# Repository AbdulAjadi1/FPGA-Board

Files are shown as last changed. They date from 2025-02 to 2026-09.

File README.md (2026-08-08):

# Custom Zynq FPGA Development Board

A custom-designed 8-layer FPGA development board based on the Xilinx Zynq-7000 SoC, featuring DDR3 memory, high-speed interfaces, and multi-rail power architecture. Designed from schematic through PCB layout and hardware bring-up.

---

<h2>🎥 FPGA Board Overview Demo</h2>
<a href="https://youtu.be/t4U1Dk0gFow">
  
</a>

<h2>🔬 Full DDR3 Bring-Up Walkthrough (Vivado → Vitis)</h2>
<a href="https://www.youtube.com/watch?v=clUkRelldes">
  
</a>

<h2>💾 QSPI Flash Bring-Up Demo</h2>
<a href="https://www.youtube.com/watch?v=BxZh9-KaFNE">
  
</a>

<h2>🔌 UART Using EMIO and DDR3 test</h2>
<a href="https://www.youtube.com/watch?v=delrs5nIDdQ">
  
</a>

---

<p align="center">
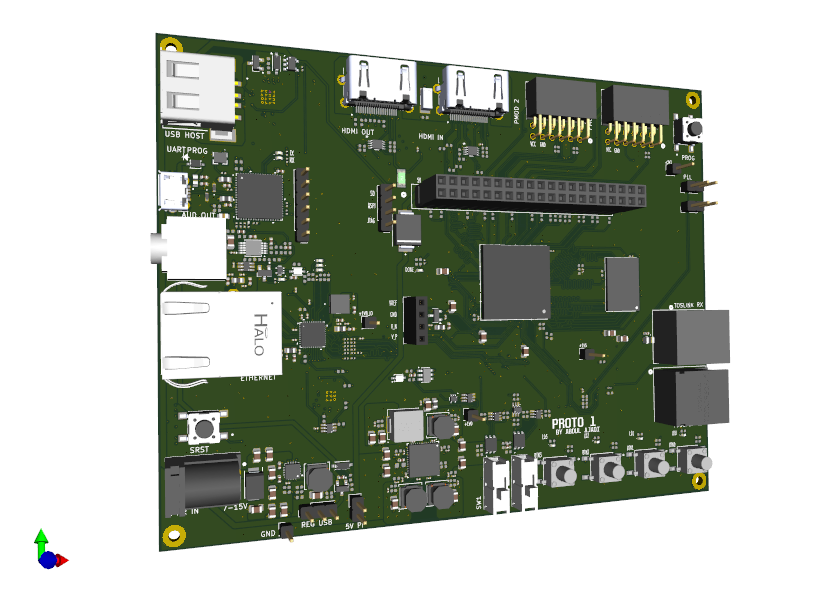
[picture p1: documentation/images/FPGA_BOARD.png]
FPGA Board 3D Render
  
</p>

**Custom Zynq-7000 FPGA Development Board**

**Overview**

This project is a custom FPGA development board inspired by the Digilent Arty Z7 platform, designed around the Xilinx Zynq-7000 SoC. The board serves as a general-purpose hardware development and learning platform, with an emphasis on FPGA and ARM (PS/PL) co-design, sound, power and signal-integrity practices, manufacturable industry-style PCB layout, and realistic interfaces commonly used in embedded and FPGA systems. The design is intended for advanced manufacturing and assembly at JLCPCB.

The project targets entry-level to junior FPGA and hardware engineering roles and focuses on demonstrating practical, board-level engineering decisions rather than a minimal breakout-style design.

**Project Status:**

## 🧪 Bring-Up & Validation

- ✅ DDR3 bring-up completed with successful memory test execution  
- ✅ QSPI flash configuration verified  
- ✅ FTDI USB-to-JTAG interface operational for programming and debug  
- ✅ Multi-rail power system validated 
- ✅ AXI GPIO controlling user LEDs and RGB LEDs confirmed  
- ✅ PS clocking and PLL configuration stable

**KEY FEATURES:**
- Xilinx Zynq-7000 SoC (Z7-20 / XC7Z020 class)
- DDR3 SDRAM (PS memory)
- HDMI interface (video output)
- Ethernet PHY (10/100/1000 Mbps)
- USB Host
- USB-JTAG interface
- SPDIF / TOSLINK interface
- QSPI Flash (boot storage)
- microSD card support
- PMOD / GPIO headers
- 40-pin Raspberry Pi interface
- On-board oscillators for PS and PL
- User LEDs, buttons, and switches
- Multi-rail power tree with switching regulators and LDOs

**DESIGN GOALS:**
- Follow Xilinx Zynq hardware design guidelines
- Implement correct decoupling, grounding, and plane usage
- Use controlled-impedance routing for high-speed interfaces
- Be compatible with low-cost PCB manufacturing and assembly
- Serve as a portfolio-quality hardware project

**HARDWARE ARCHITECTURE:**
- Zynq SoC
- ARM Cortex-A9 Processing System (PS)
- Programmable Logic (PL) fabric
- PS-to-PL interconnect exposed for custom designs
- Boot modes supported via QSPI / SD Memory
- DDR3 SDRAM connected to the PS:
- Length-matched address, control, and data groups
- Proper VREF routing and decoupling

**POWER TREE:**

**Input Sources:**

- 7-15V Barrel jack
- Raspberry pi 5V
- USB 5V

**Generated rails:**

- 1.0 V (FPGA core)

- 1.5 V (DDR3)

- 1.8 V (aux, IO)

- 3.3 V (IO and peripherals)

**PCB DESIGN DETAILS:**

- 8-layer PCB stackup

- Dedicated solid ground planeS

- Power planes for core rails

- Signal layers for controlled routing

- Thermal via stitching under FPGA ground regions

**Controlled impedance routing for:**

- DDR3 100Ω diff ±10%, 50Ω single ±10%

- HDMI 100Ω diff ±10%

- Ethernet  100Ω diff ±10%, 50Ω single ±10%

- USB 100Ω diff ±10%, 50Ω single ±10%

- SD  50Ω single ±10%

**INTENDED USE CASES:**

- FPGA and SoC learning platform

- PS/PL co-design experimentation

- HDL development and verification

- Embedded Linux bring-up (future work)

**TOOLS USED:**

- KiCad – schematic capture and PCB layout

- Xilinx Vivado – FPGA design and synthesis

- Vendor datasheets and Xilinx reference designs

- JLCPCB DFM/DFT tools

- JLCPCB Impedance calculator

**Author**

Designed and documented by Abdul Ajadi

Electronics / FPGA Hardware Engineer

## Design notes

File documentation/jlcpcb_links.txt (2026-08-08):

design for manufactiuring:
https://jlcdfm.com

impedance control calculator:
https://jlcpcb.com/pcb-impedance-calculator

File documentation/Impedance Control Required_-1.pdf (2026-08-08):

Impedance Control Required:

1) DDR3_CK_P / DDR3_CK_N
Type: Differential
Target: 100Ω ±10%
Layer: 8 (BCU)
Reference: Plane above L7(GND3)
2) DDR3_CKE0, DDR3_RAS, DDR3_BA1, DDR3_CAS Type: Single-ended
Target: 50Ω ±10%
Layer: 8 (BCU)
Reference: Plane above L7(GND3)
3) DDR3_A1, DDR3_A5, DDR3_A8, DDR3_CS, DDR3_RESET Type: Single-ended
Target: 50Ω ±10%
Layer: 1 (FCU)
Reference: Plane below L2(GND)
4) DDR3_A0, DDR3_A2, DDR3_A3, DDR3_A4, DDR3_A7, DDR3_A14 DDR3_BA0, DDR3_WE, DDR3_ODT0
Type: Single-ended
Target: 50Ω ±10%
Layer: 4 (SIGNAL)
Reference: Plane above L3 (PWR) and plane below L5 (GND2)
5) DDR3_A6, DDR3_A9, DDR3_A10, DDR3_A11, DDR3_A12, DDR3_A13, DDR3_BA2 Type: Single-ended
Target: 50Ω ±10%
Layer: 6 (SIGNAL2)
Reference: Plane above L5 (GND2) and plane below L7 (GND3)
6) DDR3_DQS0_P / DDR3_DQS0_N
Type: Differential
Target: 100Ω ±10%
Layer: 4 (SIGNAL)
Reference: Plane above L3 (PWR) and plane below L5 (GND2)

7) DDR3_D[0:4], DDR3_D6, DDR3_DM0 Type: Single-ended
Target: 50Ω ±10%
Layer: 8 (BCU)
Reference: Plane above L7(GND3)
8) DDR3_D5,DDR3_D7
Type: Single-ended
Target: 50Ω ±10%
Layer: 4 (SIGNAL)
Reference: Plane above L3 (PWR) and plane below L5 (GND2)
9) DDR3_DQS1_P / DDR3_DQS1_N
Type: Differential
Target: 100Ω ±10%
Layer: 4 (SIGNAL)
Reference: Plane above L3 (PWR) and plane below L5 (GND2)
10) DDR3_D[8:15], DDR3_DM1
Type: Single-ended
Target: 50Ω ±10%
Layer: 1 (FCU)
Reference: Plane below L2(GND)
11) HDMI_TX_D0_P / HDMI_TX_D0_N Type: Differential
Target: 100Ω ±10%
Layer: L6 (SIGNAL2)
Reference: Plane above L5 (GND2) and plane below L7 (GND3)
12) HDMI_TX_D1_P / HDMI_TX_D1_N
Type: Differential
Target: 100Ω ±10%
Layer: L8 (BCU)
Reference: Plane above L7(GND3)

13) HDMI_TX_D2_P / HDMI_TX_D2_N Type: Differential
Target: 100Ω ±10%
Layer: L6 (SIGNAL2)
Reference: Plane above L5 (GND2) and plane below L7 (GND3)
14) HDMI_TX_CLK_P / HDMI_TX_CLK_N
Type: Differential
Target: 100Ω ±10%
Layer: L6 (SIGNAL2)
Reference: Plane above L5 (GND2) and plane below L7 (GND3)
15) HDMI_RX_D0_P / HDMI_RX_D0_N
Type: Differential
Target: 100Ω ±10%
Layer: L1 (FCU)
Reference: Plane below L2(GND)
16) HDMI_RX_D1_P / HDMI_RX_D1_N Type: Differential
Target: 100Ω ±10%
Layer: L1 (FCU)
Reference: Plane below L2(GND)
17) HDMI_RX_D2_P / HDMI_RX_D2_N Type: Differential
Target: 100Ω ±10%
Layer: L1 (FCU)
Reference: Plane below L2(GND)
18) HDMI_RX_CLK_P / HDMI_RX_CLK_N Type: Differential
Target: 100Ω ±10%
Layer: L8 (BCU)
Reference: Plane above L7(GND3)

19) ETH_TD0_P / ETH_TD0_N
Type: Differential
Target: 100Ω ±10%
Layer: L1 (FCU)
Reference: Plane below L2(GND)
20) ETH_TD1_P / ETH_TD1_N
Type: Differential
Target: 100Ω ±10%
Layer: L1 (FCU)
Reference: Plane below L2(GND)
21) ETH_TD2_P / ETH_TD2_N
Type: Differential
Target: 100Ω ±10%
Layer: L1 (FCU)
Reference: Plane below L2(GND)
22) ETH_TD3_P / ETH_TD3_N
Type: Differential
Target: 100Ω ±10%
Layer: L1 (FCU)
Reference: Plane below L2(GND)
23) USBHOST_P / USBHOST_N
Type: Differential
Target: 100Ω ±10%
Layer: L1 (FCU)
Reference: Plane below L2(GND)
24) USBHOST_P / USBHOST_N
Type: Differential
Target: 100Ω ±10%
Layer: L8 (BCU)
Reference: Plane above L7(GND3)
24) USB_FTDI_D_P/ USB_FTDI_D_N Type: Differential
Target: 100Ω ±10%
Layer: L1 (FCU)
Reference: Plane below L2(GND)

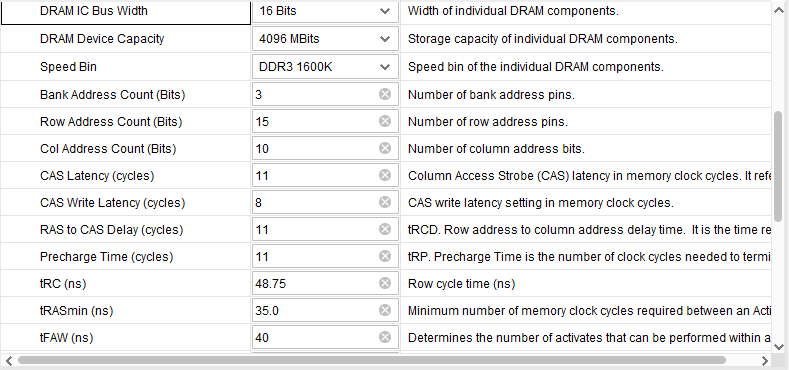
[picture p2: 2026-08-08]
documentation/ddr1.png

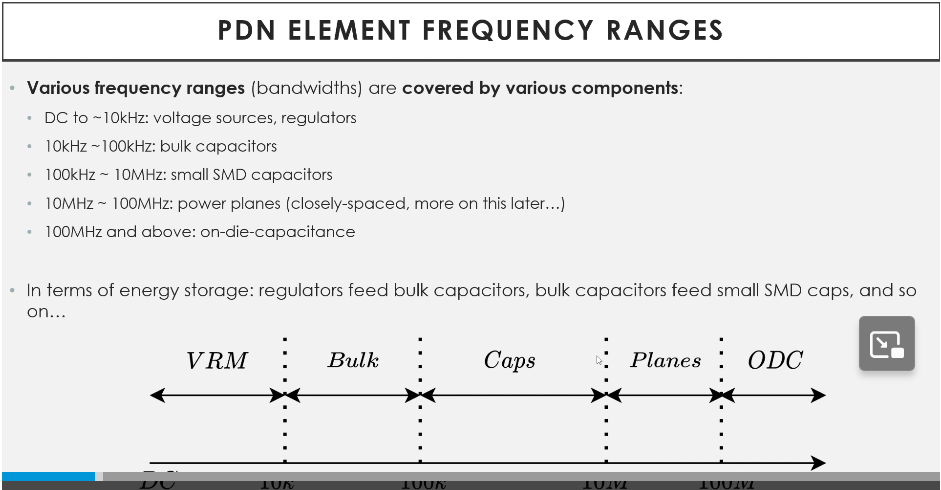
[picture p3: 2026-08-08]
documentation/pdn_delivery_range.png

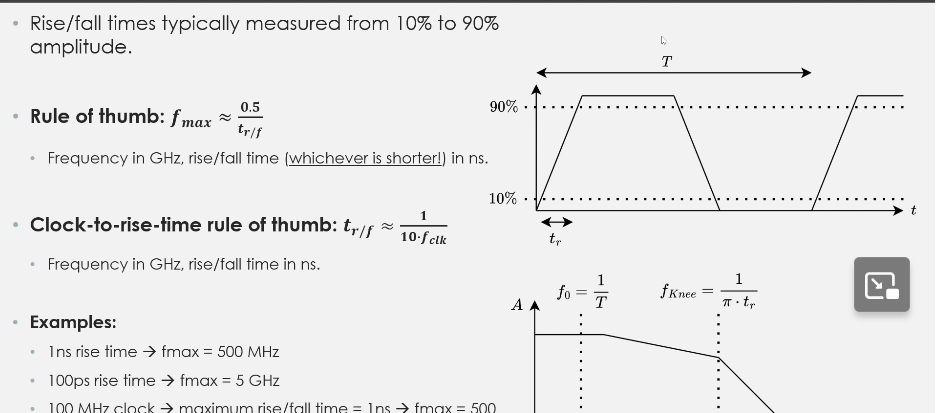
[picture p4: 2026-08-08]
documentation/max_freq_content.png

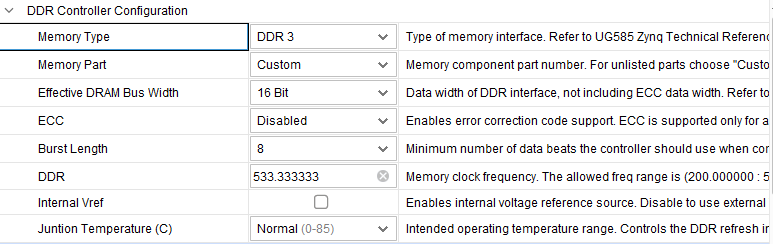
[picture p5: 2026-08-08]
documentation/ddr2.png

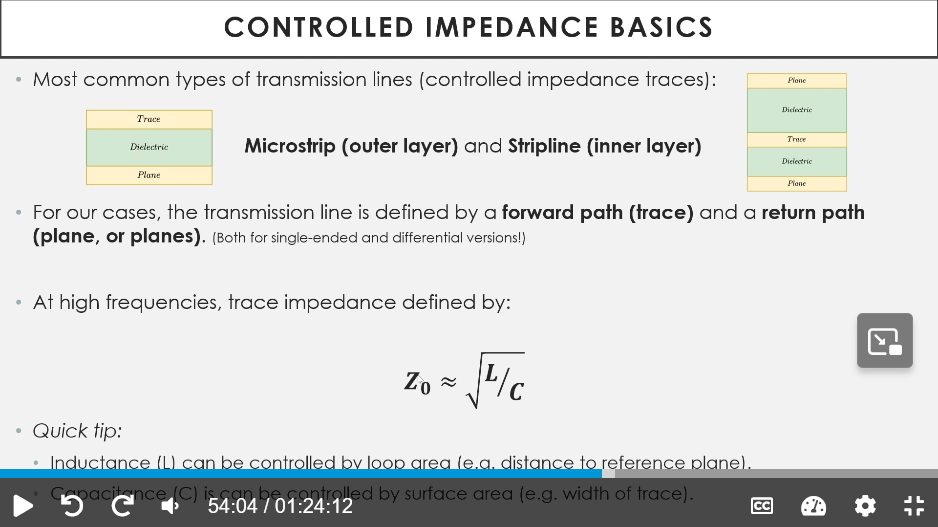
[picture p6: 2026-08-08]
documentation/controlled_impedance_basics.png

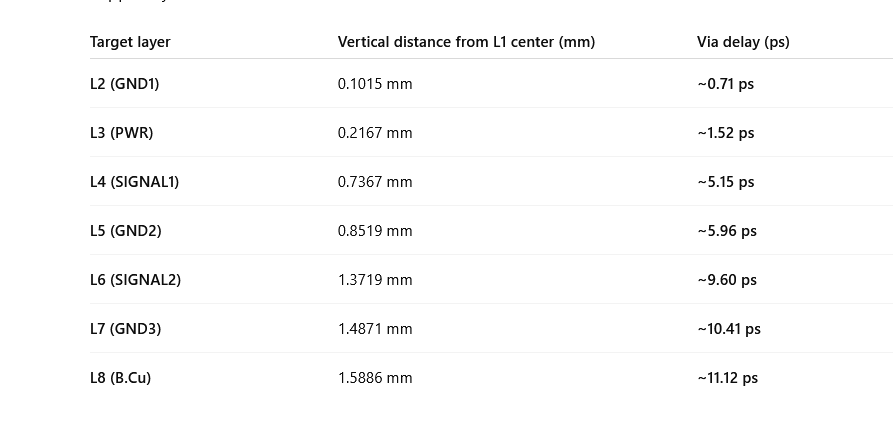
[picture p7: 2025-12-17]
documentation/via_delay.png

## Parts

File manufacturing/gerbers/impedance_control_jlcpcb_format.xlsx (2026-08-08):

Signal Layer | Reference Layer | Impedance Type | Trace Width（mil) | Trace Spacing（mil) | Impedance(ohm)±10% | Position
L8 (BCU) | Plane above L7 (GND3) |  | 4.11 | 9.84 | 100 | DDR3_CK_P
L8 (BCU) | Plane above L7 (GND3) | Differential Pair | 4.11 | 9.84 | 100 | DDR3_CK_N
L8 (BCU) | Plane above L7 (GND3) | Single-ended | 4.66 |  | 50 | DDR3_CKE0
L8 (BCU) | Plane above L7 (GND3) | Single-ended | 4.66 |  | 50 | DDR3_RAS
L8 (BCU) | Plane above L7 (GND3) | Single-ended | 4.66 |  | 50 | DDR3_BA1
L8 (BCU) | Plane above L7 (GND3) | Single-ended | 4.66 |  | 50 | DDR3_CAS
L1 (FCU) | Plane below L2 (GND) | Single-ended | 4.66 |  | 50 | DDR3_A1
L1 (FCU) | Plane below L2 (GND) | Single-ended | 4.66 |  | 50 | DDR3_A5
L1 (FCU) | Plane below L2 (GND) | Single-ended | 4.66 |  | 50 | DDR3_A8
L1 (FCU) | Plane below L2 (GND) | Single-ended | 4.66 |  | 50 | DDR3_CS
L1 (FCU) | Plane below L2 (GND) | Single-ended | 4.66 |  | 50 | DDR3_RESET
L4 (SIGNAL) | Plane above L3 (PWR) and plane below L5 (GND2) | Single-ended | 5.04 |  | 50 | DDR3_A0
L4 (SIGNAL) | Plane above L3 (PWR) and plane below L5 (GND2) | Single-ended | 5.04 |  | 50 | DDR3_A2
L4 (SIGNAL) | Plane above L3 (PWR) and plane below L5 (GND2) | Single-ended | 5.04 |  | 50 | DDR3_A3
L4 (SIGNAL) | Plane above L3 (PWR) and plane below L5 (GND2) | Single-ended | 5.04 |  | 50 | DDR3_A4
L4 (SIGNAL) | Plane above L3 (PWR) and plane below L5 (GND2) | Single-ended | 5.04 |  | 50 | DDR3_A7
L4 (SIGNAL) | Plane above L3 (PWR) and plane below L5 (GND2) | Single-ended | 5.04 |  | 50 | DDR3_A14
L4 (SIGNAL) | Plane above L3 (PWR) and plane below L5 (GND2) | Single-ended | 5.04 |  | 50 | DDR3_BA0
L4 (SIGNAL) | Plane above L3 (PWR) and plane below L5 (GND2) | Single-ended | 5.04 |  | 50 | DDR3_WE
L4 (SIGNAL) | Plane above L3 (PWR) and plane below L5 (GND2) | Single-ended | 5.04 |  | 50 | DDR3_ODT0
L6 (SIGNAL2) | Plane above L5 (GND2) and plane below L7 (GND3) | Single-ended | 4.97 |  | 50 | DDR3_A6
L6 (SIGNAL2) | Plane above L5 (GND2) and plane below L7 (GND3) | Single-ended | 4.97 |  | 50 | DDR3_A9
L6 (SIGNAL2) | Plane above L5 (GND2) and plane below L7 (GND3) | Single-ended | 4.97 |  | 50 | DDR3_A10
L6 (SIGNAL2) | Plane above L5 (GND2) and plane below L7 (GND3) | Single-ended | 4.97 |  | 50 | DDR3_A11
L6 (SIGNAL2) | Plane above L5 (GND2) and plane below L7 (GND3) | Single-ended | 4.97 |  | 50 | DDR3_A12
L6 (SIGNAL2) | Plane above L5 (GND2) and plane below L7 (GND3) | Single-ended | 4.97 |  | 50 | DDR3_A13
L6 (SIGNAL2) | Plane above L5 (GND2) and plane below L7 (GND3) | Single-ended | 4.97 |  | 50 | DDR3_BA2
L4 (SIGNAL) | Plane above L3 (PWR) and plane below L5 (GND2) | Differential Pair | 4.05 | 8 | 100 | DDR3_DQS0_P
L4 (SIGNAL) | Plane above L3 (PWR) and plane below L5 (GND2) | Differential Pair | 4.05 | 8 | 100 | DDR3_DQS0_N
L8 (BCU) | Plane above L7 (GND3) | Single-ended | 4.66 |  | 50 | DDR3_D0
L8 (BCU) | Plane above L7 (GND3) | Single-ended | 4.66 |  | 50 | DDR3_D1
L8 (BCU) | Plane above L7 (GND3) | Single-ended | 4.66 |  | 50 | DDR3_D2
L8 (BCU) | Plane above L7 (GND3) | Single-ended | 4.66 |  | 50 | DDR3_D3
L8 (BCU) | Plane above L7 (GND3) | Single-ended | 4.66 |  | 50 | DDR3_D4
L8 (BCU) | Plane above L7 (GND3) | Single-ended | 4.66 |  | 50 | DDR3_D6
L8 (BCU) | Plane above L7 (GND3) | Single-ended | 4.66 |  | 50 | DDR3_DM0
L4 (SIGNAL) | Plane above L3 (PWR) and plane below L5 (GND2) | Single-ended | 5.04 |  | 50 | DDR3_D5
L4 (SIGNAL) | Plane above L3 (PWR) and plane below L5 (GND2) | Single-ended | 5.04 |  | 50 | DDR3_D7
L4 (SIGNAL) | Plane above L3 (PWR) and plane below L5 (GND2) | Differential Pair | 4.05 | 8 | 100 | DDR3_DQS1_P
L4 (SIGNAL) | Plane above L3 (PWR) and plane below L5 (GND2) | Differential Pair | 4.05 | 8 | 100 | DDR3_DQS1_N
L1 (FCU) | Plane below L2 (GND) | Single-ended | 4.66 |  | 50 | DDR3_D8
L1 (FCU) | Plane below L2 (GND) | Single-ended | 4.66 |  | 50 | DDR3_D9
L1 (FCU) | Plane below L2 (GND) | Single-ended | 4.66 |  | 50 | DDR3_D10
L1 (FCU) | Plane below L2 (GND) | Single-ended | 4.66 |  | 50 | DDR3_D11
L1 (FCU) | Plane below L2 (GND) | Single-ended | 4.66 |  | 50 | DDR3_D12
L1 (FCU) | Plane below L2 (GND) | Single-ended | 4.66 |  | 50 | DDR3_D13
L1 (FCU) | Plane below L2 (GND) | Single-ended | 4.66 |  | 50 | DDR3_D14
L1 (FCU) | Plane below L2 (GND) | Single-ended | 4.66 |  | 50 | DDR3_D15
L1 (FCU) | Plane below L2 (GND) | Single-ended | 4.66 |  | 50 | DDR3_DM1
L6 (SIGNAL2) | Plane above L5 (GND2) and plane below L7 (GND3) | Differential Pair | 4.05 | 8 | 100 | HDMI_TX_D0_P
L6 (SIGNAL2) | Plane above L5 (GND2) and plane below L7 (GND3) | Differential Pair | 4.05 | 8 | 100 | HDMI_TX_D0_N
L8 (BCU) | Plane above L7 (GND3) | Differential Pair | 4.11 | 9.84 | 100 | HDMI_TX_D1_P
L8 (BCU) | Plane above L7 (GND3) | Differential Pair | 4.11 | 9.84 | 100 | HDMI_TX_D1_N
L6 (SIGNAL2) | Plane above L5 (GND2) and plane below L7 (GND3) | Differential Pair | 4.05 | 8 | 100 | HDMI_TX_D2_P
L6 (SIGNAL2) | Plane above L5 (GND2) and plane below L7 (GND3) | Differential Pair | 4.05 | 8 | 100 | HDMI_TX_D2_N
L6 (SIGNAL2) | Plane above L5 (GND2) and plane below L7 (GND3) | Differential Pair | 4.05 | 8 | 100 | HDMI_TX_CLK_P
L6 (SIGNAL2) | Plane above L5 (GND2) and plane below L7 (GND3) | Differential Pair | 4.05 | 8 | 100 | HDMI_TX_CLK_N
L1 (FCU) | Plane below L2 (GND) | Differential Pair | 4.11 | 9.84 | 100 | HDMI_RX_D0_P
L1 (FCU) | Plane below L2 (GND) | Differential Pair | 4.11 | 9.84 | 100 | HDMI_RX_D0_N
L1 (FCU) | Plane below L2 (GND) | Differential Pair | 4.11 | 9.84 | 100 | HDMI_RX_D1_P
L1 (FCU) | Plane below L2 (GND) | Differential Pair | 4.11 | 9.84 | 100 | HDMI_RX_D1_N
L1 (FCU) | Plane below L2 (GND) | Differential Pair | 4.11 | 9.84 | 100 | HDMI_RX_D2_P
L1 (FCU) | Plane below L2 (GND) | Differential Pair | 4.11 | 9.84 | 100 | HDMI_RX_D2_N
L8 (BCU) | Plane above L7 (GND3) | Differential Pair | 4.11 | 9.84 | 100 | HDMI_RX_CLK_P
L8 (BCU) | Plane above L7 (GND3) | Differential Pair | 4.11 | 9.84 | 100 | HDMI_RX_CLK_N
L1 (FCU) | Plane below L2 (GND) | Differential Pair | 4.11 | 9.84 | 100 | ETH_TD0_P
L1 (FCU) | Plane below L2 (GND) | Differential Pair | 4.11 | 9.84 | 100 | ETH_TD0_N
L1 (FCU) | Plane below L2 (GND) | Differential Pair | 4.11 | 9.84 | 100 | ETH_TD1_P/ETH_TD1_N
L8 (BCU) | Plane above L7 (GND3) | Differential Pair | 4.11 | 9.84 | 100 | ETH_TD1_P/ETH_TD1_N
L1 (FCU) | Plane below L2 (GND) | Differential Pair | 4.11 | 9.84 | 100 | ETH_TD2_P
L1 (FCU) | Plane below L2 (GND) | Differential Pair | 4.11 | 9.84 | 100 | ETH_TD2_N
L1 (FCU) | Plane below L2 (GND) | Differential Pair | 4.11 | 9.84 | 100 | ETH_TD3_P
L1 (FCU) | Plane below L2 (GND) | Differential Pair | 4.11 | 9.84 | 100 | ETH_TD3_N
L1 (FCU) | Plane below L2 (GND) | Differential Pair | 4.11 | 9.84 | 100 | USBHOST_P
L1 (FCU) | Plane below L2 (GND) | Differential Pair | 4.11 | 9.84 | 100 | USBHOST_N
L8 (BCU) | Plane above L7 (GND3) | Differential Pair | 4.11 | 9.84 | 100 | USBHOST_P
L8 (BCU) | Plane above L7 (GND3) | Differential Pair | 4.11 | 9.84 | 100 | USBHOST_N
L1 (FCU) | Plane below L2 (GND) | Differential Pair | 4.11 | 9.84 | 100 | USB_FTDI_D_P
L1 (FCU) | Plane below L2 (GND) | Differential Pair | 4.11 | 9.84 | 100 | USB_FTDI_D_N

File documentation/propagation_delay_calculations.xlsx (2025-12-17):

Target layer | Vertical distance from L1 center (mm) | Via delay (ps) | microstrip delay(ps/mm) | stripline delay(ps/mm)
L2 (GND1) | 0.1015 mm | 0.71 | 5.8 | 7.1 | length DQS1 (mm) | length ddr3_d8-d15(all layer 1 fcu) (mm) | length DQS0 (mm) | length ddr3_d0-7(layer 4) (mm)
L3 (PWR) | 0.2167 mm | 1.52 |  |  | 23.6595 | 30.73835345 | 29.8487 | 29.8487
L4 (SIGNAL1) | 0.7367 mm | 5.15 |  |  | total delay (ps) |  | total delay (ps) | length ddr3_d0-7(layer 8) (mm)
L5 (GND2) | 0.8519 mm | 5.96 |  |  | 178.28245 |  | 222.22577 | 34.48030517
L6 (SIGNAL2) | 1.3719 mm | 9.6
L7 (GND3) | 1.4871 mm | 10.41
L8 (B.Cu) | 1.5886 mm | 11.12 |  |  | length master ck (mm) | length ACC Layer 1(mm)
 |  |  |  |  | 44.9243 | 48.75878276
 |  |  |  |  | total delay (ps) | length ACC Layer 4(mm)
 |  |  |  |  | 282.80094 | 38.38041408
 |  |  |  |  |  | length ACC Layer 6(mm)
 |  |  |  |  |  | 37.12689296
 |  |  |  |  |  | length ACC Layer 8(mm)
 |  |  |  |  |  | 44.9243

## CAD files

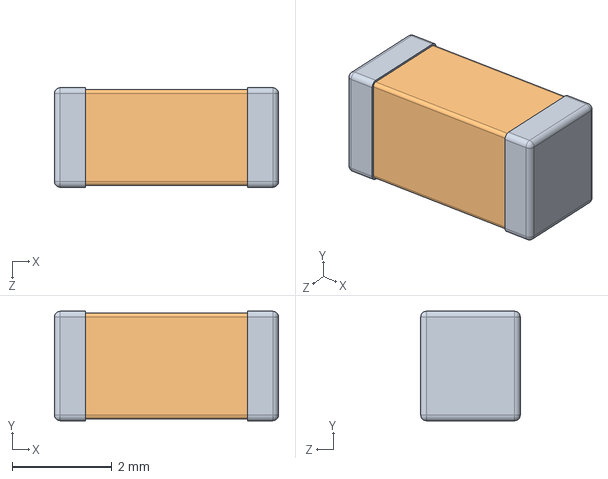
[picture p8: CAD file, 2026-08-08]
3dmodels/GA342DR7GF102KW02L.step
4.50 x 2.20 x 2.00 mm

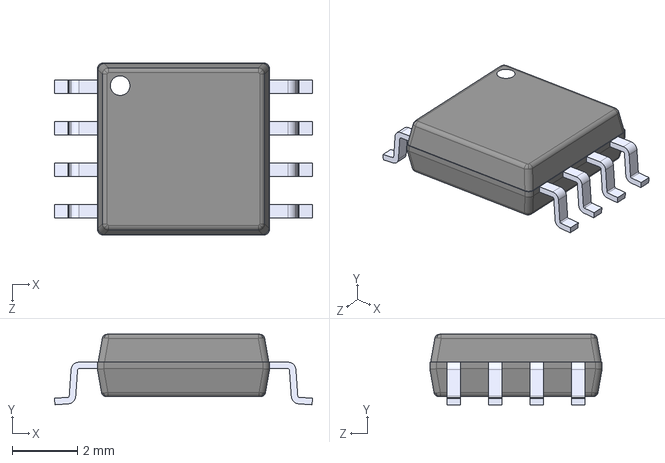
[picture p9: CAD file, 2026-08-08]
3dmodels/W25Q128JVSIQ.step
7.90 x 2.16 x 5.28 mm

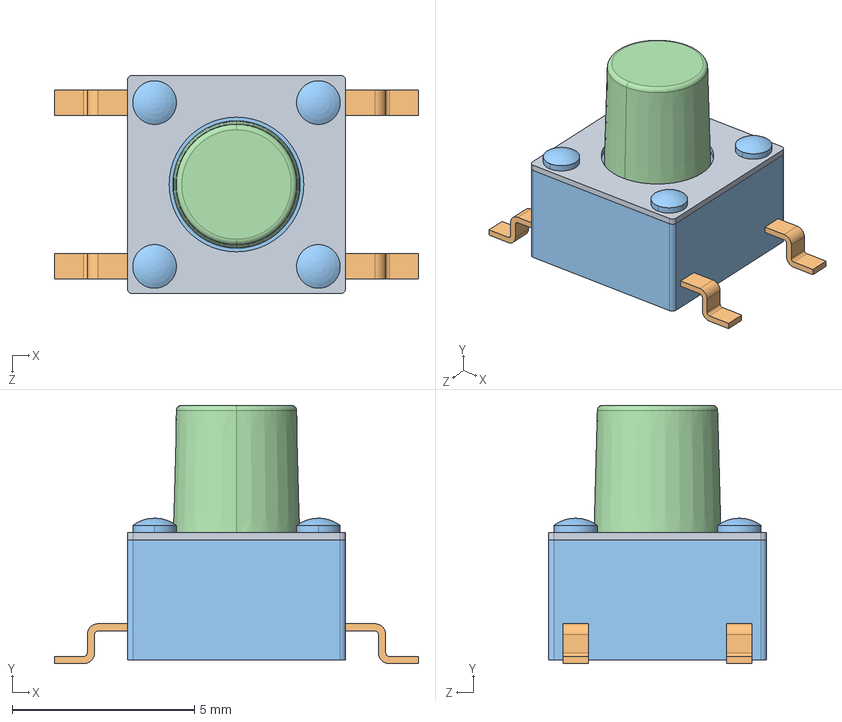
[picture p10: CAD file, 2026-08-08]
3dmodels/Same_Sky_TS04-66-70-BK-100-SMT.step
10.0 x 7.10 x 6.00 mm

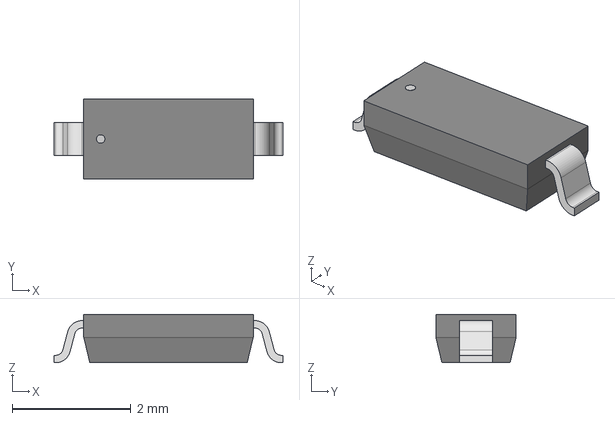
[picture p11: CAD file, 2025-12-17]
3dmodels/SOD123_DIO.step
3.85 x 1.35 x 0.815 mm

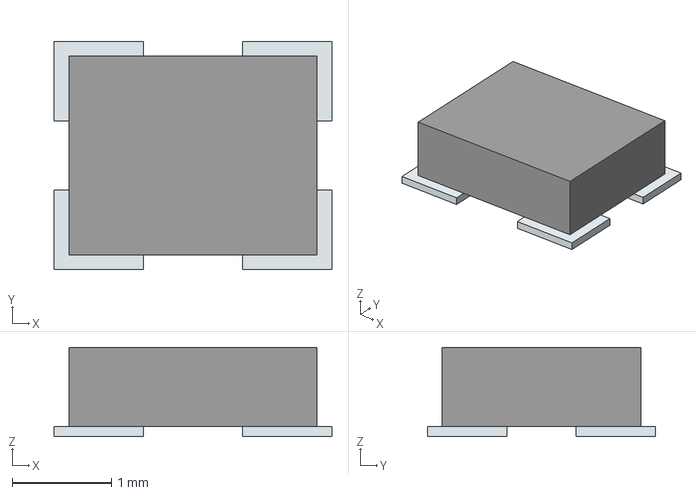
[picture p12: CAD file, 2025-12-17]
3dmodels/SIT1602AC-12-33E-12.000000G.stp
2.80 x 2.30 x 0.9 mm
Pins

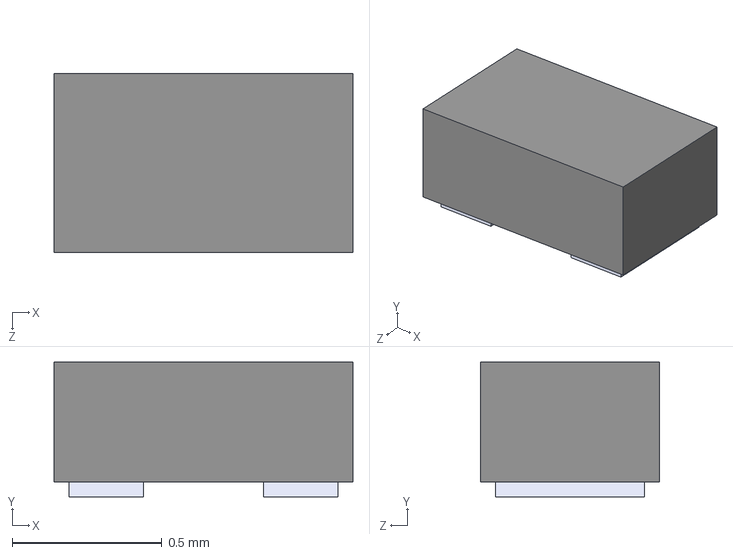
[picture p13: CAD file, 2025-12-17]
3dmodels/TPD1E05U06DPYR.step
1.00 x 0.45 x 0.6 mm

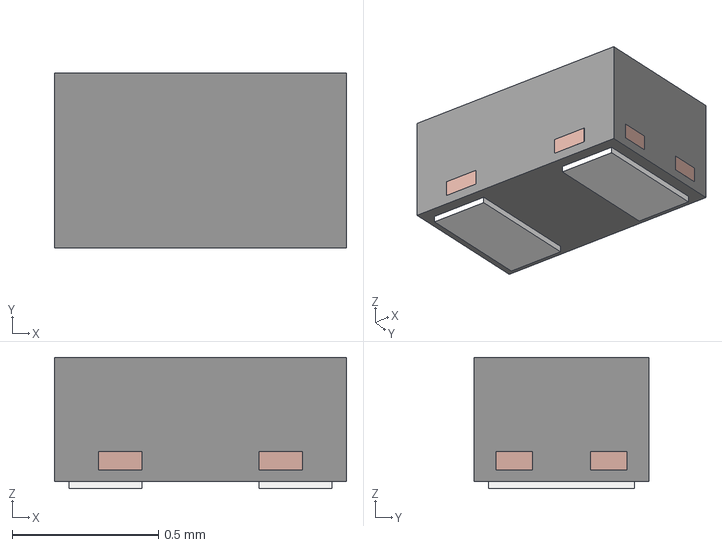
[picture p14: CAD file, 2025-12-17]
3dmodels/DPY0002A.stp
1.00 x 0.6 x 0.45 mm
BODY-SON
FRAME-DPY0002A

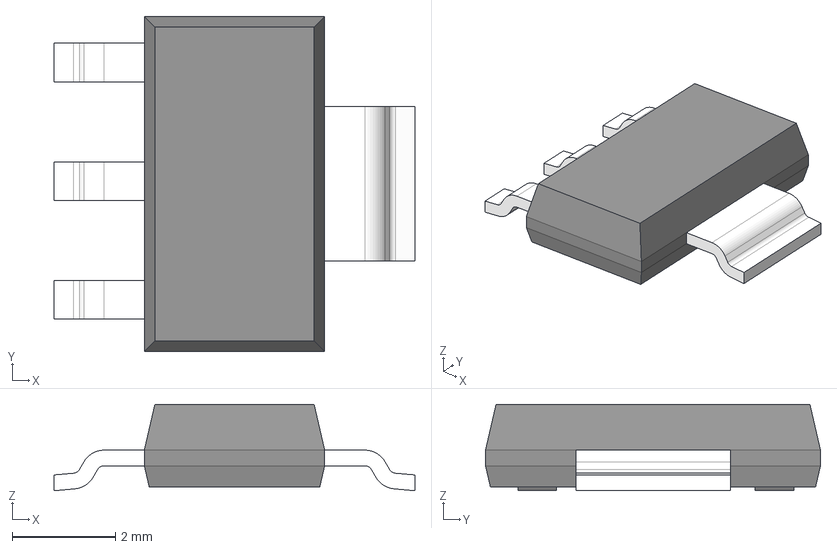
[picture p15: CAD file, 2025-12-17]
3dmodels/DCY0004A.stp
7.00 x 6.50 x 1.68 mm
BODY-SOT
LEAD-SOT x 3
LEAD-SOT-WIDE
PIN1-ID

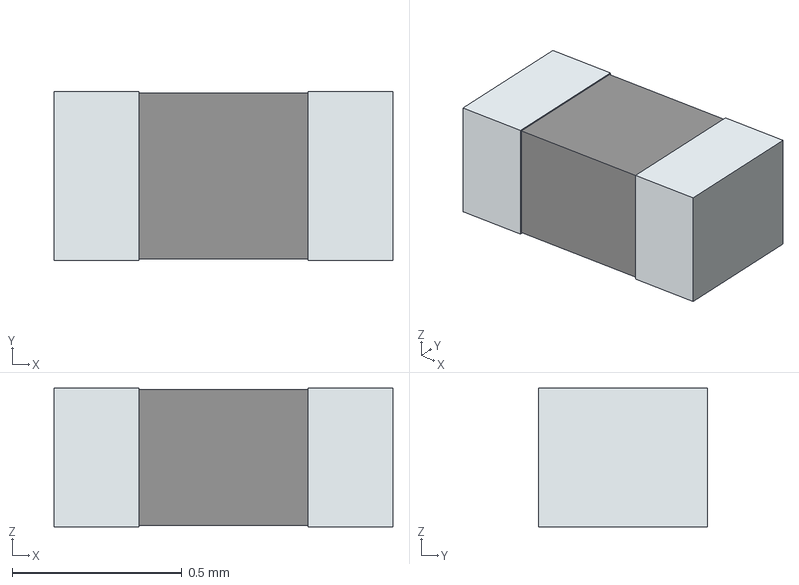
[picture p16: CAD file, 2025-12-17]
3dmodels/CG0402MLU-3.3G.stp
1.00 x 0.5 x 0.41 mm
term1
term2

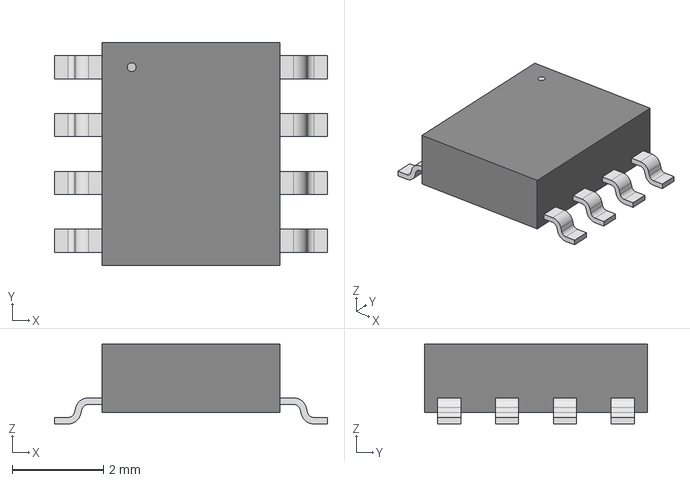
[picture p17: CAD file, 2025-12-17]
3dmodels/SOIC8-N_MC_MCH.step
5.99 x 4.90 x 1.75 mm

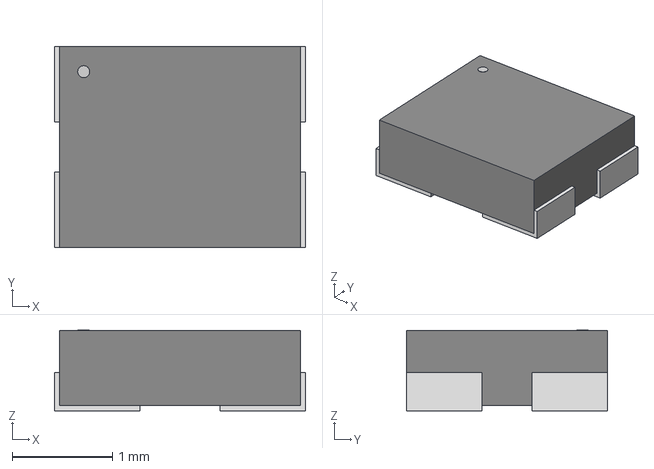
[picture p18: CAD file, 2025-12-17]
3dmodels/SON4_CS00119_SIT.step
2.50 x 2.00 x 0.803 mm

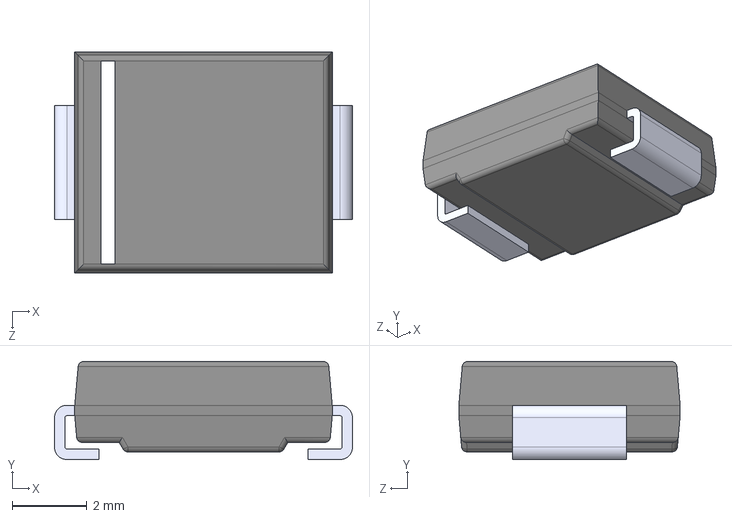
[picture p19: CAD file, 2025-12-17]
3dmodels/MBRS340T3G.step
7.95 x 2.62 x 5.91 mm

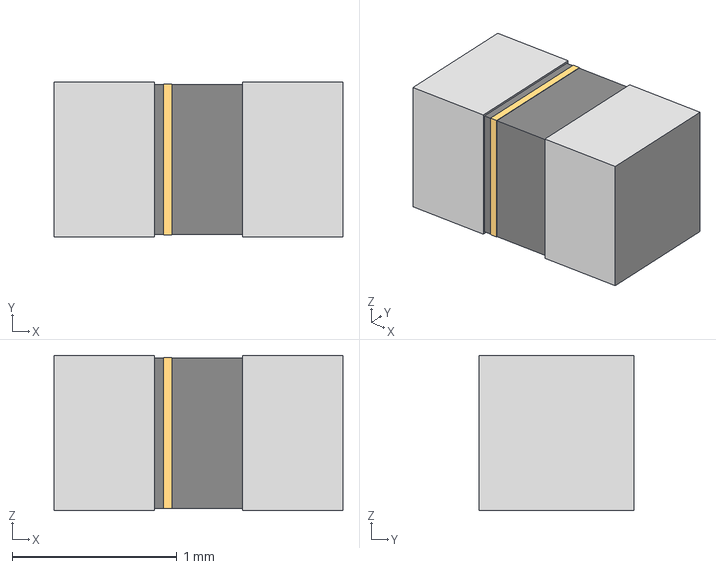
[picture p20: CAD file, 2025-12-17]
3dmodels/IND_BLM18_0603_MUR.step
1.75 x 0.94 x 0.94 mm

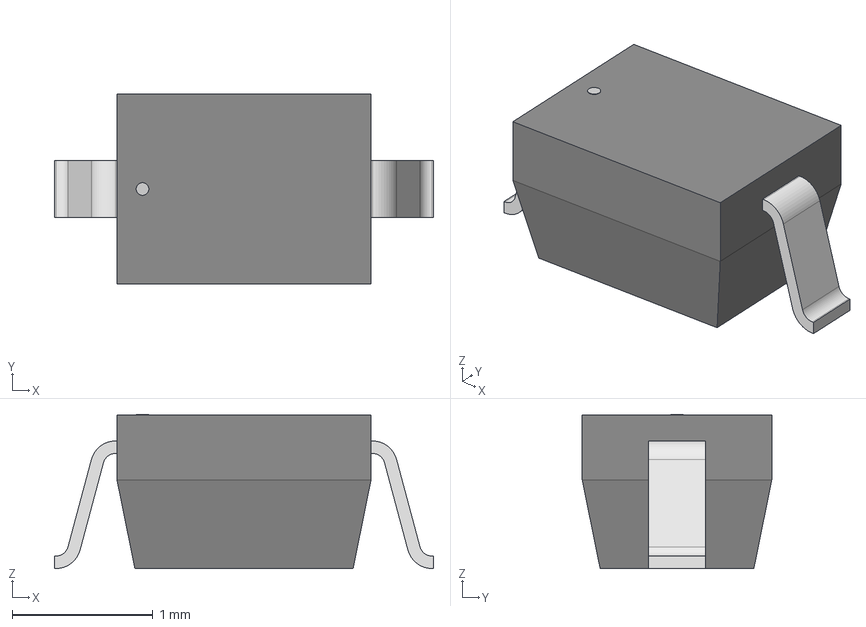
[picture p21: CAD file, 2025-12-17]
3dmodels/SOD323F_NXP.step
2.69 x 1.35 x 1.09 mm

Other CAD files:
3dmodels/ECS-2520MV-120-BN-TR.step
3dmodels/cg0402mlu.stp
3dmodels/C_0201_0603Metric.step
3dmodels/10029449-001RLF.step
3dmodels/10118194-0001LF.step
3dmodels/503398-1892.step
3dmodels/64QFN_FT2232HQ_FTD.step
3dmodels/7764013.stp
3dmodels/ABMM-25.000MHZ-B2-T.step
3dmodels/ABMM-25.000MHZ-B2-T.stp
3dmodels/BAS16XV2T1G.step
3dmodels/BEADC1608X95N.step
3dmodels/BSS214NH6327XTSA1.stp
3dmodels/CLG400_ZYNQ-7000_AMD.step
3dmodels/CRYSTAL_TXC_7M.step
3dmodels/CR_050R3C2P_AVX.step
3dmodels/C_0402.step
3dmodels/C_0805_2012Metric.step
3dmodels/C_1210_3225Metric.step
3dmodels/C_1808_4520Metric.step
3dmodels/DBV0006A.stp
3dmodels/DBZ0003A.stp
3dmodels/DCU0008A.stp
3dmodels/DMG2305UX-13.step
3dmodels/EG1218.step
3dmodels/FDV301N.step
3dmodels/FUSE_PRG-18_MUR.step
3dmodels/HFJ11-1G01ERL.stp
3dmodels/IND_BOURNS_SRN4018.step
3dmodels/IND_SMDRI_SXN.step
3dmodels/IND_SRP4020_BRN.step
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

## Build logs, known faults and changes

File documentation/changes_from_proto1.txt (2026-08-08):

1. feedback signals from PDN
2. PS oscillator moves top layer
3. ESD diodes for udb FTDI closer to connector
4. pin1 marker on silscreen for fpga
5. system reset silkscreen fixed from PROG to PORB
6. moved pgood led closer to power section.
7. swapped uart pins from ps to ftdi and followed vck190 schematic implementation
8. shaved off bottom and top of pcb. reducing by about 10mm
9. oscillators decoupling caps moved to power pin not OE pin
10. mode boot selector switch closer to qspi flash ic

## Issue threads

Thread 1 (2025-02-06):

FPGA reference design XC7Z020-2CLG484I

AbdulAjadi1, 2025-02-06:
Research for reference designs for the FPGA we will be utilizing in our development board. git hub should be a good starting point

FPGA link:
https://www.lcsc.com/product-detail/Programmable-Logic-Device-CPLDs-FPGAs_AMD-XILINX-XC7Z020-2CLG484I_C157624.html
FPGA footprint:
https://www.digikey.ca/en/models/3925763

AbdulAjadi1, 2025-02-09:
https://github.com/alinxalinx/AX7021B_2023.1

Above is a github repository containing a reference design for a dev board utilizing the fpga of interest XILINX-XC7Z020

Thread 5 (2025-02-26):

Add HDMI IN / OUT Schematic (arty model)

AbdulAjadi1, 2025-02-26:
Implement HDMI IN/OUT schematic into FPGA-board project on kicad following arty board model.

[P04.arty_z7_sch.pdf](https://github.com/user-attachments/files/18975287/P04.arty_z7_sch.pdf)

Closed 2025-04-11.

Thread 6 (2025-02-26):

Add JTAG and Flash/eMMc into Schematic (arty model)

AbdulAjadi1, 2025-02-26:
Implement JTAG and Flash/eMMc schematic into FPGA-board project on kicad following arty board model.

[P07.arty_z7_sch.pdf](https://github.com/user-attachments/files/18975297/P07.arty_z7_sch.pdf)

Closed 2025-04-11.

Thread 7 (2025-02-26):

Add  PMOD , LED,  Switches, SPDIF in/out and i2s to toslink schematic (arty model)

AbdulAjadi1, 2025-02-26:
Implement PMOD , LED,  Switches, SPDIF in/out and i2s to toslink schematic into FPGA-board project on kicad following arty board model.

[P01.arty_z7_sch.pdf](https://github.com/user-attachments/files/18975329/P01.arty_z7_sch.pdf)

Closed 2025-04-11.

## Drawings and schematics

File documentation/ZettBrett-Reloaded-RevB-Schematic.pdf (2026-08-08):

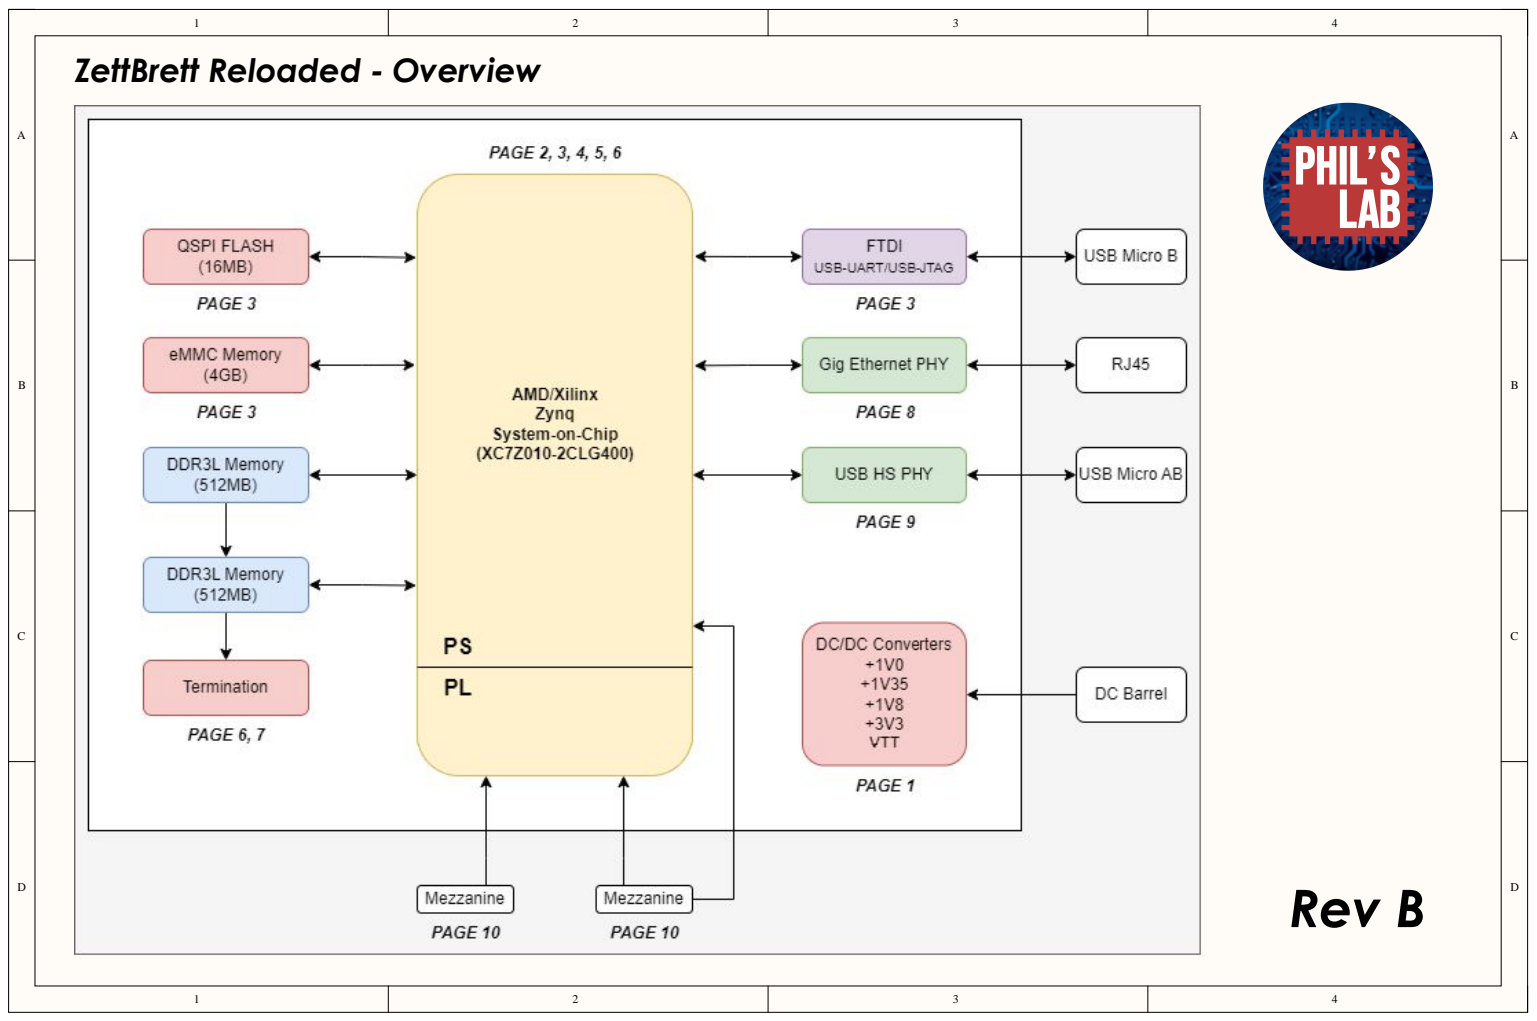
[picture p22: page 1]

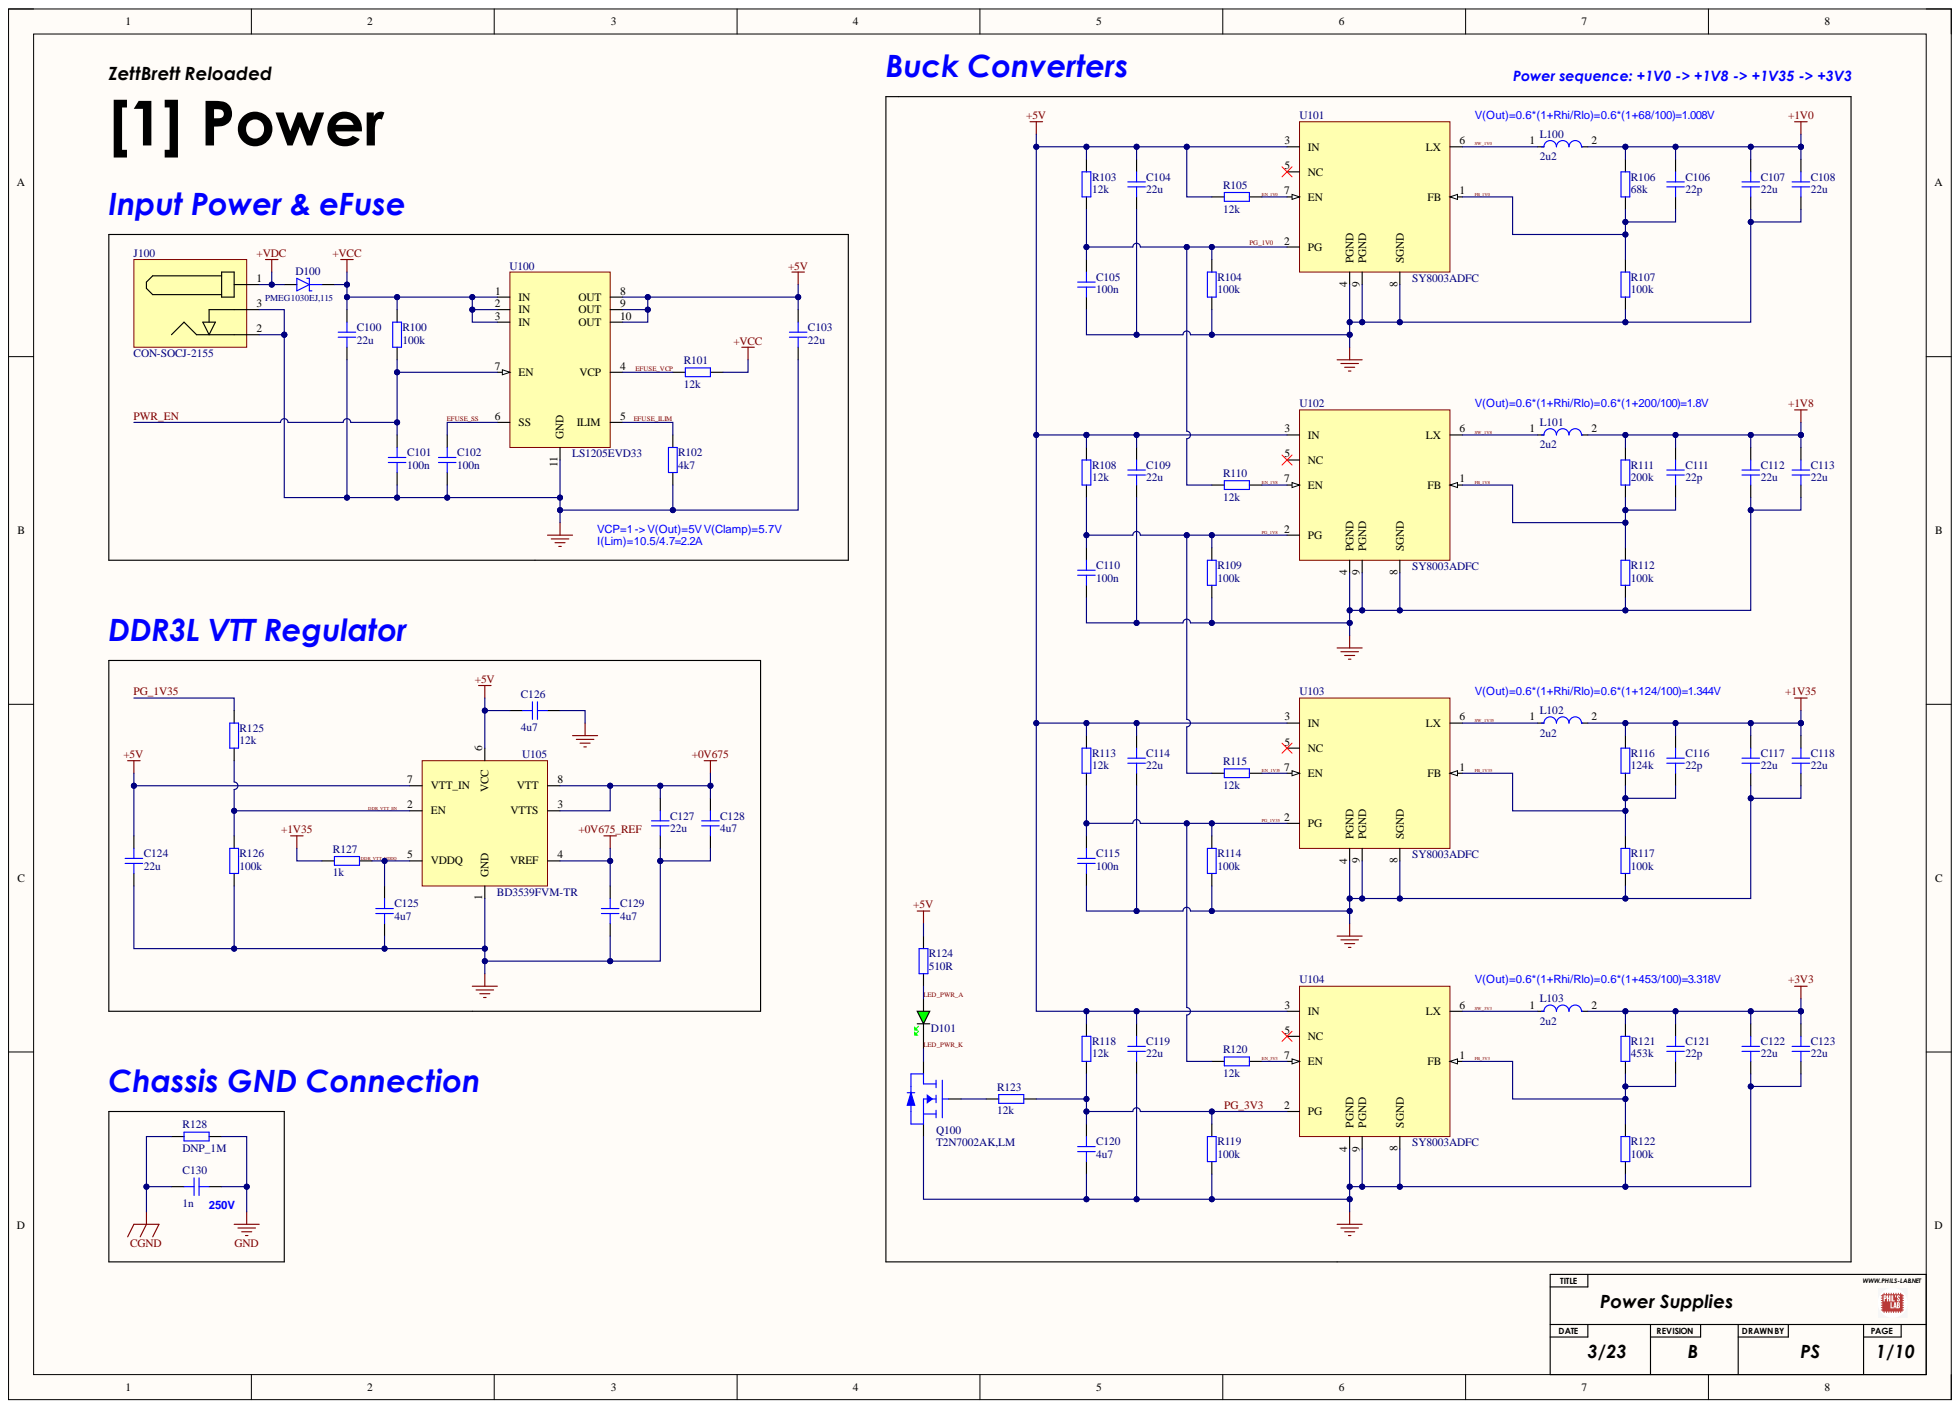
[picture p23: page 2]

WWW.PHILS-LAB.NET

DATE | 3/23 | REVISION | DRAWN BY | PS | PAGE
B | | | 1/10

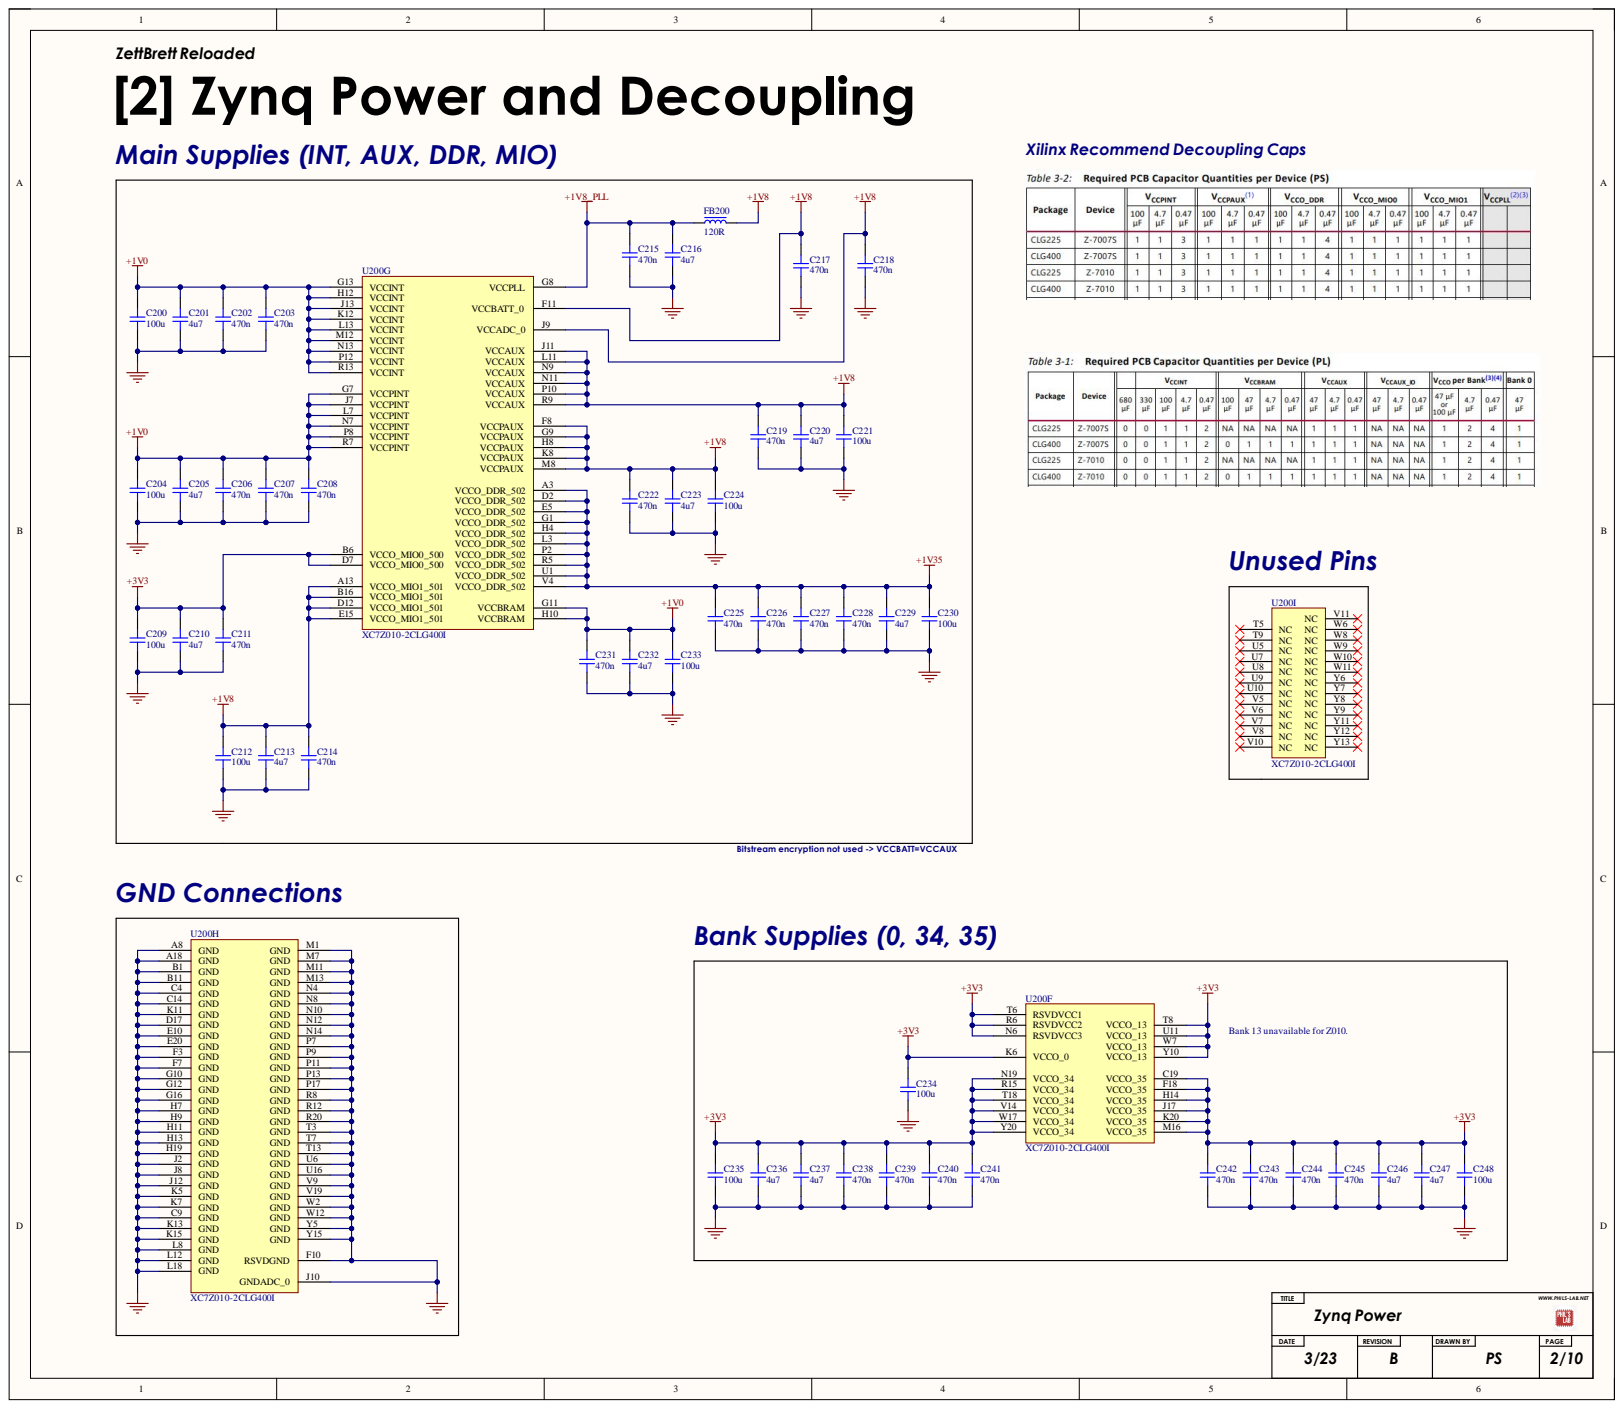
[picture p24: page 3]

[2] Zynq Power and Decoupling

Main Supplies (INT, AUX, DDR, MIO)

Xilinx Recommend Decoupling Caps

Bitstream encryption not used -> VCCBATT=VCCAUX

WWW.PHILS-LAB.NET

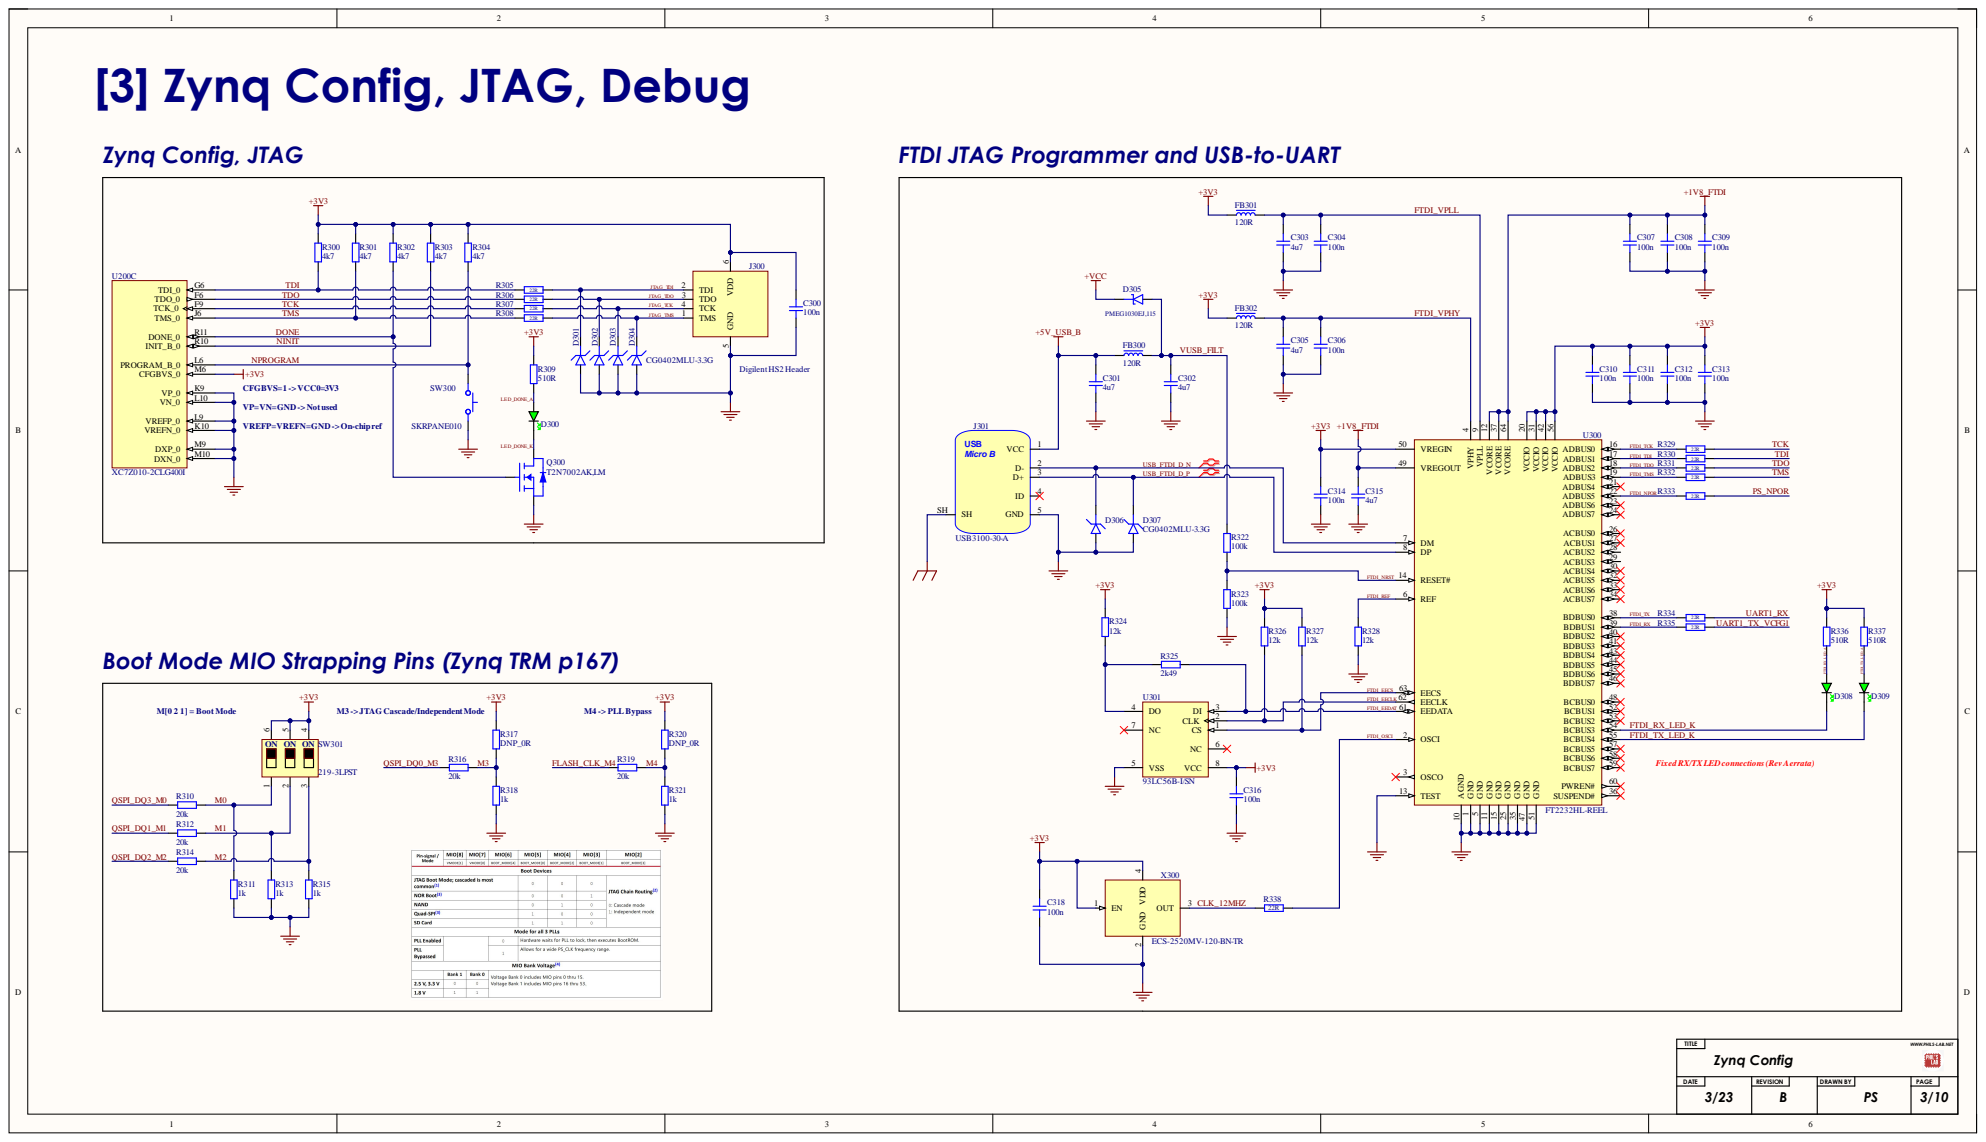
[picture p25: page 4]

[3] Zynq Config, JTAG, Debug

G Programmer and USB-to-U

ot Mode MIO Strapping Pins (Zynq TRM p167)

CL K N CS N C V VCC | 2 | FT DI_ OSCI 2 | 5 3 | F T DI_RX _ L E D_ K

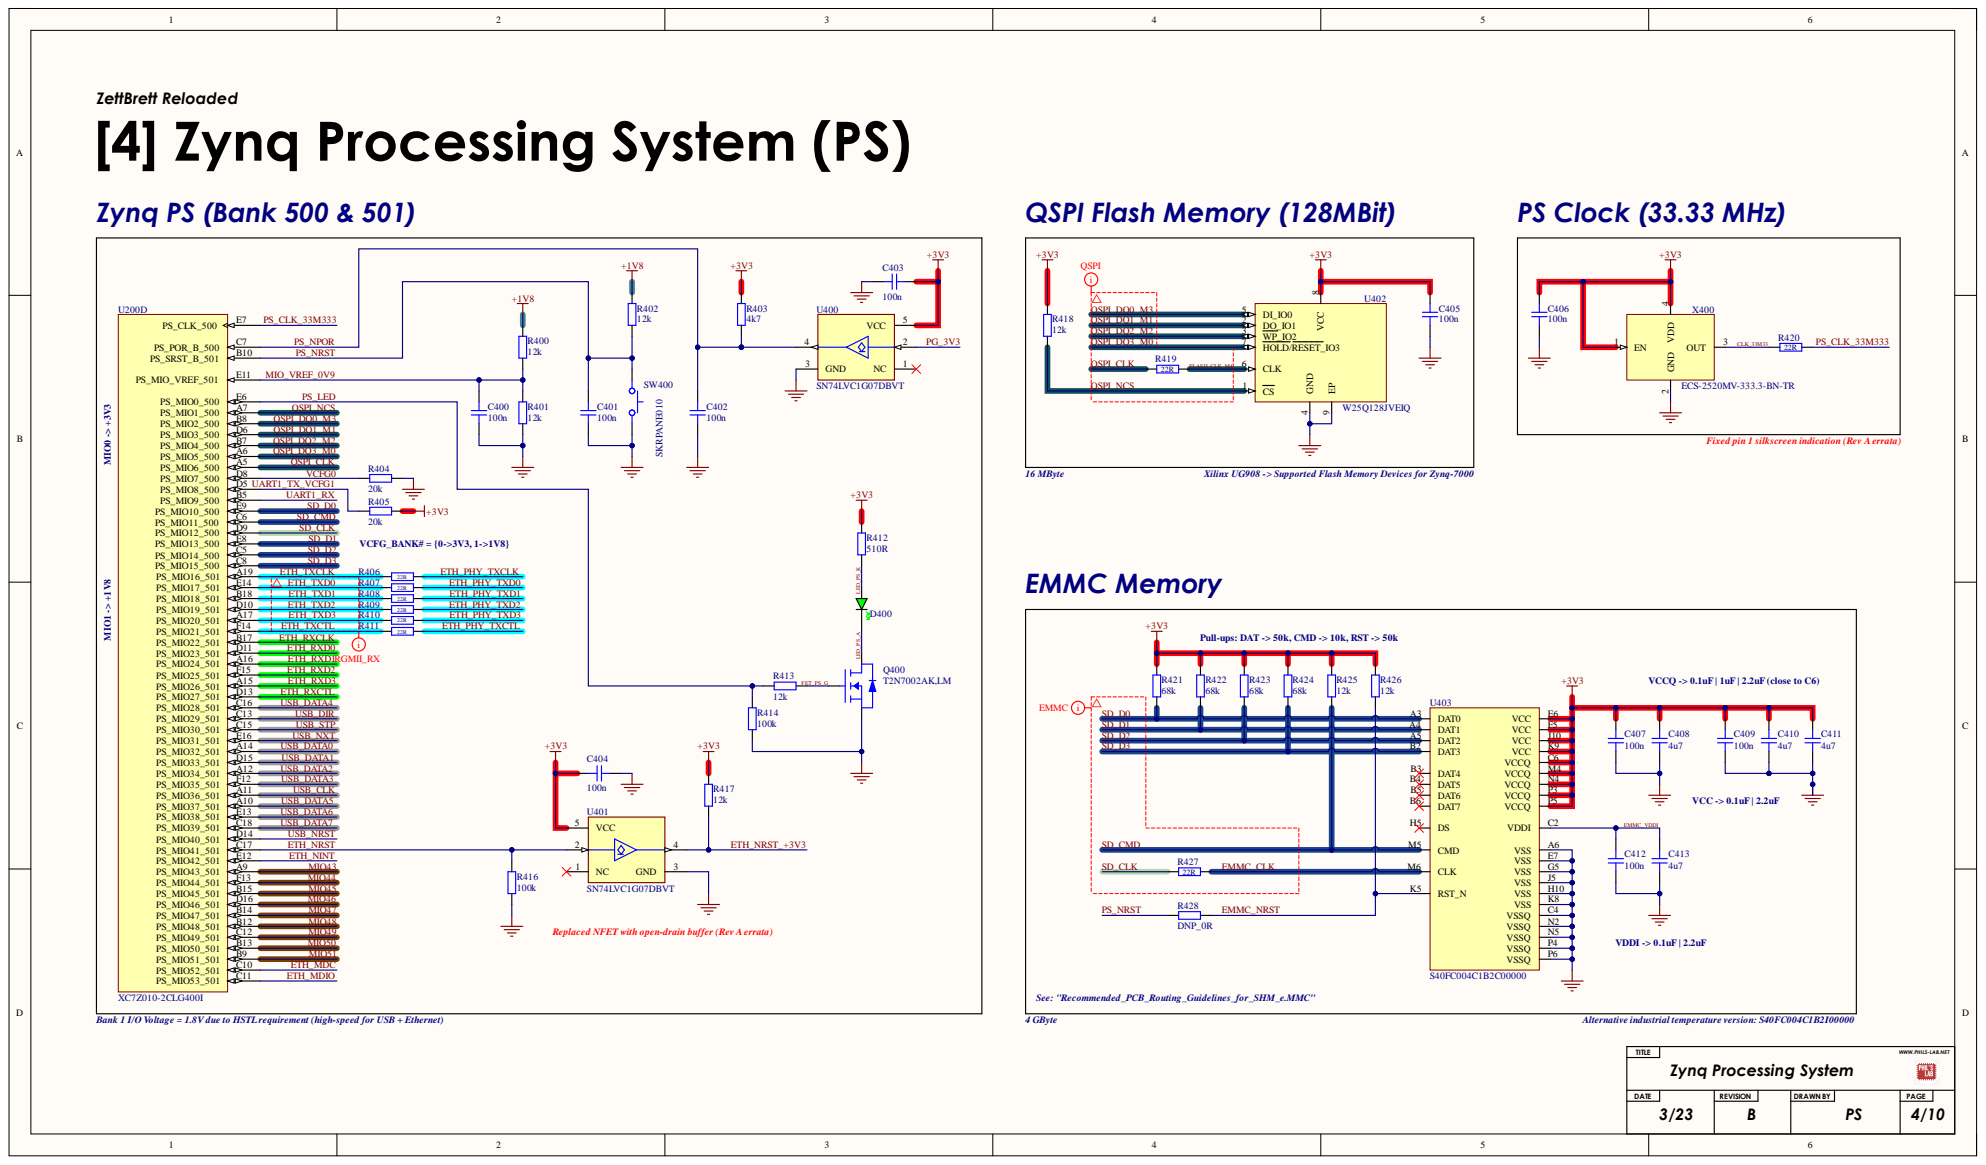
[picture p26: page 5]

Zet
[4] Zynq Processing System (PS)Q400 T2N70

DA TE | 3/2 3 | R EVI S I O N | DR A W N B Y | PS | P A G E | 0

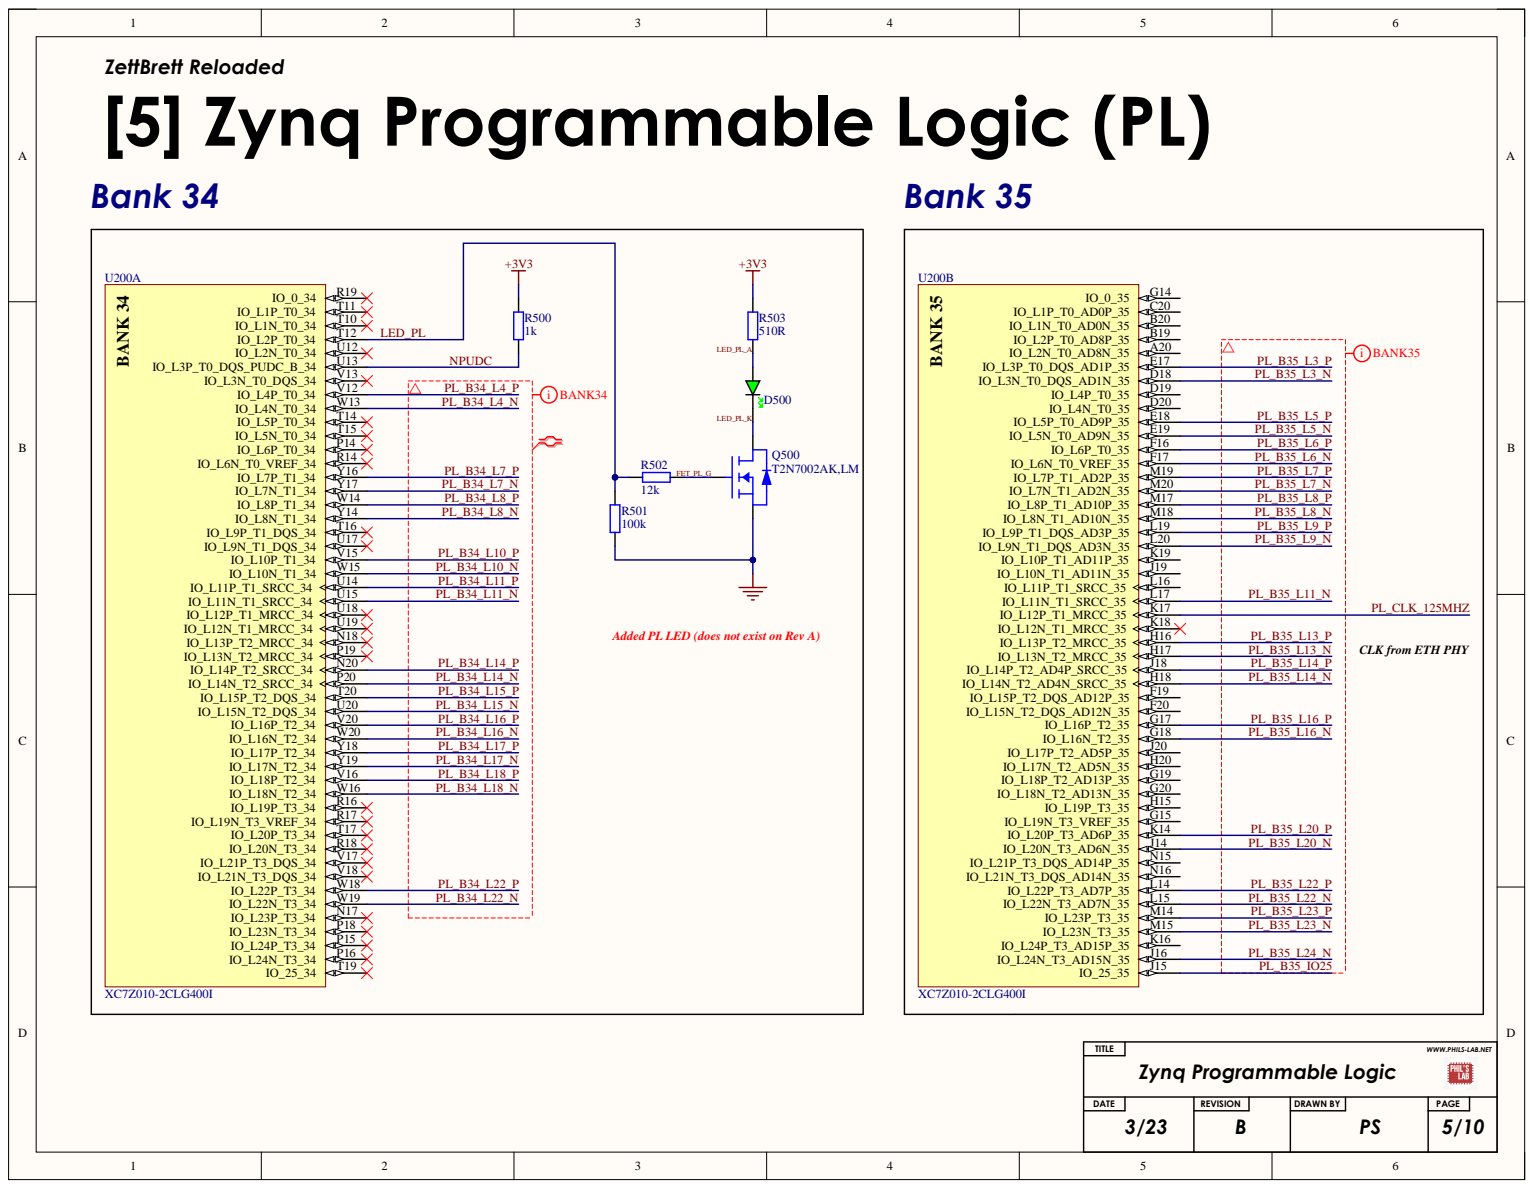
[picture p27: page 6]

[5] Zynq Programmable Logic (PL)

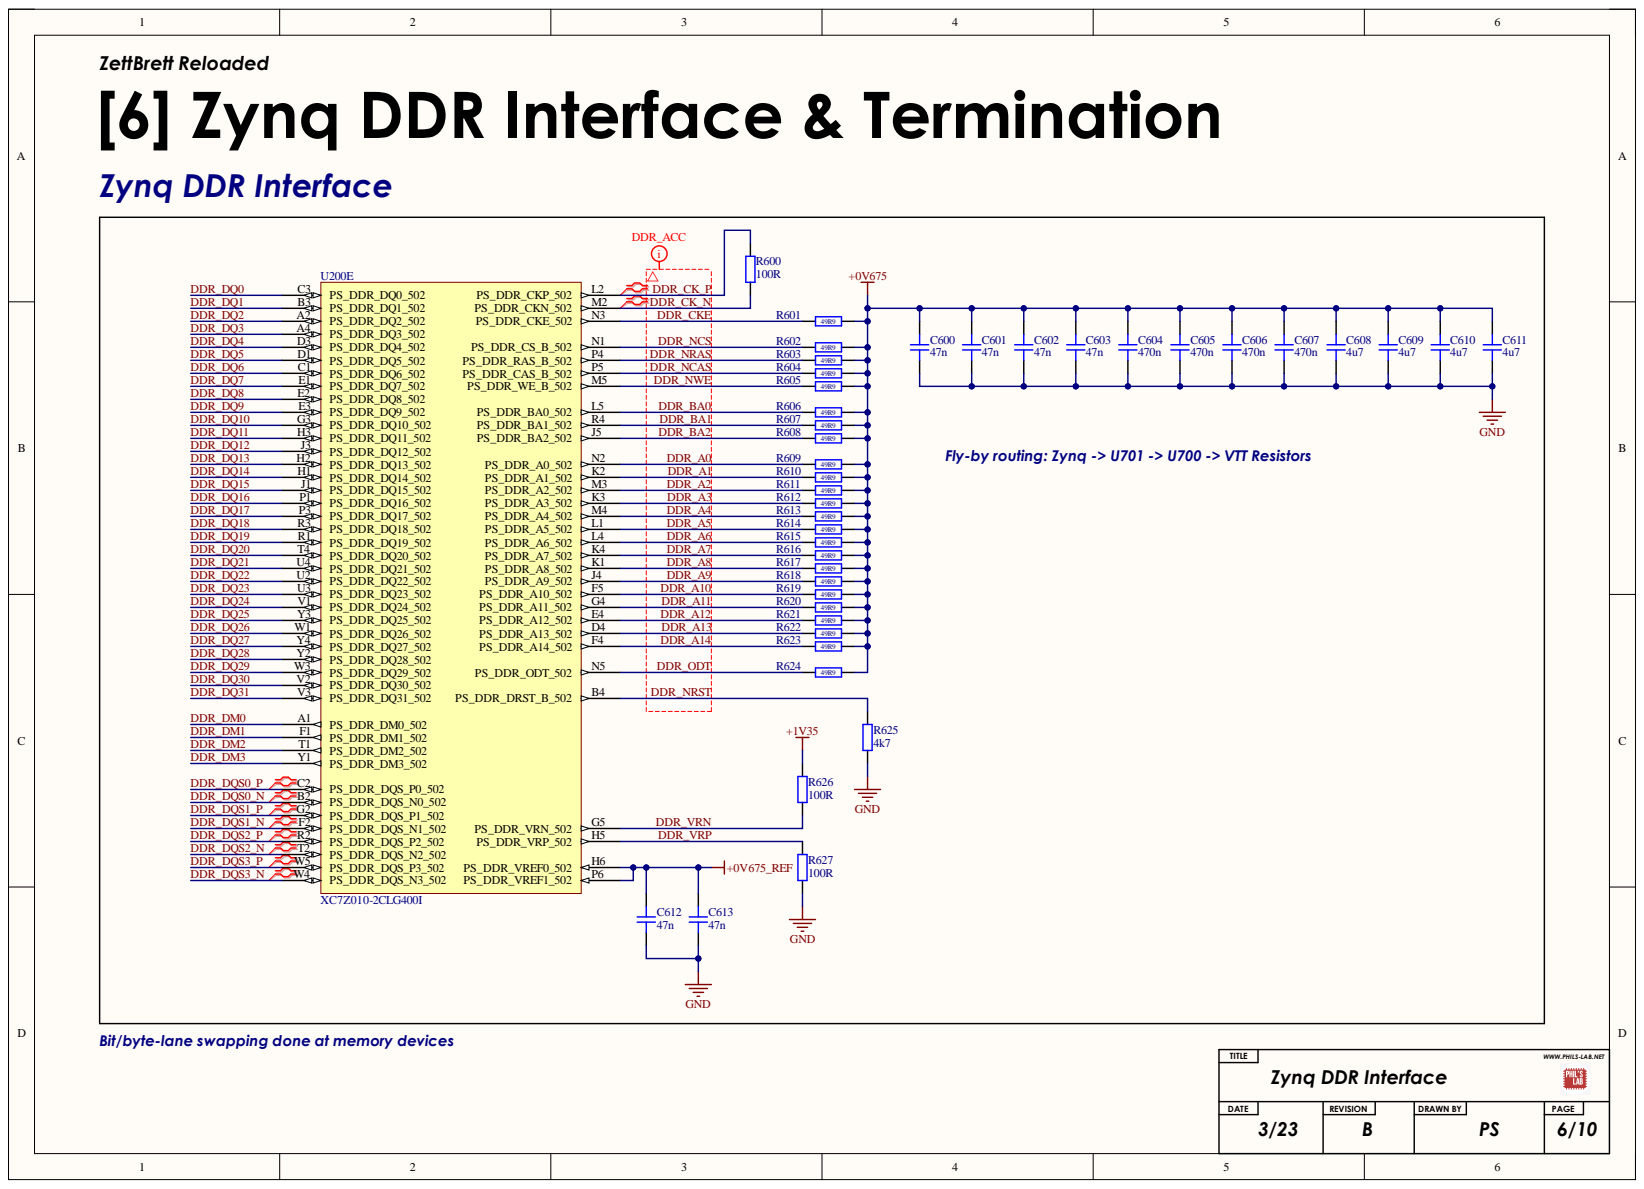
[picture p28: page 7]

[6] Zynq DDR Interface & Termination

N | | DDR _ C KE

DDR _ C K_N

P5 PS_DDR_RAS_B_502 P4 PS_DDR_CS_B_502 N1 5 PS_DDR_CAS_B_502 | DDR _NRA S | R 6 0 3

DDR _N C S

M | DDR _NW E | R 6 0 5

DDR _N C A S | R 6 0 4

L5 | DDR_B A0
R4 | DDR_B A 1 | R 6 0 7
J 5 | DDR_B A 2 | R 6 0 8

N 2 | DDR_A0
K2 | DDR_A 1 | R 6 1 0

M 3 | DDR_A 2 | R 6 1 1
K 3 | DDR_A 3 | R 6 1 2
M4 | DDR_A4 | R 6 1 3
L 1 | DDR_A 5 | R 6 1 4
L4 | DDR_A 6 | R 6 1 5
K4 | DDR_A7 | R 6 1 6
K 1 | DDR_A 8 | R 6 1 7
J 4 | DDR_A 9 | R 6 1 8
F 5 | DDR_A 1 0 | R 6 1 9
G4 | DDR_A 1 1 | R 6 2 0
E4 | DDR_A 1 2 | R 6 2 1
D 4 | DDR_A 1 3 | R 6 2 2
F4 | DDR_A 1 4 | R 6 2 3

N 5 | DDR _ O D T

B 4 | DDR _ NR S T

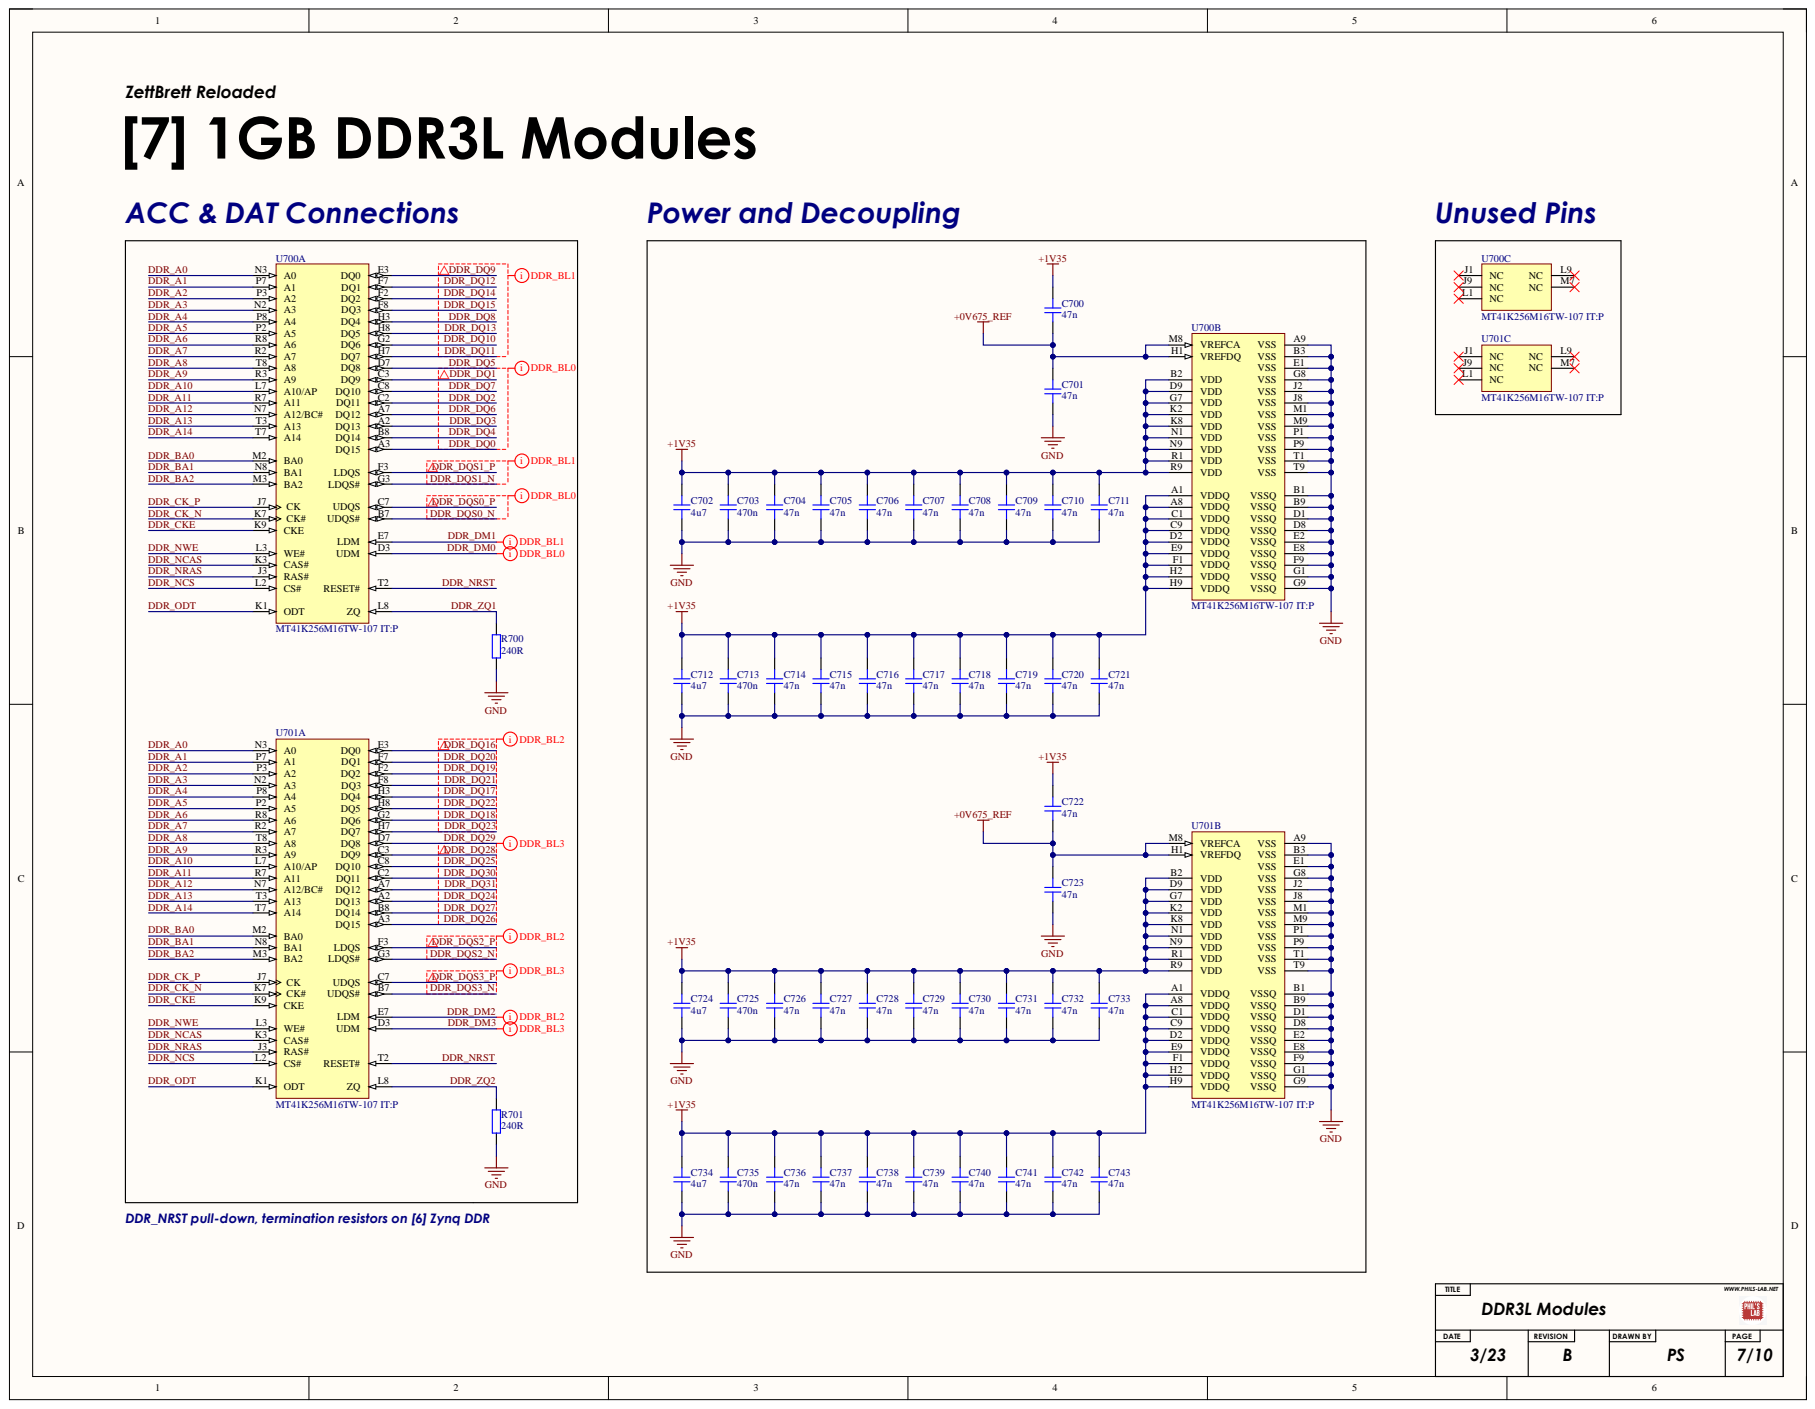
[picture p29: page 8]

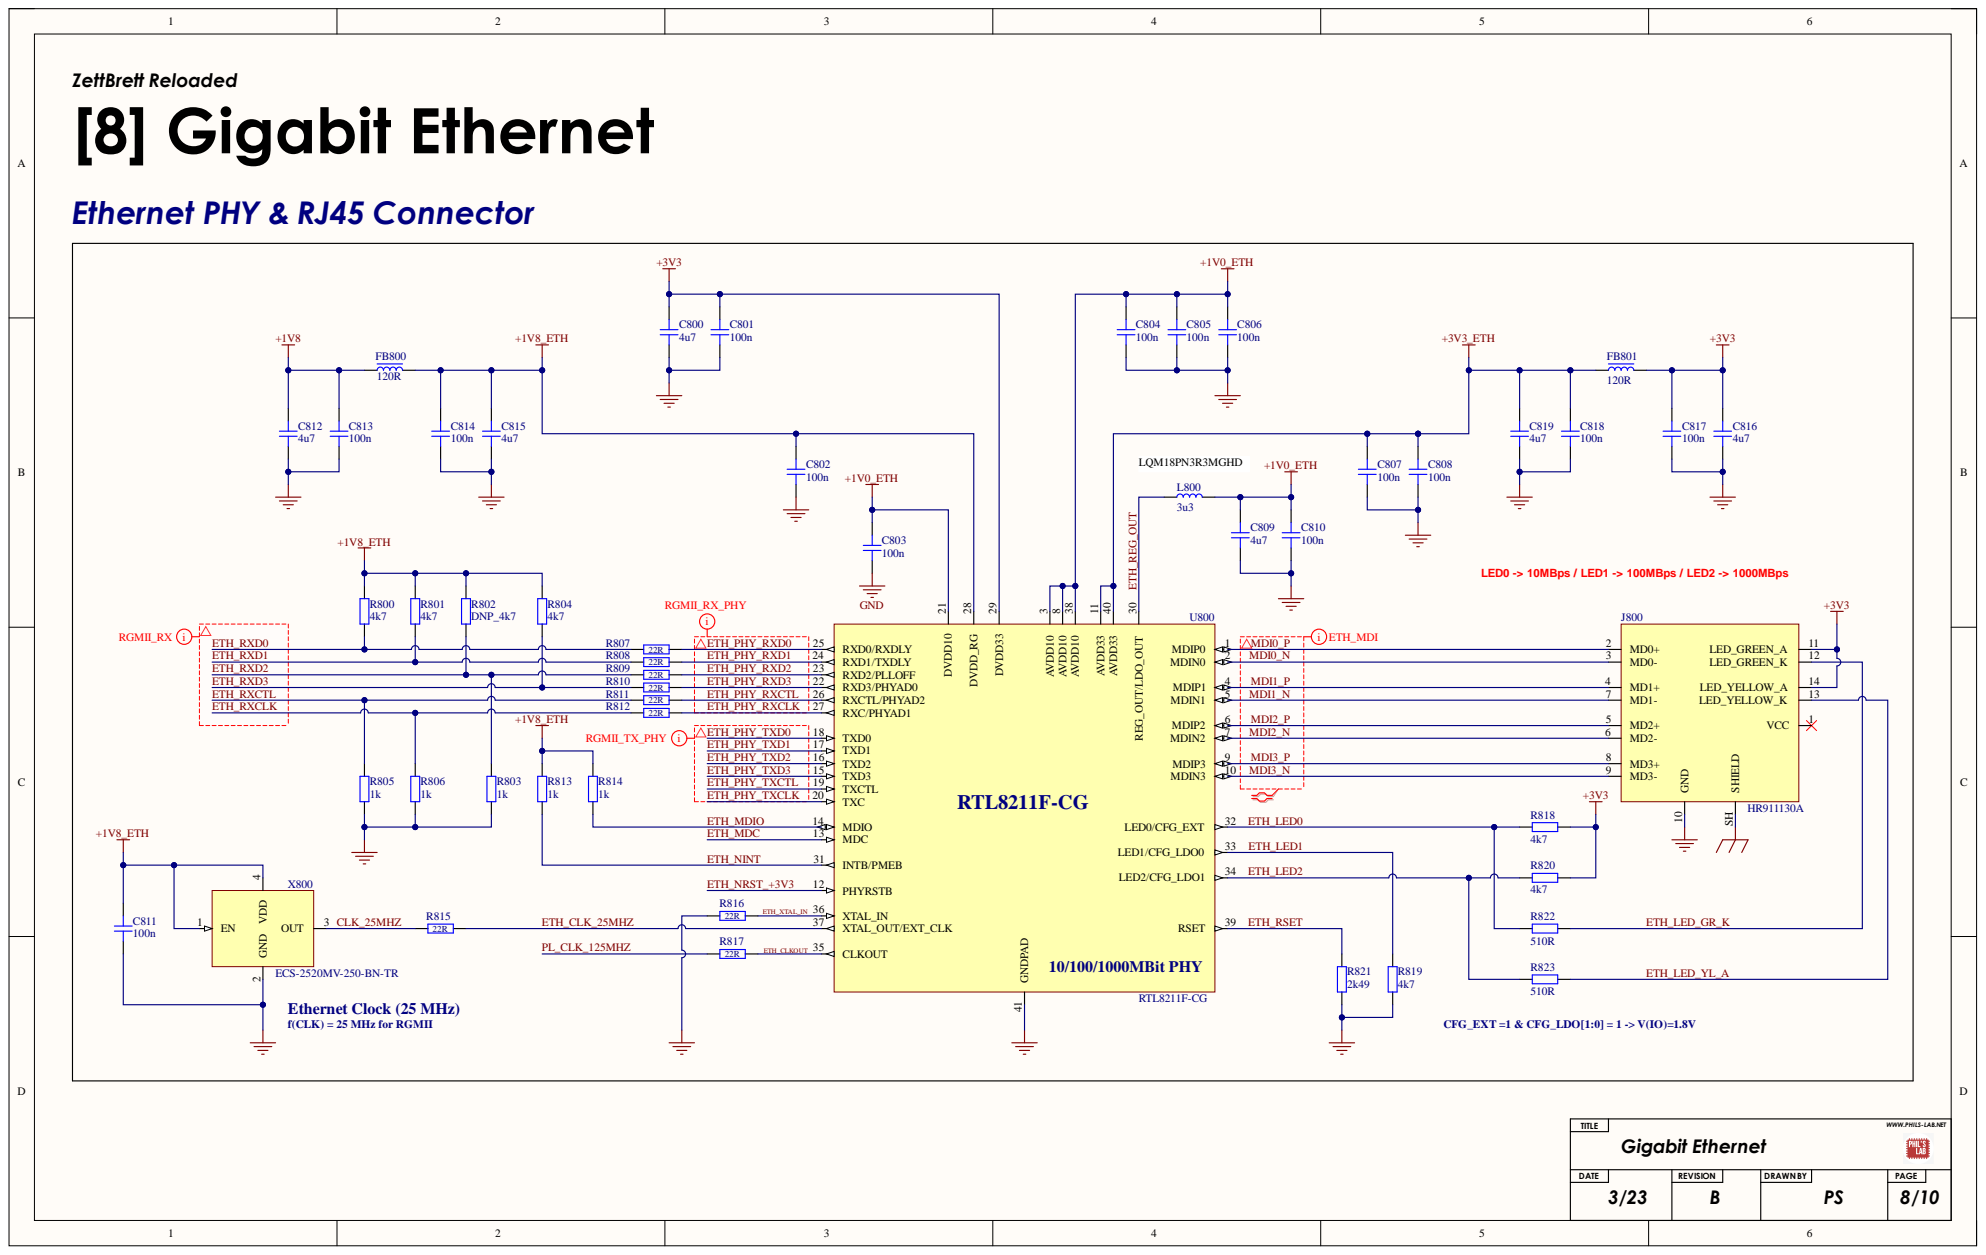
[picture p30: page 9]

Ethernet PHY & RJ45 Connector f(CLK) = 25 MHz for RGMII RGMII_RX i

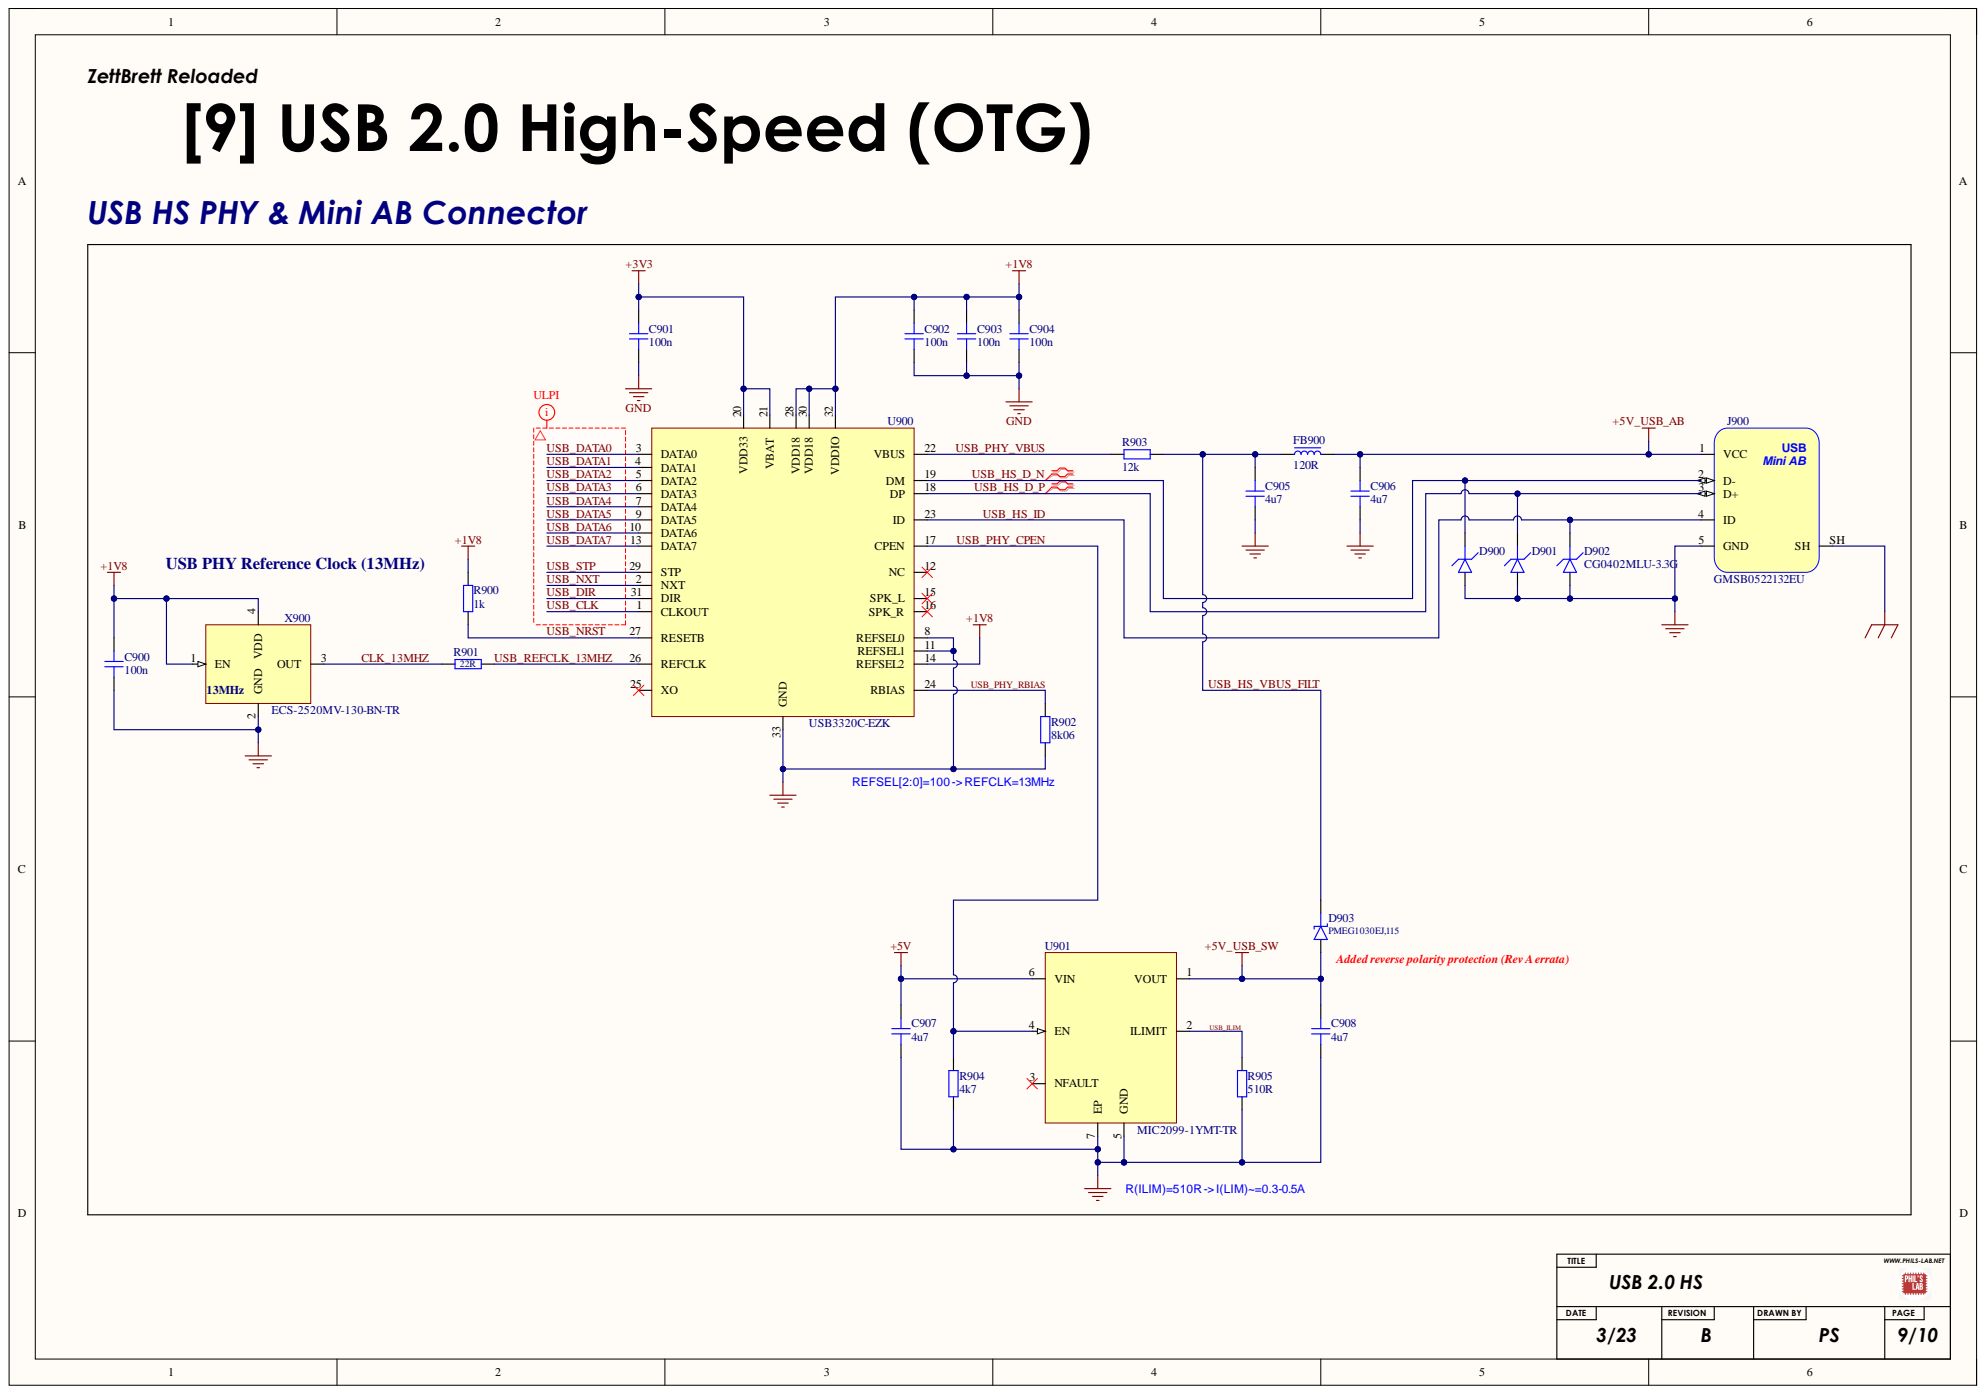
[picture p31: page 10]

[9] USB 2.0 High-Speed (OTG)

USB HS PHY & Mini AB Connector

USB PHY Reference Clock (13MHz)

Added reverse polarity protection (Rev Aerrata)

WWW.PHILS-LAB.NET

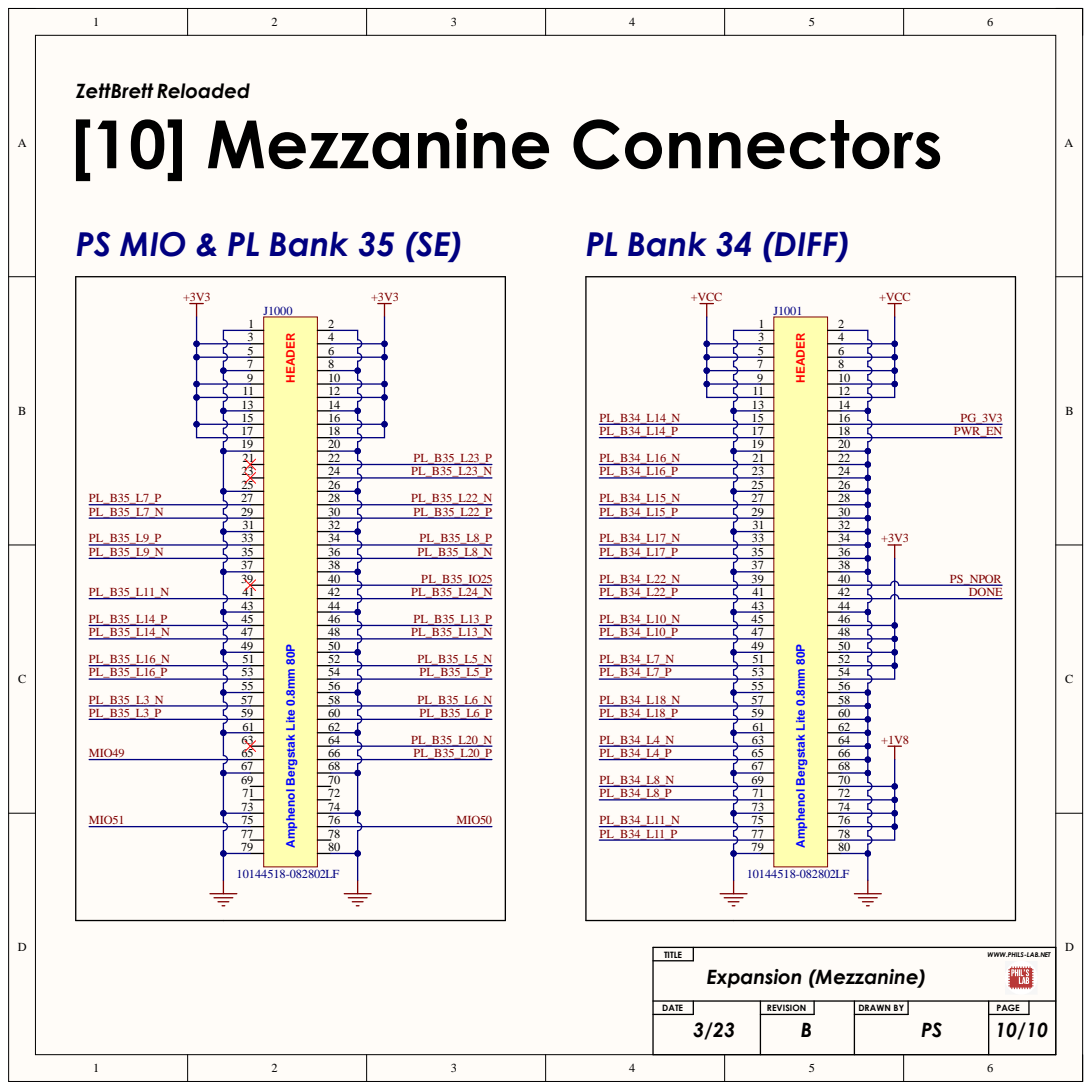
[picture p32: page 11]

[10] Mezzanine Connectors ZettBrett Reloaded

mphenol Bergstak Lite 0.8mm 80P HEADER

17 | | 18
19 | 20

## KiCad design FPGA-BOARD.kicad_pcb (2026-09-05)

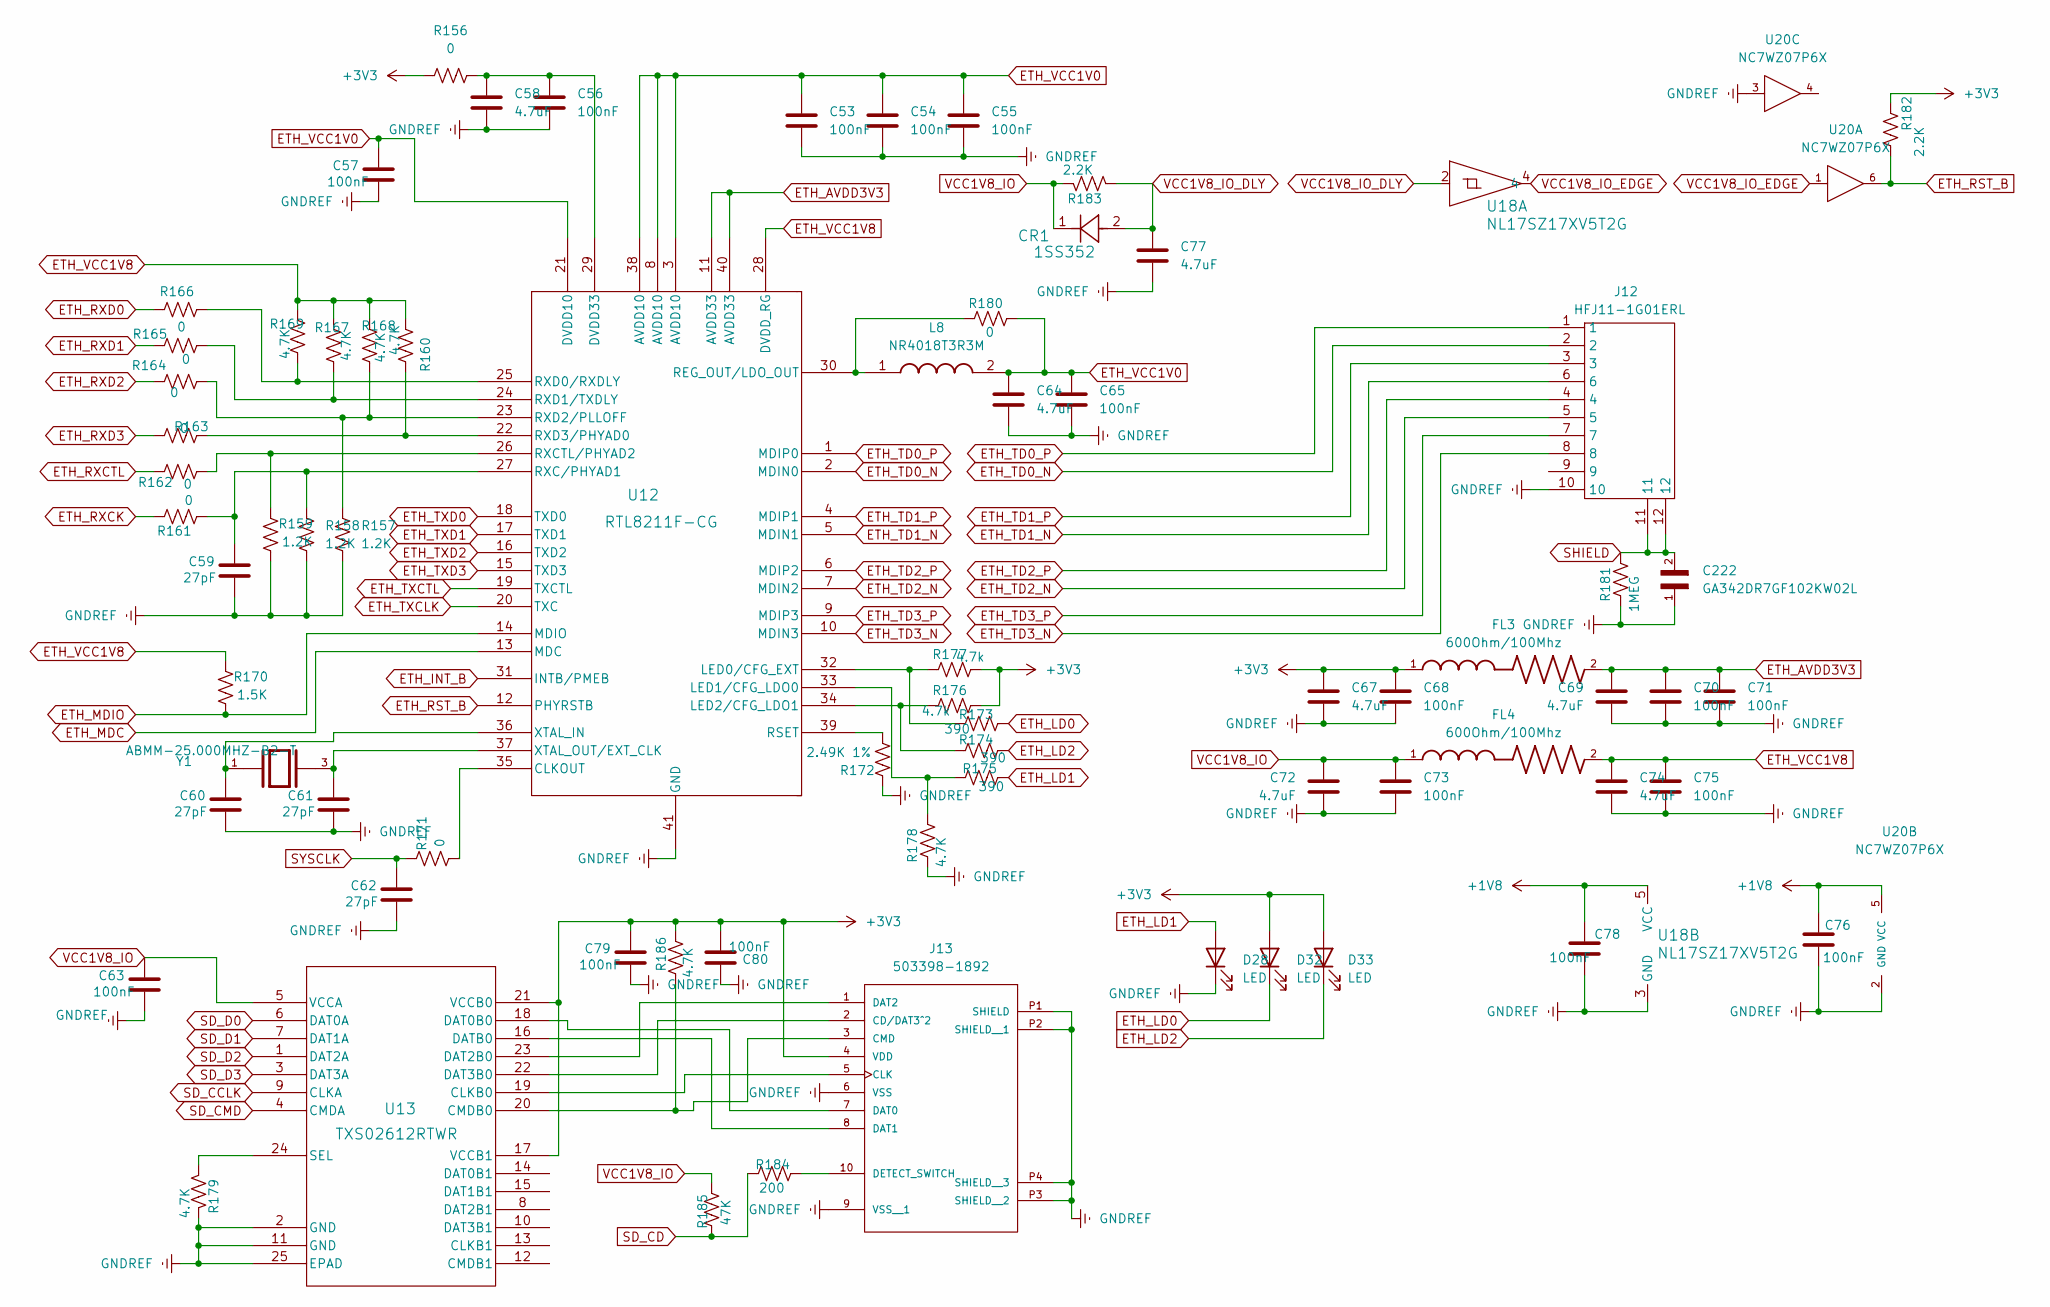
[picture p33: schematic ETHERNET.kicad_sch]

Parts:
C53, C54, C55, C56, C57, C63, C65, C68, C70, C71, C73, C75, C76, C78, C79, C80: 100nF; C_0201_0603Metric; LCSC PN c307380
C58, C64, C67, C69, C72, C74, C77: 4.7uF; C_0402; LCSC PN C2858031
C59, C60, C61, C62: 27pF; C_0201_0603Metric; LCSC PN C161381
C222: GA342DR7GF102KW02L; CAPC4520X220N; LCSC PN C237595
CR1: 1SS352; USC_TOS; LCSC PN C15885
D28, D32, D33: LED; LED_0402_1005Metric; LCSC PN C130723
FL3, FL4: 600Ohm/100Mhz; BEADC1608X95N; LCSC PN C19330
J12: HFJ11-1G01ERL; HALO_FASTJACK; Mouser Part Number 493-HFJ11-1G01ERL
J13: 503398-1892; MOLEX_503398-1892; PARTREV 0; LCSC PN C428492
L8: NR4018T3R3M; Mouser Part Number 963-NR4018T3R3M
R156, R171, R180: 0; R_0402; LCSC PN C106231
R157, R158, R159: 1.2K; R_0201_0603Metric; LCSC PN C327393
R160, R167, R168, R169, R178, R179, R186: 4.7K; R_0201_0603Metric; LCSC PN C138135
R161, R162, R163, R164, R165, R166: 0; R_0201_0603Metric; LCSC PN c106228
R170: 1.5K; R_0402; LCSC PN C114759
R172: 2.49K 1%; R_0402; LCSC PN C145071
R173, R174, R175: 390; R_0402; LCSC PN C137997
R176, R177: 4.7k; R_0402; LCSC PN C105871
R181: 1MEG; R_0402; LCSC PN C138033
R182, R183: 2.2K; R_0402; LCSC PN c114762
R184: 200; R_0402; LCSC PN C114764
R185: 47K; R_0402; LCSC PN C93943
U12: RTL8211F-CG; RTL8211F-CG_RTK; LCSC PN C187932
U13: TXS02612RTWR; RTW24_2P45X2P45; LCSC PN C140276
U18: NL17SZ17XV5T2G; SOT553-5_ONS; LCSC PN C152502
U20: NC7WZ07P6X; MPN NC7WZ07P6X; LCSC PN C95342
Y1: ABMM-25.000MHZ-B2-T; XTAL_ABMM-25.000MHZ-B2-T; PARTREV 02.26.12; LCSC PN C596927

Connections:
+1V8: C76.1, C78.1, U18.5 (VCC), U20.5 (VCC); also elsewhere on the board
+3V3: C67.1, C68.1, C79.1, C80.1, D32.2 (A), D33.2 (A), FL3.1, J13.4 (VDD), R156.2, R176.2, R177.2, R182.2, R186.2, U13.17 (VCCB1), U13.21 (VCCB0); also elsewhere on the board
ETH_AVDD3V3: C69.1, C70.1, C71.1, FL3.2, U12.11 (AVDD33), U12.40 (AVDD33)
ETH_INT_B: U12.31 (INTB/PMEB); also elsewhere on the board
ETH_LD0: D32.1 (K), R173.2
ETH_LD1: D28.2 (A), R175.2
ETH_LD2: D33.1 (K), R174.2
ETH_MDC: U12.13 (MDC); also elsewhere on the board
ETH_MDIO: R170.2, U12.14 (MDIO); also elsewhere on the board
ETH_RST_B: R182.1, U12.12 (PHYRSTB), U20.6; also elsewhere on the board
ETH_RXCK: R161.2; also elsewhere on the board
ETH_RXCTL: R162.2; also elsewhere on the board
ETH_RXD0: R166.2; also elsewhere on the board
ETH_RXD1: R165.2; also elsewhere on the board
ETH_RXD2: R164.2; also elsewhere on the board
ETH_RXD3: R163.2; also elsewhere on the board
ETH_TD0_N: J12.2, U12.2 (MDIN0)
ETH_TD0_P: J12.1, U12.1 (MDIP0)
ETH_TD1_N: J12.6, U12.5 (MDIN1)
ETH_TD1_P: J12.3, U12.4 (MDIP1)
ETH_TD2_N: J12.5, U12.7 (MDIN2)
ETH_TD2_P: J12.4, U12.6 (MDIP2)
ETH_TD3_N: J12.8, U12.10 (MDIN3)
ETH_TD3_P: J12.7, U12.9 (MDIP3)
ETH_TXCLK: U12.20 (TXC); also elsewhere on the board
ETH_TXCTL: U12.19 (TXCTL); also elsewhere on the board
ETH_TXD0: U12.18 (TXD0); also elsewhere on the board
ETH_TXD1: U12.17 (TXD1); also elsewhere on the board
ETH_TXD2: U12.16 (TXD2); also elsewhere on the board
ETH_TXD3: U12.15 (TXD3); also elsewhere on the board
ETH_VCC1V0: C53.1, C54.1, C55.1, C57.1, C64.1, C65.1, L8.2, R180.2, U12.3 (AVDD10), U12.8 (AVDD10), U12.21 (DVDD10), U12.38 (AVDD10)
ETH_VCC1V8: C74.1, C75.1, FL4.2, R160.1, R167.1, R168.1, R169.1, R170.1, U12.28 (DVDD_RG)
GNDREF: C53.2, C54.2, C55.2, C56.2, C57.2, C58.2, C59.2, C60.2, C61.2, C62.2, C63.2, C64.2, C65.2, C67.2, C68.2, C69.2, C70.2, C71.2, C72.2, C73.2, C74.2, C75.2, C76.2, C77.2, C78.2, C79.2, C80.2, C222.1, D28.1 (K), J12.10, J13.6 (VSS), J13.9 (VSS__1), J13.P1 (SHIELD), J13.P2 (SHIELD__1), J13.P3 (SHIELD__2), J13.P4 (SHIELD__3), R157.2, R158.2, R159.2, R172.1, R178.1, R179.1, R181.1, U12.41 (GND), U13.2 (GND), U13.11 (GND), U13.25 (EPAD), U13.V, U18.3 (GND), U20.2 (GND), U20.3; also elsewhere on the board
unnamed: J13.2 (CD/DAT3^2), U13.22 (DAT3B0)
unnamed: J13.5 (CLK), U13.19 (CLKB0)
unnamed: J13.3 (CMD), R186.1, U13.20 (CMDB0)
unnamed: J13.7 (DAT0), U13.18 (DAT0B0)
unnamed: J13.8 (DAT1), U13.16 (DATB0)
unnamed: J13.1 (DAT2), U13.23 (DAT2B0)
unnamed: J13.10 (DETECT_SWITCH), R184.2
unnamed: R171.2, U12.35 (CLKOUT)
unnamed: C56.1, C58.1, R156.1, U12.29 (DVDD33)
unnamed: R173.1, R177.1, U12.32 (LED0/CFG_EXT)
unnamed: R175.1, R178.2, U12.33 (LED1/CFG_LDO0)
unnamed: R174.1, R176.1, U12.34 (LED2/CFG_LDO1)
unnamed: L8.1, R180.1, U12.30 (REG_OUT/LDO_OUT)
unnamed: R172.2, U12.39 (RSET)
unnamed: R159.1, R162.1, U12.26 (RXCTL/PHYAD2)
unnamed: C59.1, R158.1, R161.1, U12.27 (RXC/PHYAD1)
unnamed: R166.1, R169.2, U12.25 (RXD0/RXDLY)
unnamed: R165.1, R167.2, U12.24 (RXD1/TXDLY)
unnamed: R157.1, R164.1, R168.2, U12.23 (RXD2/PLLOFF)
unnamed: R160.2, R163.1, U12.22 (RXD3/PHYAD0)
unnamed: C60.1, U12.36 (XTAL_IN), Y1.1
unnamed: C61.1, U12.37 (XTAL_OUT/EXT_CLK), Y1.3
unnamed: R179.2, U13.24 (SEL)
SD_CCLK: U13.9 (CLKA); also elsewhere on the board
SD_CD: R184.1, R185.1; also elsewhere on the board
SD_CMD: U13.4 (CMDA); also elsewhere on the board
SD_D0: U13.6 (DAT0A); also elsewhere on the board
SD_D1: U13.7 (DAT1A); also elsewhere on the board
SD_D2: U13.1 (DAT2A); also elsewhere on the board
SD_D3: U13.3 (DAT3A); also elsewhere on the board
SHIELD: C222.2, J12.11, J12.12, R181.2
SYSCLK: C62.1, R171.1; also elsewhere on the board
VCC1V8_IO: C63.1, C72.1, C73.1, CR1.1, FL4.1, R183.1, R185.2, U13.5 (VCCA); also elsewhere on the board
VCC1V8_IO_DLY: C77.1, CR1.2, R183.2, U18.2
VCC1V8_IO_EDGE: U18.4, U20.1

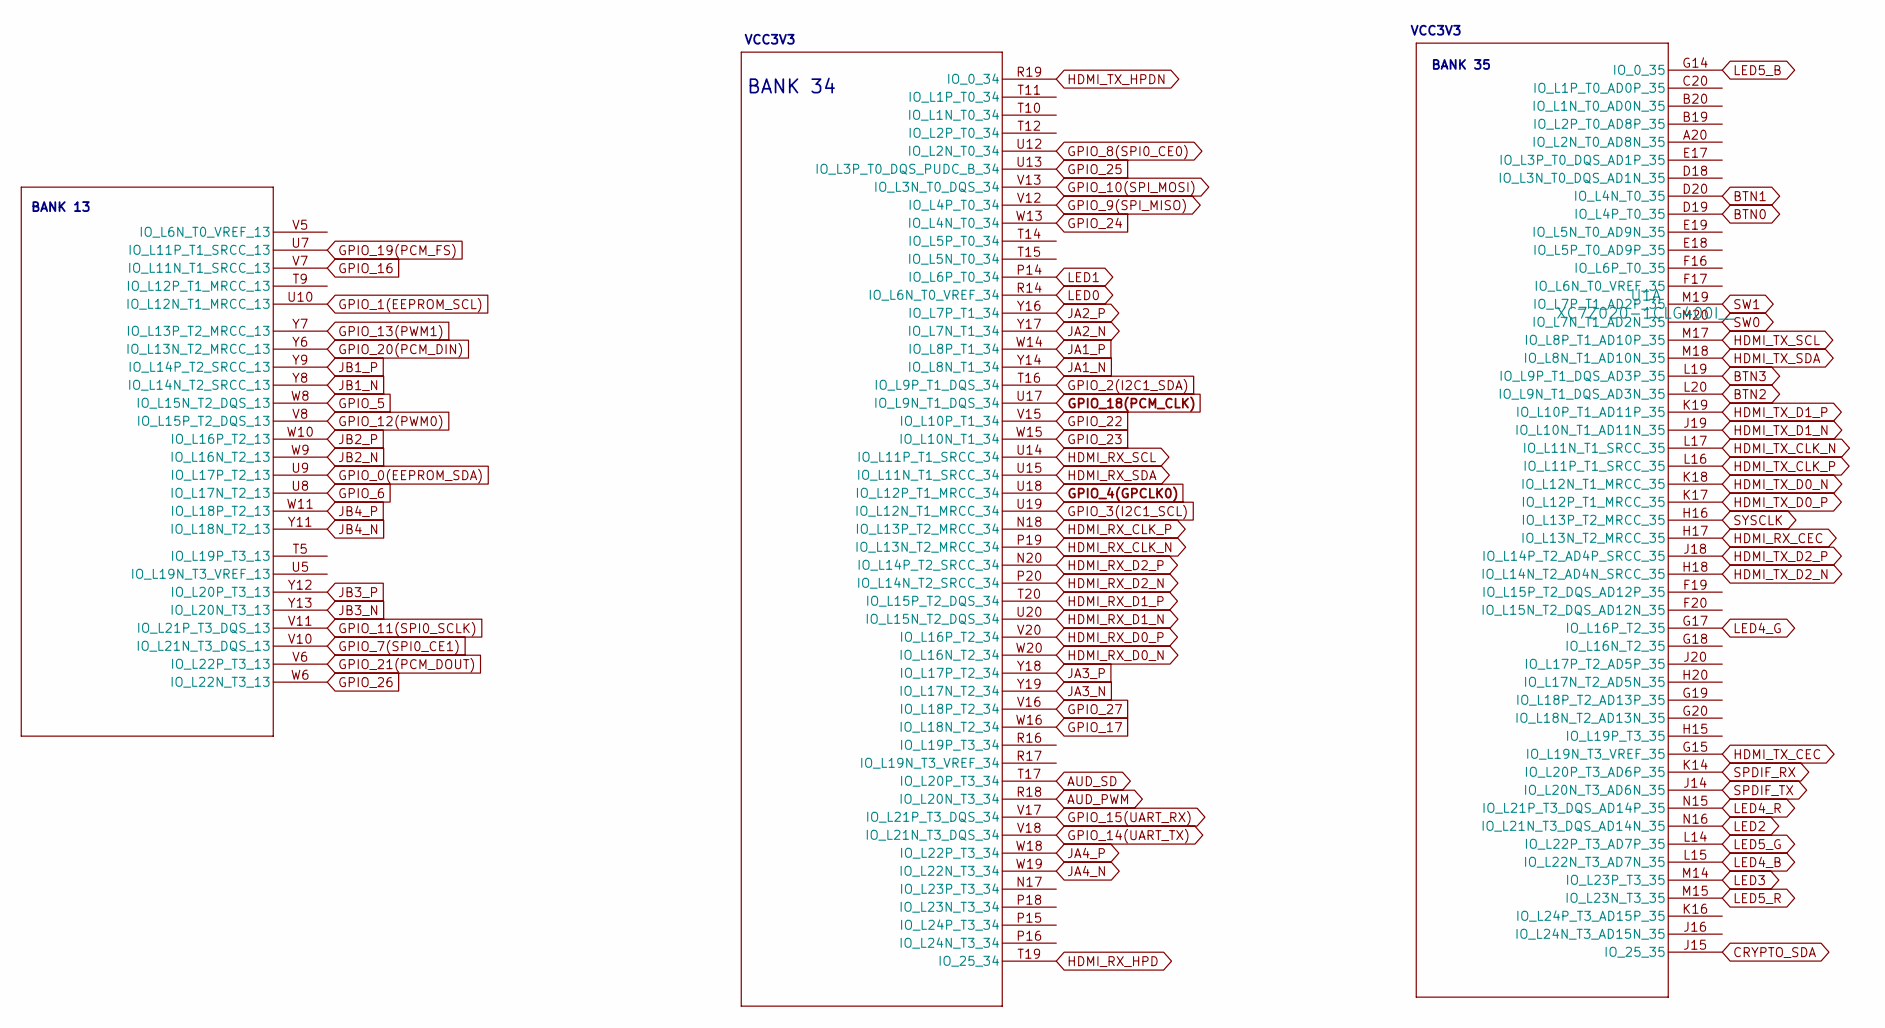
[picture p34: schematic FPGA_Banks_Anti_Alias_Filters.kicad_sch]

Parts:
U1: XC7Z020-1CLG400I__; CLG400_ZYNQ-7000_AMD; LCSC PN C1519081

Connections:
AUD_PWM: U1.R18 (IO_L20N_T3_34); also elsewhere on the board
AUD_SD: U1.T17 (IO_L20P_T3_34); also elsewhere on the board
BTN0: U1.D19 (IO_L4P_T0_35); also elsewhere on the board
BTN1: U1.D20 (IO_L4N_T0_35); also elsewhere on the board
BTN2: U1.L20 (IO_L9N_T1_DQS_AD3N_35); also elsewhere on the board
BTN3: U1.L19 (IO_L9P_T1_DQS_AD3P_35); also elsewhere on the board
CRYPTO_SDA: U1.J15 (IO_25_35); also elsewhere on the board
GPIO_0(EEPROM_SDA): U1.U9 (IO_L17P_T2_13); also elsewhere on the board
GPIO_1(EEPROM_SCL): U1.U10 (IO_L12N_T1_MRCC_13); also elsewhere on the board
GPIO_2(I2C1_SDA): U1.T16 (IO_L9P_T1_DQS_34); also elsewhere on the board
GPIO_3(I2C1_SCL): U1.U19 (IO_L12N_T1_MRCC_34); also elsewhere on the board
GPIO_4(GPCLK0): U1.U18 (IO_L12P_T1_MRCC_34); also elsewhere on the board
GPIO_5: U1.W8 (IO_L15N_T2_DQS_13); also elsewhere on the board
GPIO_6: U1.U8 (IO_L17N_T2_13); also elsewhere on the board
GPIO_7(SPI0_CE1): U1.V10 (IO_L21N_T3_DQS_13); also elsewhere on the board
GPIO_8(SPI0_CE0): U1.U12 (IO_L2N_T0_34); also elsewhere on the board
GPIO_9(SPI_MISO): U1.V12 (IO_L4P_T0_34); also elsewhere on the board
GPIO_10(SPI_MOSI): U1.V13 (IO_L3N_T0_DQS_34); also elsewhere on the board
GPIO_11(SPI0_SCLK): U1.V11 (IO_L21P_T3_DQS_13); also elsewhere on the board
GPIO_12(PWM0): U1.V8 (IO_L15P_T2_DQS_13); also elsewhere on the board
GPIO_13(PWM1): U1.Y7 (IO_L13P_T2_MRCC_13); also elsewhere on the board
GPIO_14(UART_TX): U1.V18 (IO_L21N_T3_DQS_34); also elsewhere on the board
GPIO_15(UART_RX): U1.V17 (IO_L21P_T3_DQS_34); also elsewhere on the board
GPIO_16: U1.V7 (IO_L11N_T1_SRCC_13); also elsewhere on the board
GPIO_17: U1.W16 (IO_L18N_T2_34); also elsewhere on the board
GPIO_18(PCM_CLK): U1.U17 (IO_L9N_T1_DQS_34); also elsewhere on the board
GPIO_19(PCM_FS): U1.U7 (IO_L11P_T1_SRCC_13); also elsewhere on the board
GPIO_20(PCM_DIN): U1.Y6 (IO_L13N_T2_MRCC_13); also elsewhere on the board
GPIO_21(PCM_DOUT): U1.V6 (IO_L22P_T3_13); also elsewhere on the board
GPIO_22: U1.V15 (IO_L10P_T1_34); also elsewhere on the board
GPIO_23: U1.W15 (IO_L10N_T1_34); also elsewhere on the board
GPIO_24: U1.W13 (IO_L4N_T0_34); also elsewhere on the board
GPIO_25: U1.U13 (IO_L3P_T0_DQS_PUDC_B_34); also elsewhere on the board
GPIO_26: U1.W6 (IO_L22N_T3_13); also elsewhere on the board
GPIO_27: U1.V16 (IO_L18P_T2_34); also elsewhere on the board
HDMI_RX_CEC: U1.H17 (IO_L13N_T2_MRCC_35); also elsewhere on the board
HDMI_RX_CLK_N: U1.P19 (IO_L13N_T2_MRCC_34); also elsewhere on the board
HDMI_RX_CLK_P: U1.N18 (IO_L13P_T2_MRCC_34); also elsewhere on the board
HDMI_RX_D0_N: U1.W20 (IO_L16N_T2_34); also elsewhere on the board
HDMI_RX_D0_P: U1.V20 (IO_L16P_T2_34); also elsewhere on the board
HDMI_RX_D1_N: U1.U20 (IO_L15N_T2_DQS_34); also elsewhere on the board
HDMI_RX_D1_P: U1.T20 (IO_L15P_T2_DQS_34); also elsewhere on the board
HDMI_RX_D2_N: U1.P20 (IO_L14N_T2_SRCC_34); also elsewhere on the board
HDMI_RX_D2_P: U1.N20 (IO_L14P_T2_SRCC_34); also elsewhere on the board
HDMI_RX_HPD: U1.T19 (IO_25_34); also elsewhere on the board
HDMI_RX_SCL: U1.U14 (IO_L11P_T1_SRCC_34); also elsewhere on the board
HDMI_RX_SDA: U1.U15 (IO_L11N_T1_SRCC_34); also elsewhere on the board
HDMI_TX_CEC: U1.G15 (IO_L19N_T3_VREF_35); also elsewhere on the board
HDMI_TX_CLK_N: U1.L17 (IO_L11N_T1_SRCC_35); also elsewhere on the board
HDMI_TX_CLK_P: U1.L16 (IO_L11P_T1_SRCC_35); also elsewhere on the board
HDMI_TX_D0_N: U1.K18 (IO_L12N_T1_MRCC_35); also elsewhere on the board
HDMI_TX_D0_P: U1.K17 (IO_L12P_T1_MRCC_35); also elsewhere on the board
HDMI_TX_D1_N: U1.J19 (IO_L10N_T1_AD11N_35); also elsewhere on the board
HDMI_TX_D1_P: U1.K19 (IO_L10P_T1_AD11P_35); also elsewhere on the board
HDMI_TX_D2_N: U1.H18 (IO_L14N_T2_AD4N_SRCC_35); also elsewhere on the board
HDMI_TX_D2_P: U1.J18 (IO_L14P_T2_AD4P_SRCC_35); also elsewhere on the board
HDMI_TX_HPDN: U1.R19 (IO_0_34); also elsewhere on the board
HDMI_TX_SCL: U1.M17 (IO_L8P_T1_AD10P_35); also elsewhere on the board
HDMI_TX_SDA: U1.M18 (IO_L8N_T1_AD10N_35); also elsewhere on the board
JA1_N: U1.Y14 (IO_L8N_T1_34); also elsewhere on the board
JA1_P: U1.W14 (IO_L8P_T1_34); also elsewhere on the board
JA2_N: U1.Y17 (IO_L7N_T1_34); also elsewhere on the board
JA2_P: U1.Y16 (IO_L7P_T1_34); also elsewhere on the board
JA3_N: U1.Y19 (IO_L17N_T2_34); also elsewhere on the board
JA3_P: U1.Y18 (IO_L17P_T2_34); also elsewhere on the board
JA4_N: U1.W19 (IO_L22N_T3_34); also elsewhere on the board
JA4_P: U1.W18 (IO_L22P_T3_34); also elsewhere on the board
JB1_N: U1.Y8 (IO_L14N_T2_SRCC_13); also elsewhere on the board
JB1_P: U1.Y9 (IO_L14P_T2_SRCC_13); also elsewhere on the board
JB2_N: U1.W9 (IO_L16N_T2_13); also elsewhere on the board
JB2_P: U1.W10 (IO_L16P_T2_13); also elsewhere on the board
JB3_N: U1.Y13 (IO_L20N_T3_13); also elsewhere on the board
JB3_P: U1.Y12 (IO_L20P_T3_13); also elsewhere on the board
JB4_N: U1.Y11 (IO_L18N_T2_13); also elsewhere on the board
JB4_P: U1.W11 (IO_L18P_T2_13); also elsewhere on the board
LED0: U1.R14 (IO_L6N_T0_VREF_34); also elsewhere on the board
LED1: U1.P14 (IO_L6P_T0_34); also elsewhere on the board
LED2: U1.N16 (IO_L21N_T3_DQS_AD14N_35); also elsewhere on the board
LED3: U1.M14 (IO_L23P_T3_35); also elsewhere on the board
LED4_B: U1.L15 (IO_L22N_T3_AD7N_35); also elsewhere on the board
LED4_G: U1.G17 (IO_L16P_T2_35); also elsewhere on the board
LED4_R: U1.N15 (IO_L21P_T3_DQS_AD14P_35); also elsewhere on the board
LED5_B: U1.G14 (IO_0_35); also elsewhere on the board
LED5_G: U1.L14 (IO_L22P_T3_AD7P_35); also elsewhere on the board
LED5_R: U1.M15 (IO_L23N_T3_35); also elsewhere on the board
SPDIF_RX: U1.K14 (IO_L20P_T3_AD6P_35); also elsewhere on the board
SPDIF_TX: U1.J14 (IO_L20N_T3_AD6N_35); also elsewhere on the board
SW0: U1.M20 (IO_L7N_T1_AD2N_35); also elsewhere on the board
SW1: U1.M19 (IO_L7P_T1_AD2P_35); also elsewhere on the board
SYSCLK: U1.H16 (IO_L13P_T2_MRCC_35); also elsewhere on the board

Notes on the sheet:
BANK 35
BANK 34
VCC3V3
BANK 13

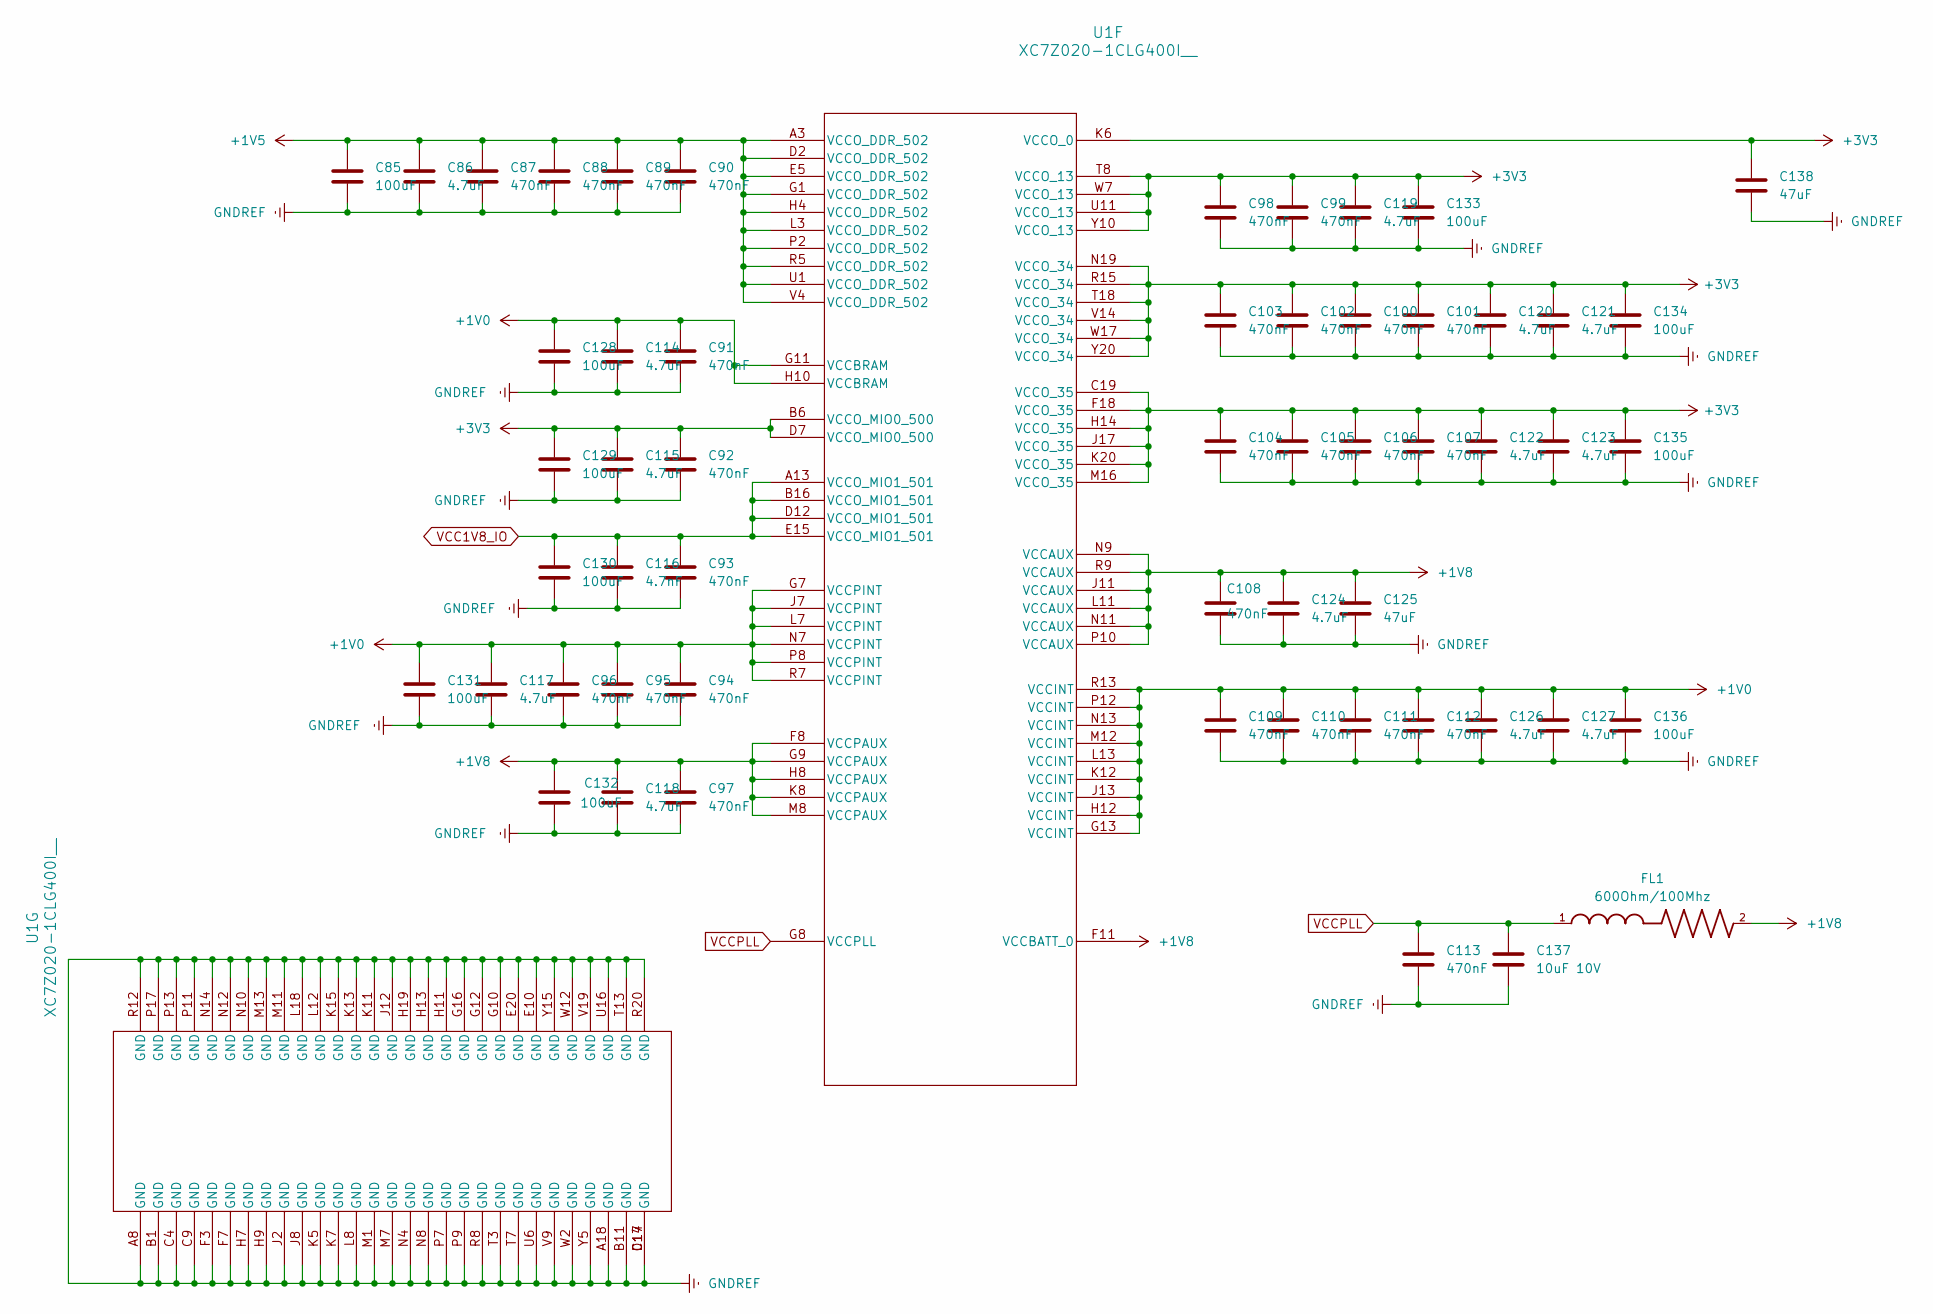
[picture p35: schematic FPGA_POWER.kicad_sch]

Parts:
C85, C128, C129, C130, C131, C132, C133, C134, C135, C136: 100uF; C_0805; LCSC PN c141660
C86, C114, C115, C117, C118, C119, C120, C121, C122, C123, C124, C126, C127: 4.7uF; C_0402; LCSC PN C2858031
C87, C88, C89, C90, C91, C92, C93, C94, C95, C96, C97, C98, C99, C100, C101, C102, C103, C104, C105, C106, C107, C108, C109, C110, C111, C112, C113: 470nF; C_0201_0603Metric; LCSC PN C5383023
C116: 4.7nF; C_0402; LCSC PN c84705
C125, C138: 47uF; C_0805; LCSC PN C124129
C137: 10uF 10V; C_0805; LCSC PN C15850
FL1: 600Ohm/100Mhz; BEADC1608X95N; LCSC PN C19330
U1: XC7Z020-1CLG400I__; CLG400_ZYNQ-7000_AMD; LCSC PN C1519081

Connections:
+1V0: C91.1, C94.1, C95.1, C96.1, C109.1, C110.1, C111.1, C112.1, C114.1, C117.1, C126.1, C127.1, C128.1, C131.1, C136.1, U1.G7 (VCCPINT), U1.G11 (VCCBRAM), U1.G13 (VCCINT), U1.H10 (VCCBRAM), U1.H12 (VCCINT), U1.J7 (VCCPINT), U1.J13 (VCCINT), U1.K12 (VCCINT), U1.L7 (VCCPINT), U1.L13 (VCCINT), U1.M12 (VCCINT), U1.N7 (VCCPINT), U1.N13 (VCCINT), U1.P8 (VCCPINT), U1.P12 (VCCINT), U1.R7 (VCCPINT), U1.R13 (VCCINT); also elsewhere on the board
+1V5: C85.1, C86.1, C87.1, C88.1, C89.1, C90.1, U1.A3 (VCCO_DDR_502), U1.D2 (VCCO_DDR_502), U1.E5 (VCCO_DDR_502), U1.G1 (VCCO_DDR_502), U1.H4 (VCCO_DDR_502), U1.L3 (VCCO_DDR_502), U1.P2 (VCCO_DDR_502), U1.R5 (VCCO_DDR_502), U1.U1 (VCCO_DDR_502), U1.V4 (VCCO_DDR_502); also elsewhere on the board
+1V8: C97.1, C108.1, C118.1, C124.1, C125.1, C132.1, FL1.2, U1.F8 (VCCPAUX), U1.F11 (VCCBATT_0), U1.G9 (VCCPAUX), U1.H8 (VCCPAUX), U1.J11 (VCCAUX), U1.K8 (VCCPAUX), U1.L11 (VCCAUX), U1.M8 (VCCPAUX), U1.N9 (VCCAUX), U1.N11 (VCCAUX), U1.P10 (VCCAUX), U1.R9 (VCCAUX); also elsewhere on the board
+3V3: C92.1, C98.1, C99.1, C100.1, C101.1, C102.1, C103.1, C104.1, C105.1, C106.1, C107.1, C115.1, C119.1, C120.1, C121.1, C122.1, C123.1, C129.1, C133.1, C134.1, C135.1, C138.1, U1.B6 (VCCO_MIO0_500), U1.C19 (VCCO_35), U1.D7 (VCCO_MIO0_500), U1.F18 (VCCO_35), U1.H14 (VCCO_35), U1.J17 (VCCO_35), U1.K6 (VCCO_0), U1.K20 (VCCO_35), U1.M16 (VCCO_35), U1.N19 (VCCO_34), U1.R15 (VCCO_34), U1.T8 (VCCO_13), U1.T18 (VCCO_34), U1.U11 (VCCO_13), U1.V14 (VCCO_34), U1.W7 (VCCO_13), U1.W17 (VCCO_34), U1.Y10 (VCCO_13), U1.Y20 (VCCO_34); also elsewhere on the board
GNDREF: C85.2, C86.2, C87.2, C88.2, C89.2, C90.2, C91.2, C92.2, C93.2, C94.2, C95.2, C96.2, C97.2, C98.2, C99.2, C100.2, C101.2, C102.2, C103.2, C104.2, C105.2, C106.2, C107.2, C108.2, C109.2, C110.2, C111.2, C112.2, C113.2, C114.2, C115.2, C116.2, C117.2, C118.2, C119.2, C120.2, C121.2, C122.2, C123.2, C124.2, C125.2, C126.2, C127.2, C128.2, C129.2, C130.2, C131.2, C132.2, C133.2, C134.2, C135.2, C136.2, C137.2, C138.2, U1.A8 (GND), U1.A18 (GND), U1.B1 (GND), U1.B11 (GND), U1.C4 (GND), U1.C9 (GND), U1.C14 (GND), U1.D17 (GND), U1.E10 (GND), U1.E20 (GND), U1.F3 (GND), U1.F7 (GND), U1.G10 (GND), U1.G12 (GND), U1.G16 (GND), U1.H7 (GND), U1.H9 (GND), U1.H11 (GND), U1.H13 (GND), U1.H19 (GND), U1.J2 (GND), U1.J8 (GND), U1.J12 (GND), U1.K5 (GND), U1.K7 (GND), U1.K11 (GND), U1.K13 (GND), U1.K15 (GND), U1.L8 (GND), U1.L12 (GND), U1.L18 (GND), U1.M1 (GND), U1.M7 (GND), U1.M11 (GND), U1.M13 (GND), U1.N4 (GND), U1.N8 (GND), U1.N10 (GND), U1.N12 (GND), U1.N14 (GND), U1.P7 (GND), U1.P9 (GND), U1.P11 (GND), U1.P13 (GND), U1.P17 (GND), U1.R8 (GND), U1.R12 (GND), U1.R20 (GND), U1.T3 (GND), U1.T7 (GND), U1.T13 (GND), U1.U6 (GND), U1.U16 (GND), U1.V9 (GND), U1.V19 (GND), U1.W2 (GND), U1.W12 (GND), U1.Y5 (GND), U1.Y15 (GND); also elsewhere on the board
VCC1V8_IO: C93.1, C116.1, C130.1, U1.A13 (VCCO_MIO1_501), U1.B16 (VCCO_MIO1_501), U1.D12 (VCCO_MIO1_501), U1.E15 (VCCO_MIO1_501); also elsewhere on the board
VCCPLL: C113.1, C137.1, FL1.1, U1.G8 (VCCPLL)

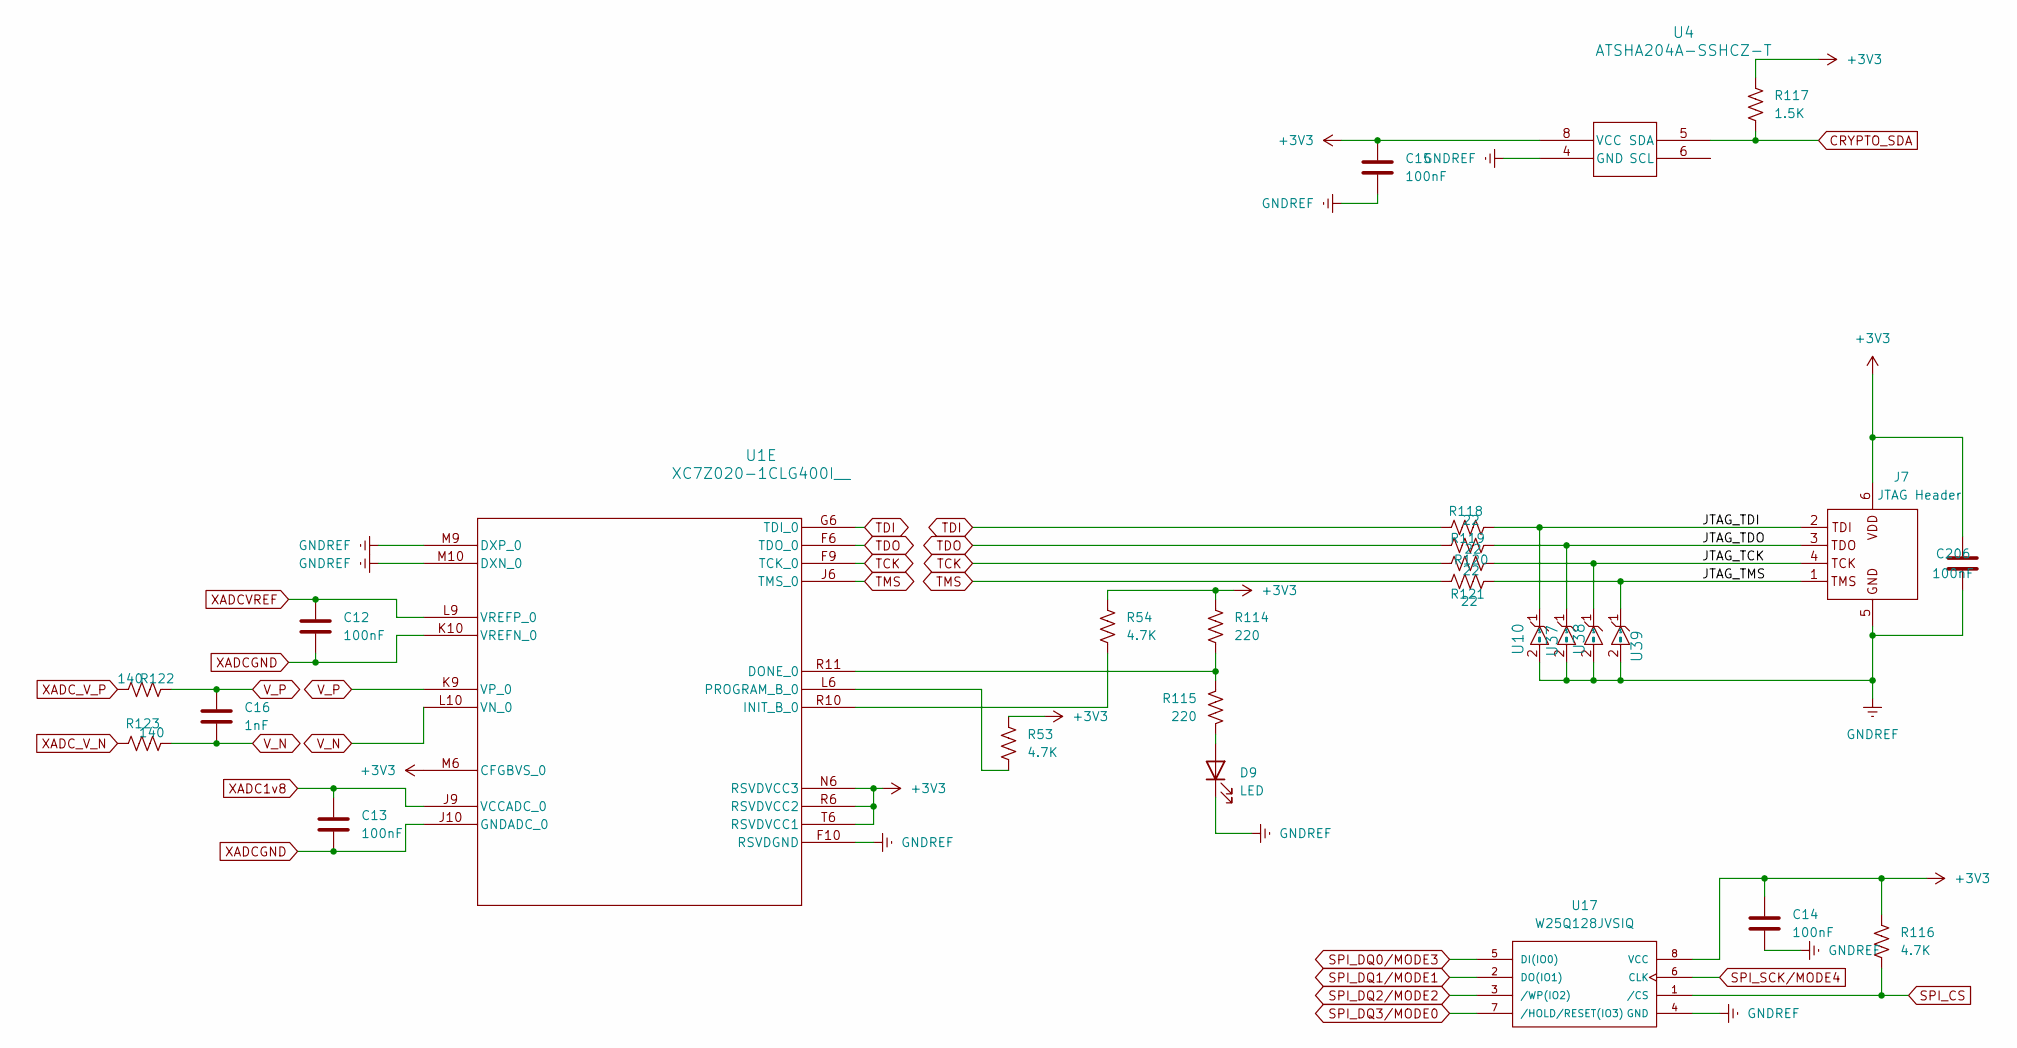
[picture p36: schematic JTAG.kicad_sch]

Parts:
C12, C13, C14, C15, C206: 100nF; C_0201_0603Metric; LCSC PN c307380
C16: 1nF; C_0402; LCSC PN C77018
D9: LED; LED_0402_1005Metric; LCSC PN C130723
J7: JTAG Header; PinHeader_1x06_P2.54mm_Vertical
R53, R54, R116: 4.7K; R_0201_0603Metric; LCSC PN C138135
R114, R115: 220; R_0402; LCSC PN C112291
R117: 1.5K; R_0402; LCSC PN C114759
R118, R119, R120, R121: 22; R_0201_0603Metric; LCSC PN C270355
R122, R123: 140; R_0402; LCSC PN C327016
U1: XC7Z020-1CLG400I__; CLG400_ZYNQ-7000_AMD; LCSC PN C1519081
U4: ATSHA204A-SSHCZ-T; SOIC8_4P9X3P9MC_MCH; LCSC PN C616025
U10, U37, U38, U39: TPD1E05U06DPYR; DIO_TPD1E05U06DPYR; LCSC PN C436349
U17: W25Q128JVSIQ; SOIC127P790X216-8N; PARTREV I; LCSC PN C97521

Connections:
+3V3: C14.1, C15.1, C206.1, J7.6 (VDD), R53.1, R54.1, R114.1, R116.1, R117.1, U1.M6 (CFGBVS_0), U1.N6 (RSVDVCC3), U1.R6 (RSVDVCC2), U1.T6 (RSVDVCC1), U4.8 (VCC), U17.8 (VCC); also elsewhere on the board
/JTAG/JTAG_TCK: J7.4 (TCK), R120.2, U38.1 (I/O)
/JTAG/JTAG_TDI: J7.2 (TDI), R118.2, U10.1 (I/O)
/JTAG/JTAG_TDO: J7.3 (TDO), R119.2, U37.1 (I/O)
/JTAG/JTAG_TMS: J7.1 (TMS), R121.2, U39.1 (I/O)
CRYPTO_SDA: R117.2, U4.5 (SDA); also elsewhere on the board
GNDREF: C14.2, C15.2, C206.2, D9.1 (K), J7.5 (GND), U1.F10 (RSVDGND), U1.M9 (DXP_0), U1.M10 (DXN_0), U4.4 (GND), U10.2 (GND), U17.4 (GND), U37.2 (GND), U38.2 (GND), U39.2 (GND); also elsewhere on the board
unnamed: D9.2 (A), R115.2
unnamed: R114.2, R115.1, U1.R11 (DONE_0)
unnamed: R54.2, U1.R10 (INIT_B_0)
unnamed: R53.2, U1.L6 (PROGRAM_B_0)
SPI_CS: R116.2, U17.1 (/CS); also elsewhere on the board
SPI_DQ0/MODE3: U17.5 (DI(IO0)); also elsewhere on the board
SPI_DQ1/MODE1: U17.2 (DO(IO1)); also elsewhere on the board
SPI_DQ2/MODE2: U17.3 (/WP(IO2)); also elsewhere on the board
SPI_DQ3/MODE0: U17.7 (/HOLD/RESET(IO3)); also elsewhere on the board
SPI_SCK/MODE4: U17.6 (CLK); also elsewhere on the board
TCK: R120.1, U1.F9 (TCK_0); also elsewhere on the board
TDI: R118.1, U1.G6 (TDI_0); also elsewhere on the board
TDO: R119.1, U1.F6 (TDO_0); also elsewhere on the board
TMS: R121.1, U1.J6 (TMS_0); also elsewhere on the board
V_N: C16.2, R123.2, U1.L10 (VN_0)
V_P: C16.1, R122.2, U1.K9 (VP_0)
XADC1v8: C13.1, U1.J9 (VCCADC_0)
XADCGND: C12.2, C13.2, U1.J10 (GNDADC_0), U1.K10 (VREFN_0); also elsewhere on the board
XADCVREF: C12.1, U1.L9 (VREFP_0); also elsewhere on the board
XADC_V_N: R123.1; also elsewhere on the board
XADC_V_P: R122.1; also elsewhere on the board

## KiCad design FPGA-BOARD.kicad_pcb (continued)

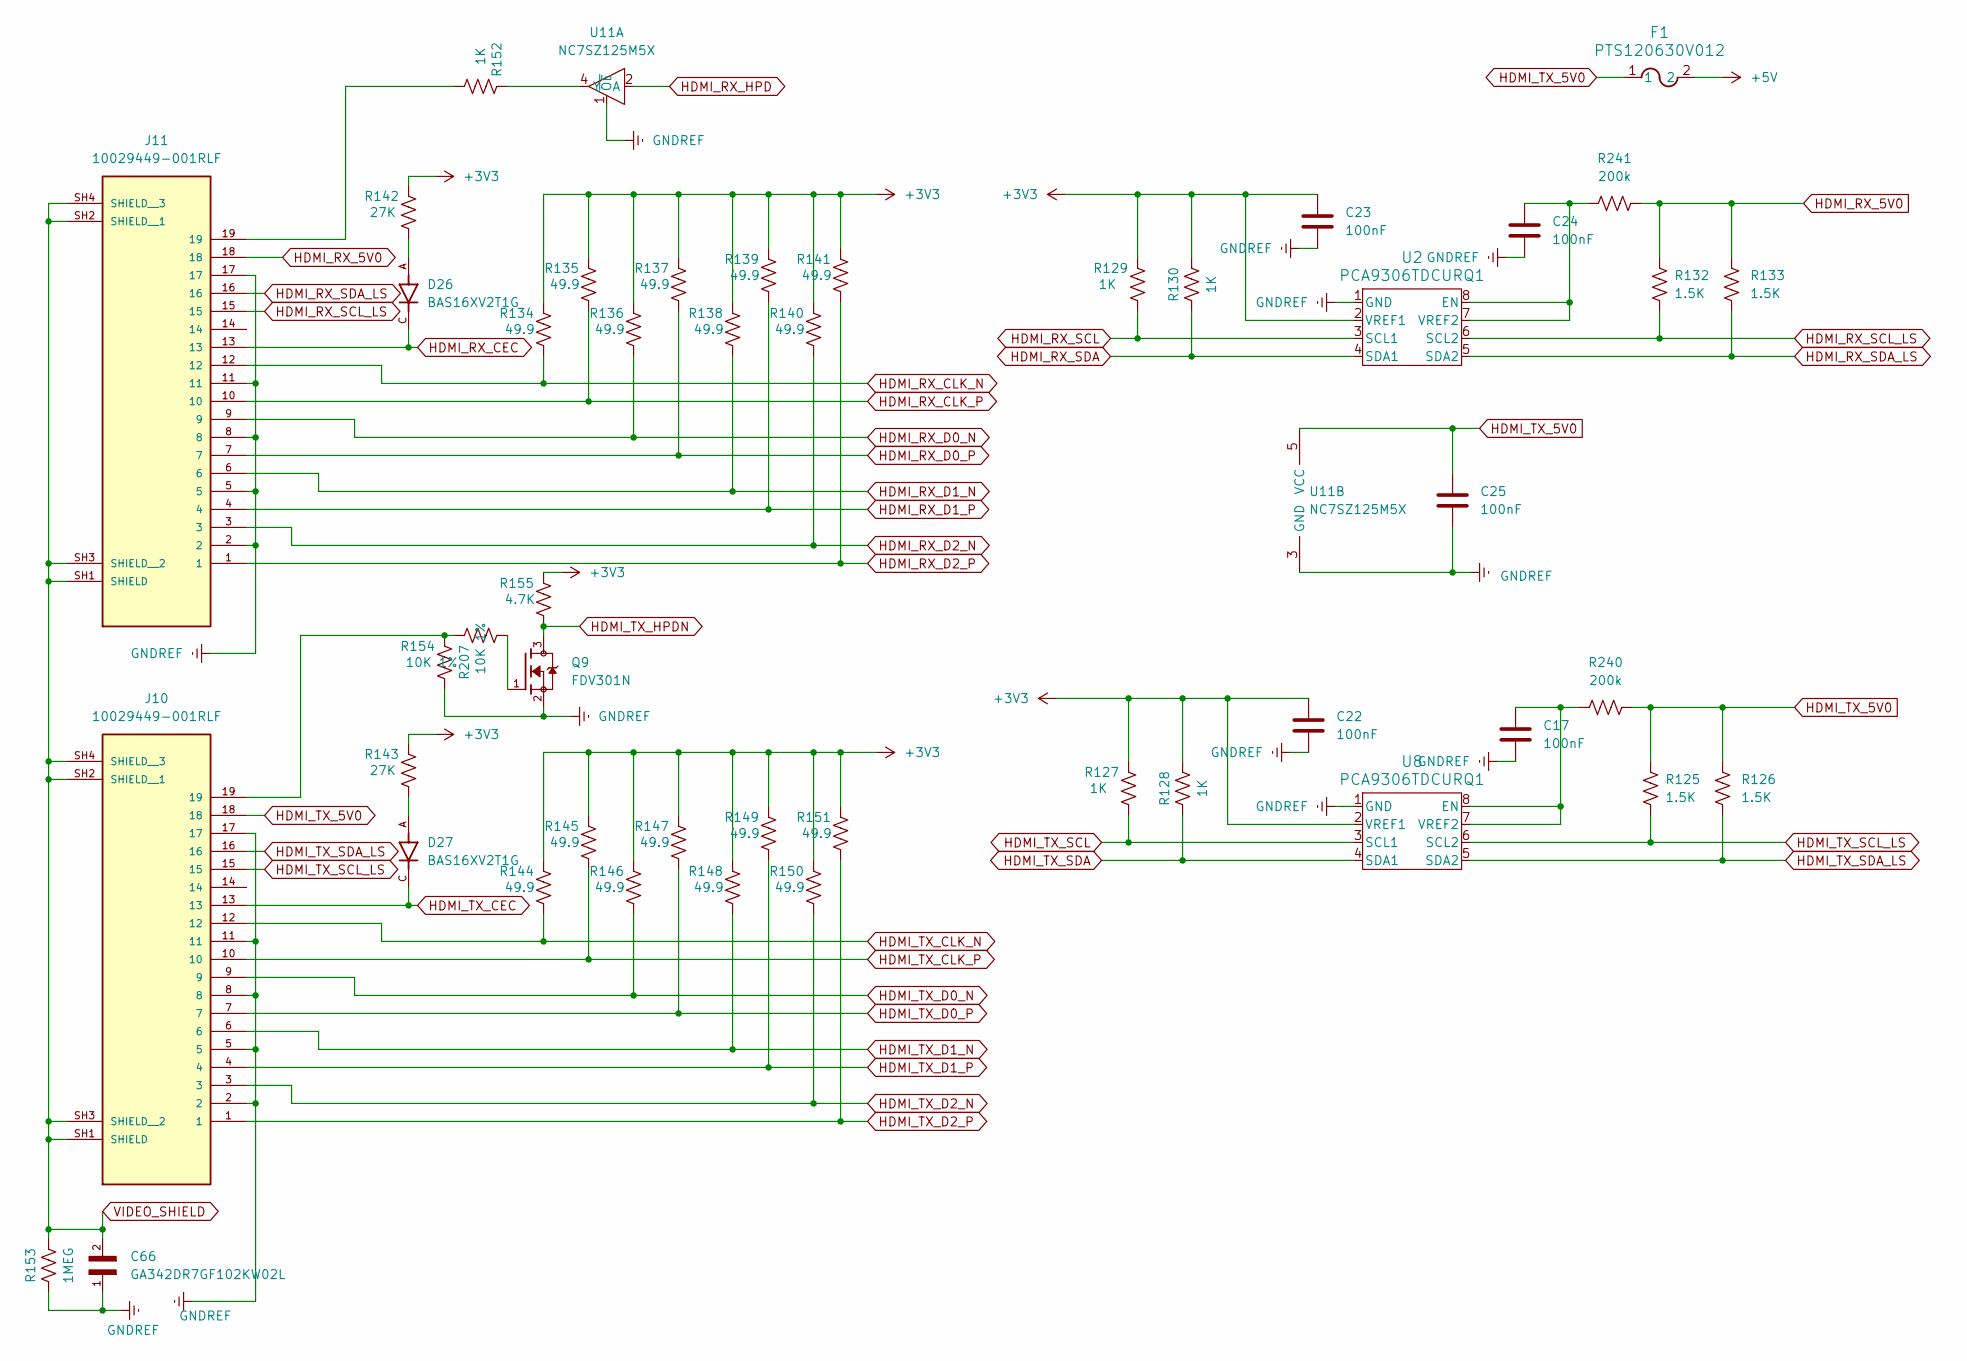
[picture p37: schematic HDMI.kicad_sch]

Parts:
C17, C22, C23, C24, C25: 100nF; C_0201_0603Metric; LCSC PN c307380
C66: GA342DR7GF102KW02L; CAPC4520X220N; LCSC PN C237595
D26, D27: BAS16XV2T1G; SODFL1608X70N; PARTREV 10; LCSC PN C152479
F1: PTS120630V012; LCSC PN C2442491
J10, J11: 10029449-001RLF; AMPHENOL_10029449-001RLF; PARTREV Y
Q9: FDV301N; PARTREV 8; LCSC PN C15310
R125, R126, R132, R133: 1.5K; R_0402; LCSC PN C114759
R127, R128, R129, R130, R152: 1K; R_0402; LCSC PN C106235
R134, R135, R136, R137, R138, R139, R140, R141, R144, R145, R146, R147, R148, R149, R150, R151: 49.9; R_0402; LCSC PN C87044
R142, R143: 27K; R_0402; LCSC PN C138022
R153: 1MEG; R_0402; LCSC PN C138033
R154, R207: 10K 1%; R_0402; LCSC PN C60490
R155: 4.7K; R_0201_0603Metric; LCSC PN C138135
R240, R241: 200k; R_0402; LCSC PN c114763
U2, U8: PCA9306TDCURQ1; DCU8; LCSC PN C33196
U11: NC7SZ125M5X; SC-74A_318BQ_ONS; LCSC PN C7420

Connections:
+3V3: C22.1, C23.1, R127.2, R128.2, R129.2, R130.2, R134.2, R135.2, R136.2, R137.2, R138.2, R139.2, R140.2, R141.2, R142.2, R143.2, R144.2, R145.2, R146.2, R147.2, R148.2, R149.2, R150.2, R151.2, R155.2, U2.2 (VREF1), U8.2 (VREF1); also elsewhere on the board
+5V: F1.2; also elsewhere on the board
GNDREF: C17.2, C22.2, C23.2, C24.2, C25.2, C66.1, J10.2, J10.5, J10.8, J10.11, J10.17, J11.2, J11.5, J11.8, J11.11, J11.17, Q9.2, R153.1, R154.1, U2.1 (GND), U8.1 (GND), U11.1 (~OE), U11.3 (GND); also elsewhere on the board
HDMI_RX_5V0: J11.18, R132.2, R133.2, R241.1
HDMI_RX_CEC: D26.C, J11.13; also elsewhere on the board
HDMI_RX_CLK_N: J11.12, R134.1; also elsewhere on the board
HDMI_RX_CLK_P: J11.10, R135.1; also elsewhere on the board
HDMI_RX_D0_N: J11.9, R136.1; also elsewhere on the board
HDMI_RX_D0_P: J11.7, R137.1; also elsewhere on the board
HDMI_RX_D1_N: J11.6, R138.1; also elsewhere on the board
HDMI_RX_D1_P: J11.4, R139.1; also elsewhere on the board
HDMI_RX_D2_N: J11.3, R140.1; also elsewhere on the board
HDMI_RX_D2_P: J11.1, R141.1; also elsewhere on the board
HDMI_RX_HPD: U11.2 (A); also elsewhere on the board
HDMI_RX_SCL: R129.1, U2.3 (SCL1); also elsewhere on the board
HDMI_RX_SCL_LS: J11.15, R132.1, U2.6 (SCL2)
HDMI_RX_SDA: R130.1, U2.4 (SDA1); also elsewhere on the board
HDMI_RX_SDA_LS: J11.16, R133.1, U2.5 (SDA2)
HDMI_TX_5V0: C25.1, F1.1, J10.18, R125.2, R126.2, R240.1, U11.5 (VCC)
HDMI_TX_CEC: D27.C, J10.13; also elsewhere on the board
HDMI_TX_CLK_N: J10.12, R144.1; also elsewhere on the board
HDMI_TX_CLK_P: J10.10, R145.1; also elsewhere on the board
HDMI_TX_D0_N: J10.9, R146.1; also elsewhere on the board
HDMI_TX_D0_P: J10.7, R147.1; also elsewhere on the board
HDMI_TX_D1_N: J10.6, R148.1; also elsewhere on the board
HDMI_TX_D1_P: J10.4, R149.1; also elsewhere on the board
HDMI_TX_D2_N: J10.3, R150.1; also elsewhere on the board
HDMI_TX_D2_P: J10.1, R151.1; also elsewhere on the board
HDMI_TX_HPDN: Q9.3, R155.1; also elsewhere on the board
HDMI_TX_SCL: R127.1, U8.3 (SCL1); also elsewhere on the board
HDMI_TX_SCL_LS: J10.15, R125.1, U8.6 (SCL2)
HDMI_TX_SDA: R128.1, U8.4 (SDA1); also elsewhere on the board
HDMI_TX_SDA_LS: J10.16, R126.1, U8.5 (SDA2)
unnamed: D26.A, R142.1
unnamed: D27.A, R143.1
unnamed: J10.19, R154.2, R207.2
unnamed: J11.19, R152.1
unnamed: Q9.1, R207.1
unnamed: C24.1, R241.2, U2.7 (VREF2), U2.8 (EN)
unnamed: C17.1, R240.2, U8.7 (VREF2), U8.8 (EN)
unnamed: R152.2, U11.4 (Y)
VIDEO_SHIELD: C66.2, J10.SH1 (SHIELD), J10.SH2 (SHIELD__1), J10.SH3 (SHIELD__2), J10.SH4 (SHIELD__3), J11.SH1 (SHIELD), J11.SH2 (SHIELD__1), J11.SH3 (SHIELD__2), J11.SH4 (SHIELD__3), R153.2

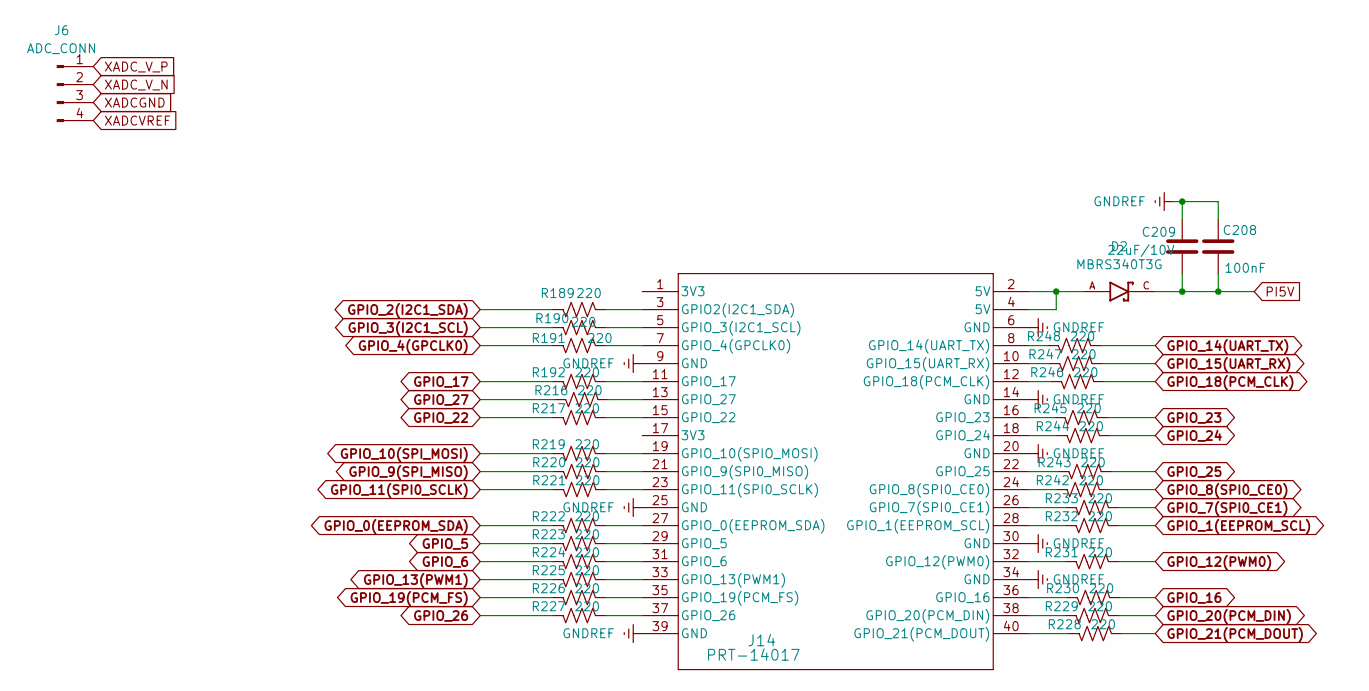
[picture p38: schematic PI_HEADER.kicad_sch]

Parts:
C208: 100nF; C_0201_0603Metric; LCSC PN c307380
C209: 22uF/10V; C_0805; LCSC PN C602037
D2: MBRS340T3G; DIOM7959X261N; PARTREV 14; LCSC PN C40326
J6: ADC_CONN; PinSocket_1x04_P2.54mm_Vertical
J14: PRT-14017; CONN_PRT-14017_SPK
R189, R190, R191, R192, R216, R217, R219, R220, R221, R222, R223, R224, R225, R226, R227, R228, R229, R230, R231, R232, R233, R242, R243, R244, R245, R246, R247, R248: 220; R_0402; LCSC PN C112291

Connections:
GNDREF: C208.1, C209.1, J14.6 (GND), J14.9 (GND), J14.14 (GND), J14.20 (GND), J14.25 (GND), J14.30 (GND), J14.34 (GND), J14.39 (GND); also elsewhere on the board
GPIO_0(EEPROM_SDA): R222.1; also elsewhere on the board
GPIO_1(EEPROM_SCL): R232.2; also elsewhere on the board
GPIO_2(I2C1_SDA): R189.1; also elsewhere on the board
GPIO_3(I2C1_SCL): R190.1; also elsewhere on the board
GPIO_4(GPCLK0): R191.1; also elsewhere on the board
GPIO_5: R223.1; also elsewhere on the board
GPIO_6: R224.1; also elsewhere on the board
GPIO_7(SPI0_CE1): R233.2; also elsewhere on the board
GPIO_8(SPI0_CE0): R242.2; also elsewhere on the board
GPIO_9(SPI_MISO): R220.1; also elsewhere on the board
GPIO_10(SPI_MOSI): R219.1; also elsewhere on the board
GPIO_11(SPI0_SCLK): R221.1; also elsewhere on the board
GPIO_12(PWM0): R231.2; also elsewhere on the board
GPIO_13(PWM1): R225.1; also elsewhere on the board
GPIO_14(UART_TX): R248.2; also elsewhere on the board
GPIO_15(UART_RX): R247.2; also elsewhere on the board
GPIO_16: R230.2; also elsewhere on the board
GPIO_17: R192.1; also elsewhere on the board
GPIO_18(PCM_CLK): R246.2; also elsewhere on the board
GPIO_19(PCM_FS): R226.1; also elsewhere on the board
GPIO_20(PCM_DIN): R229.2; also elsewhere on the board
GPIO_21(PCM_DOUT): R228.2; also elsewhere on the board
GPIO_22: R217.1; also elsewhere on the board
GPIO_23: R245.2; also elsewhere on the board
GPIO_24: R244.2; also elsewhere on the board
GPIO_25: R243.2; also elsewhere on the board
GPIO_26: R227.1; also elsewhere on the board
GPIO_27: R216.1; also elsewhere on the board
unnamed: D2.A, J14.2 (5V), J14.4 (5V)
unnamed: J14.3 (GPIO2(I2C1_SDA)), R189.2
unnamed: J14.27 (GPIO_0(EEPROM_SDA)), R222.2
unnamed: J14.28 (GPIO_1(EEPROM_SCL)), R232.1
unnamed: J14.5 (GPIO_3(I2C1_SCL)), R190.2
unnamed: J14.7 (GPIO_4(GPCLK0)), R191.2
unnamed: J14.29 (GPIO_5), R223.2
unnamed: J14.31 (GPIO_6), R224.2
unnamed: J14.26 (GPIO_7(SPI0_CE1)), R233.1
unnamed: J14.24 (GPIO_8(SPI0_CE0)), R242.1
unnamed: J14.21 (GPIO_9(SPI0_MISO)), R220.2
unnamed: J14.19 (GPIO_10(SPIO_MOSI)), R219.2
unnamed: J14.23 (GPIO_11(SPI0_SCLK)), R221.2
unnamed: J14.32 (GPIO_12(PWM0)), R231.1
unnamed: J14.33 (GPIO_13(PWM1)), R225.2
unnamed: J14.8 (GPIO_14(UART_TX)), R248.1
unnamed: J14.10 (GPIO_15(UART_RX)), R247.1
unnamed: J14.36 (GPIO_16), R230.1
unnamed: J14.11 (GPIO_17), R192.2
unnamed: J14.12 (GPIO_18(PCM_CLK)), R246.1
unnamed: J14.35 (GPIO_19(PCM_FS)), R226.2
unnamed: J14.38 (GPIO_20(PCM_DIN)), R229.1
unnamed: J14.40 (GPIO_21(PCM_DOUT)), R228.1
unnamed: J14.15 (GPIO_22), R217.2
unnamed: J14.16 (GPIO_23), R245.1
unnamed: J14.18 (GPIO_24), R244.1
unnamed: J14.22 (GPIO_25), R243.1
unnamed: J14.37 (GPIO_26), R227.2
unnamed: J14.13 (GPIO_27), R216.2
PI5V: C208.2, C209.2, D2.C; also elsewhere on the board
XADCGND: J6.3; also elsewhere on the board
XADCVREF: J6.4; also elsewhere on the board
XADC_V_N: J6.2; also elsewhere on the board
XADC_V_P: J6.1; also elsewhere on the board

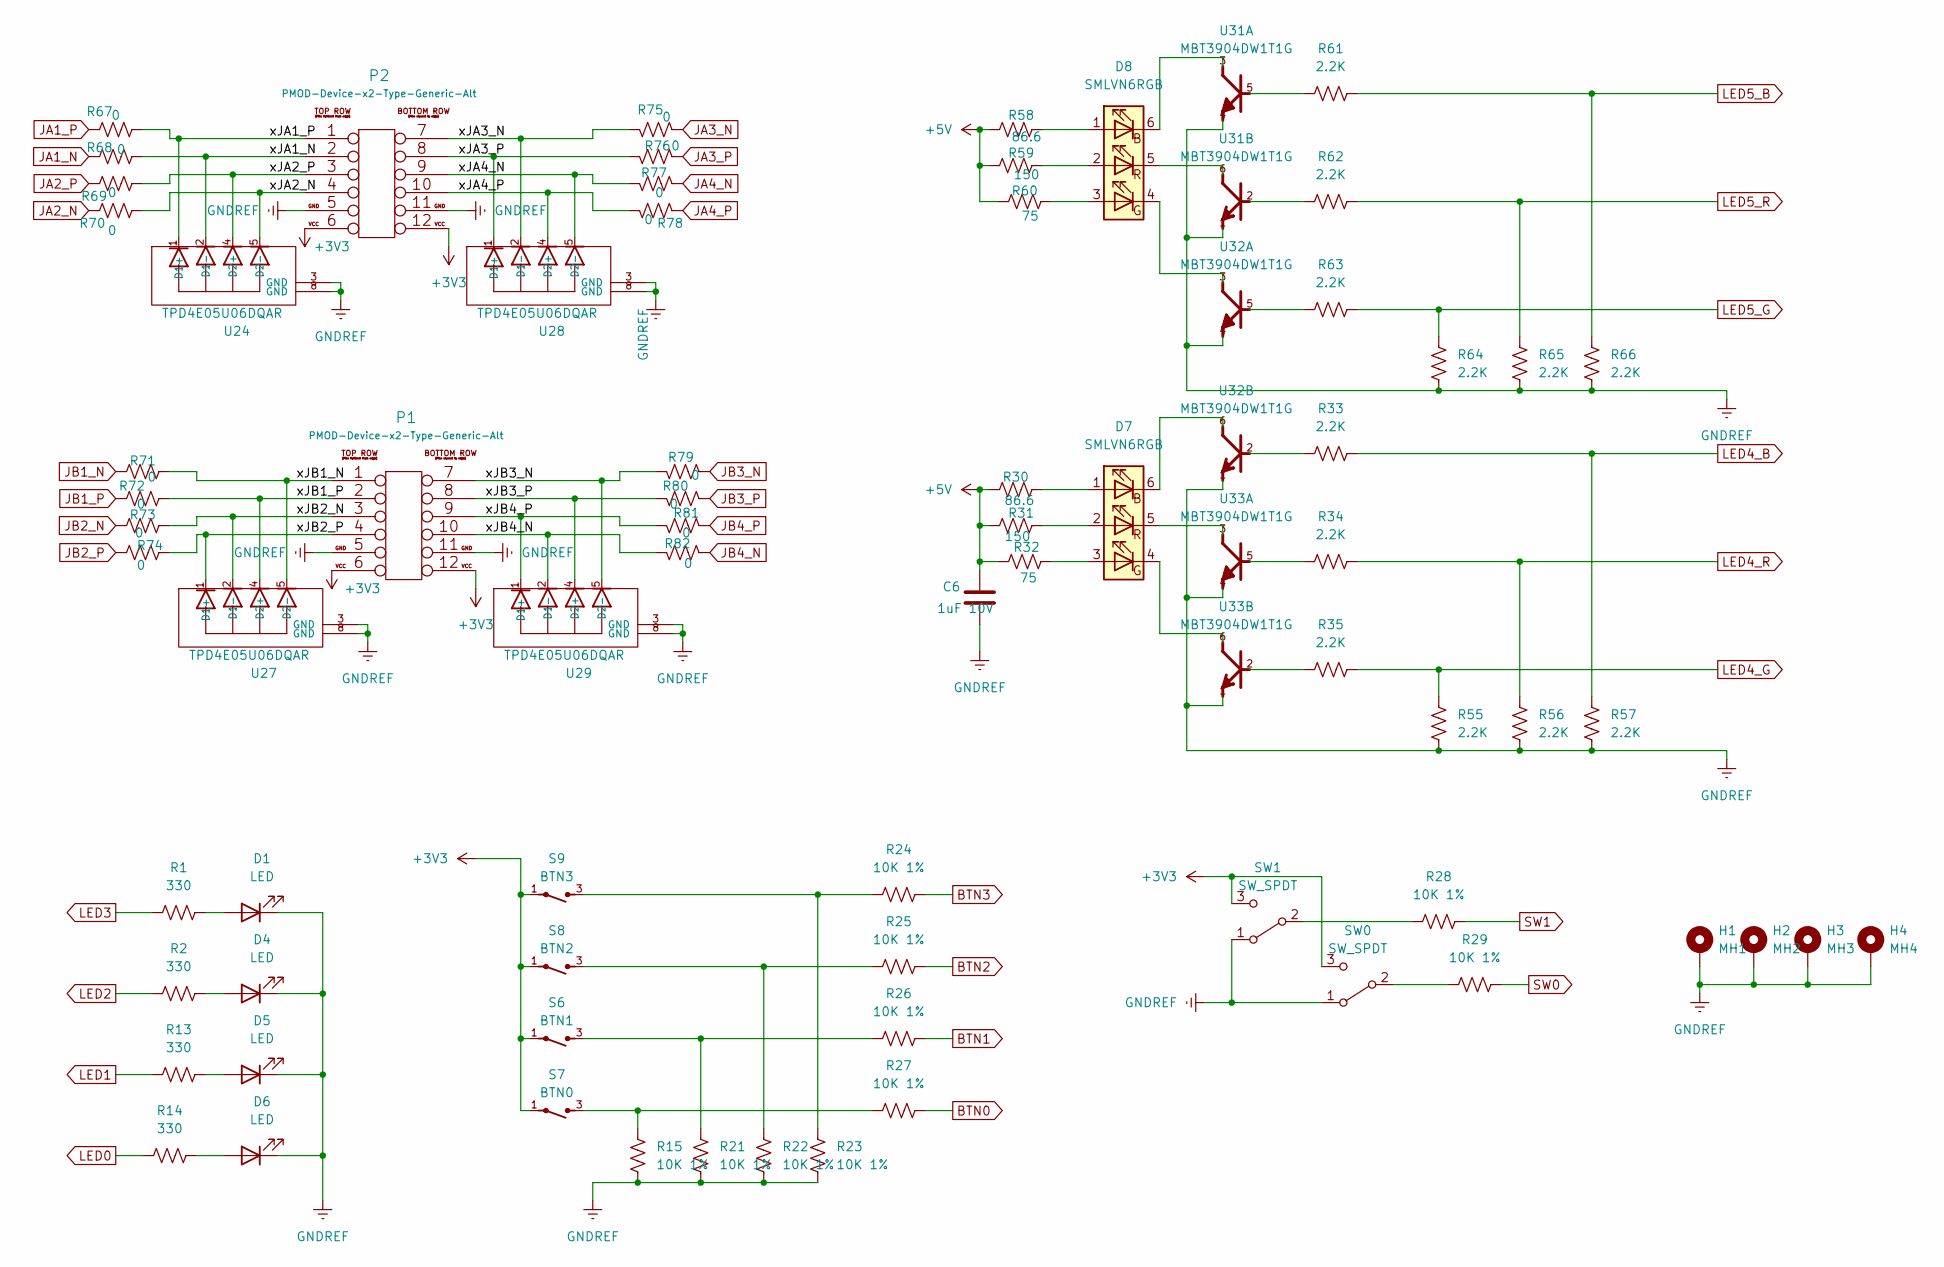
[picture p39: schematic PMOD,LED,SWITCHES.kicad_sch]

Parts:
C6: 1uF 10V; C_0402; LCSC PN C52923
D1, D4, D5, D6: LED; LED_0402_1005Metric; LCSC PN C130723
D7, D8: SMLVN6RGB; LED_SMLV56_ROM; LCSC PN C20110230
H1: MH1; MountingHole_2.2mm_M2_Pad
H2: MH2; MountingHole_2.2mm_M2_Pad
H3: MH3; MountingHole_2.2mm_M2_Pad
H4: MH4; MountingHole_2.2mm_M2_Pad
P1, P2: PMOD-Device-x2-Type-Generic-Alt; CONN_PPPC062LJBN-RC_SUL
R1, R2, R13, R14: 330; R_0402; LCSC PN C105875
R15, R21, R22, R23, R24, R25, R26, R27, R28, R29: 10K 1%; R_0402; LCSC PN C60490
R30, R58: 86.6; R_0402; LCSC PN C830266
R31, R59: 150; R_0402; LCSC PN C138054
R32, R60: 75; R_0402; LCSC PN C114757
R33, R34, R35, R55, R56, R57, R61, R62, R63, R64, R65, R66: 2.2K; R_0402; LCSC PN c114762
R67, R68, R69, R70, R71, R72, R73, R74, R75, R76, R77, R78, R79, R80, R81, R82: 0; R_0402; LCSC PN C106231
S6: BTN1; TS-1002S-050xxC_XNP; LCSC PN C455110
S7: BTN0; TS-1002S-050xxC_XNP; LCSC PN C455110
S8: BTN2; TS-1002S-050xxC_XNP; LCSC PN C455110
S9: BTN3; TS-1002S-050xxC_XNP; LCSC PN C455110
SW0, SW1: SW_SPDT; SW_EG1218
U24, U27, U28, U29: TPD4E05U06DQAR; IC_TPD4E05U06DQAR; PARTREV N; LCSC PN C138714
U31, U32, U33: MBT3904DW1T1G; SOT236; LCSC PN C110150

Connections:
+3V3: P1.6, P1.12, P2.6, P2.12, S6.1, S7.1, S8.1, S9.1, SW0.3 (C), SW1.3 (C); also elsewhere on the board
+5V: C6.1, R30.1, R31.1, R32.1, R58.1, R59.1, R60.1; also elsewhere on the board
/PMOD, LED, SWITCHES/xJA1_N: P2.2, R68.2, U24.2 (D1-)
/PMOD, LED, SWITCHES/xJA1_P: P2.1, R67.2, U24.1 (D1+)
/PMOD, LED, SWITCHES/xJA2_N: P2.4, R70.2, U24.5 (D2-)
/PMOD, LED, SWITCHES/xJA2_P: P2.3, R69.2, U24.4 (D2+)
/PMOD, LED, SWITCHES/xJA3_N: P2.7, R75.2, U28.2 (D1-)
/PMOD, LED, SWITCHES/xJA3_P: P2.8, R76.2, U28.1 (D1+)
/PMOD, LED, SWITCHES/xJA4_N: P2.9, R77.2, U28.5 (D2-)
/PMOD, LED, SWITCHES/xJA4_P: P2.10, R78.2, U28.4 (D2+)
/PMOD, LED, SWITCHES/xJB1_N: P1.1, R71.2, U27.5 (D2-)
/PMOD, LED, SWITCHES/xJB1_P: P1.2, R72.2, U27.4 (D2+)
/PMOD, LED, SWITCHES/xJB2_N: P1.3, R73.2, U27.2 (D1-)
/PMOD, LED, SWITCHES/xJB2_P: P1.4, R74.2, U27.1 (D1+)
/PMOD, LED, SWITCHES/xJB3_N: P1.7, R79.2, U29.5 (D2-)
/PMOD, LED, SWITCHES/xJB3_P: P1.8, R80.2, U29.4 (D2+)
/PMOD, LED, SWITCHES/xJB4_N: P1.10, R82.2, U29.2 (D1-)
/PMOD, LED, SWITCHES/xJB4_P: P1.9, R81.2, U29.1 (D1+)
BTN0: R27.2; also elsewhere on the board
BTN1: R26.2; also elsewhere on the board
BTN2: R25.2; also elsewhere on the board
BTN3: R24.2; also elsewhere on the board
GNDREF: C6.2, D1.1 (K), D4.1 (K), D5.1 (K), D6.1 (K), H1.1, H2.1, H3.1, H4.1, P1.5, P1.11, P2.5, P2.11, R15.2, R21.2, R22.2, R23.2, R55.1, R56.1, R57.1, R64.1, R65.1, R66.1, SW0.1 (A), SW1.1 (A), U24.3 (GND), U24.8 (GND), U27.3 (GND), U27.8 (GND), U28.3 (GND), U28.8 (GND), U29.3 (GND), U29.8 (GND), U31.1, U31.4, U32.1, U32.4, U33.1, U33.4; also elsewhere on the board
JA1_N: R68.1; also elsewhere on the board
JA1_P: R67.1; also elsewhere on the board
JA2_N: R70.1; also elsewhere on the board
JA2_P: R69.1; also elsewhere on the board
JA3_N: R75.1; also elsewhere on the board
JA3_P: R76.1; also elsewhere on the board
JA4_N: R77.1; also elsewhere on the board
JA4_P: R78.1; also elsewhere on the board
JB1_N: R71.1; also elsewhere on the board
JB1_P: R72.1; also elsewhere on the board
JB2_N: R73.1; also elsewhere on the board
JB2_P: R74.1; also elsewhere on the board
JB3_N: R79.1; also elsewhere on the board
JB3_P: R80.1; also elsewhere on the board
JB4_N: R82.1; also elsewhere on the board
JB4_P: R81.1; also elsewhere on the board
LED0: R14.1; also elsewhere on the board
LED1: R13.1; also elsewhere on the board
LED2: R2.1; also elsewhere on the board
LED3: R1.1; also elsewhere on the board
LED4_B: R33.2, R57.2; also elsewhere on the board
LED4_G: R35.2, R55.2; also elsewhere on the board
LED4_R: R34.2, R56.2; also elsewhere on the board
LED5_B: R61.2, R66.2; also elsewhere on the board
LED5_G: R63.2, R64.2; also elsewhere on the board
LED5_R: R62.2, R65.2; also elsewhere on the board
unnamed: D1.2 (A), R1.2
unnamed: D4.2 (A), R2.2
unnamed: D5.2 (A), R13.2
unnamed: D6.2 (A), R14.2
unnamed: D7.1 (BA), R30.2
unnamed: D7.6 (BK), U32.6
unnamed: D7.3 (GA), R32.2
unnamed: D7.4 (GK), U33.6
unnamed: D7.2 (RA), R31.2
unnamed: D7.5 (RK), U33.3
unnamed: D8.1 (BA), R58.2
unnamed: D8.6 (BK), U31.3
unnamed: D8.3 (GA), R60.2
unnamed: D8.4 (GK), U32.3
unnamed: D8.2 (RA), R59.2
unnamed: D8.5 (RK), U31.6
unnamed: R15.1, R27.1, S7.3
unnamed: R21.1, R26.1, S6.3
unnamed: R22.1, R25.1, S8.3
unnamed: R23.1, R24.1, S9.3
unnamed: R33.1, U32.2
unnamed: R34.1, U33.5
unnamed: R35.1, U33.2
unnamed: R61.1, U31.5
unnamed: R62.1, U31.2
unnamed: R63.1, U32.5
unnamed: R29.1, SW0.2 (B)
unnamed: R28.1, SW1.2 (B)
SW0: R29.2; also elsewhere on the board
SW1: R28.2; also elsewhere on the board

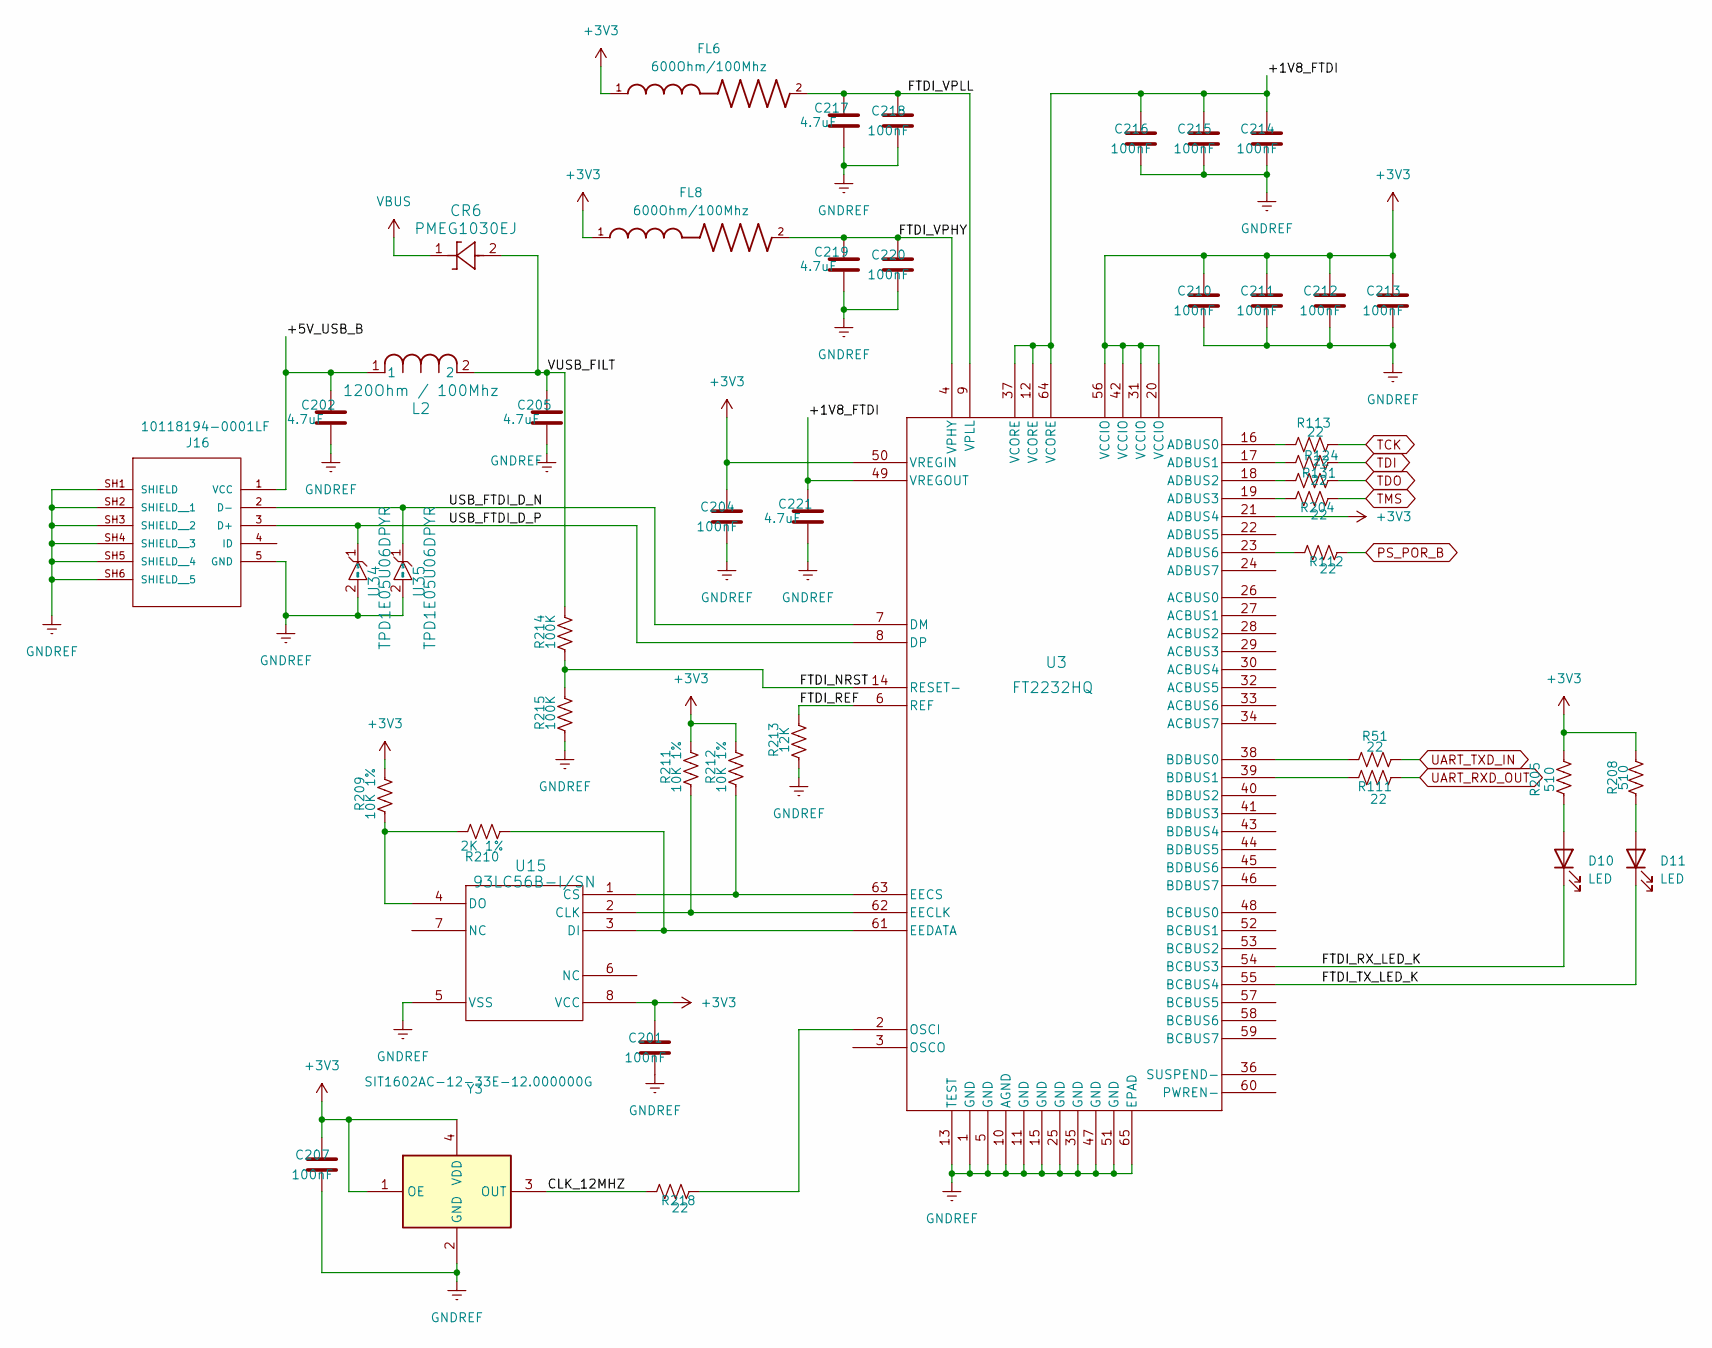
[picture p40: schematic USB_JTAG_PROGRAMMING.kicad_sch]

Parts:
C201, C204, C207, C210, C211, C212, C213, C214, C215, C216, C218, C220: 100nF; C_0201_0603Metric; LCSC PN c307380
C202, C205, C217, C219, C221: 4.7uF; C_0402; LCSC PN C2858031
CR6: PMEG1030EJ; SOD323F_NXP; LCSC PN C133633
D10, D11: LED; LED_0402_1005Metric; LCSC PN C130723
FL6, FL8: 600Ohm/100Mhz; BEADC1608X95N; LCSC PN C19330
J16: 10118194-0001LF; AMPHENOL_10118194-0001LF; PARTREV D
L2: 120Ohm / 100Mhz; IND_BLM18_0603_MUR; LCSC PN C14709
R51, R111, R112, R113, R124, R131, R204, R218: 22; R_0201_0603Metric; LCSC PN C270355
R205, R208: 510; R_0201_0603Metric; LCSC PN C18164337
R209, R211, R212: 10K 1%; R_0402; LCSC PN C60490
R210: 2K 1%; R_0402; LCSC PN C60488
R213: 12K; R_0201_0603Metric; LCSC PN C2092166
R214, R215: 100K; R_0402; LCSC PN C60491
U3: FT2232HQ; 64QFN_FT2232HQ_FTD; LCSC PN C3025148
U15: 93LC56B-I/SN; SOIC8-N_MC_MCH; LCSC PN C183620
U34, U35: TPD1E05U06DPYR; DIO_TPD1E05U06DPYR; LCSC PN C436349
Y3: SIT1602AC-12-33E-12.000000G; SIT1602AC1233E12000000G; Mouser Part Number 788-1602AC1233E12.G

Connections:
+3V3: C201.1, C204.1, C207.1, C210.1, C211.1, C212.1, C213.1, FL6.1, FL8.1, R205.2, R208.2, R209.2, R211.2, R212.2, U3.20 (VCCIO), U3.21 (ADBUS4), U3.31 (VCCIO), U3.42 (VCCIO), U3.50 (VREGIN), U3.56 (VCCIO), U15.8 (VCC), Y3.1 (OE), Y3.4 (VDD); also elsewhere on the board
/USB_JTAG_PROGRAMMING/+1V8_FTDI: C214.1, C215.1, C216.1, C221.1, U3.12 (VCORE), U3.37 (VCORE), U3.49 (VREGOUT), U3.64 (VCORE)
/USB_JTAG_PROGRAMMING/+5V_USB_B: C202.1, J16.1 (VCC), L2.1
/USB_JTAG_PROGRAMMING/CLK_12MHZ: R218.1, Y3.3 (OUT)
/USB_JTAG_PROGRAMMING/FTDI_NRST: R214.1, R215.2, U3.14 (RESET-)
/USB_JTAG_PROGRAMMING/FTDI_REF: R213.2, U3.6 (REF)
/USB_JTAG_PROGRAMMING/FTDI_RX_LED_K: D10.1 (K), U3.54 (BCBUS3)
/USB_JTAG_PROGRAMMING/FTDI_TX_KED_K: D11.1 (K), U3.55 (BCBUS4)
/USB_JTAG_PROGRAMMING/FTDI_VPHY: C219.1, C220.1, FL8.2, U3.4 (VPHY)
/USB_JTAG_PROGRAMMING/FTDI_VPLL: C217.1, C218.1, FL6.2, U3.9 (VPLL)
/USB_JTAG_PROGRAMMING/USB_FTDI_D_N: J16.2 (D-), U3.7 (DM), U35.1 (I/O)
/USB_JTAG_PROGRAMMING/USB_FTDI_D_P: J16.3 (D+), U3.8 (DP), U34.1 (I/O)
/USB_JTAG_PROGRAMMING/VUSB_FILT: C205.1, CR6.2, L2.2, R214.2
GNDREF: C201.2, C202.2, C204.2, C205.2, C207.2, C210.2, C211.2, C212.2, C213.2, C214.2, C215.2, C216.2, C217.2, C218.2, C219.2, C220.2, C221.2, J16.5 (GND), J16.SH1 (SHIELD), J16.SH2 (SHIELD__1), J16.SH3 (SHIELD__2), J16.SH4 (SHIELD__3), J16.SH5 (SHIELD__4), J16.SH6 (SHIELD__5), R213.1, R215.1, U3.1 (GND), U3.5 (GND), U3.10 (AGND), U3.11 (GND), U3.13 (TEST), U3.15 (GND), U3.25 (GND), U3.35 (GND), U3.47 (GND), U3.51 (GND), U3.65 (EPAD), U15.5 (VSS), U34.2 (GND), U35.2 (GND), Y3.2 (GND); also elsewhere on the board
unnamed: D10.2 (A), R205.1
unnamed: D11.2 (A), R208.1
unnamed: R113.1, U3.16 (ADBUS0)
unnamed: R124.1, U3.17 (ADBUS1)
unnamed: R131.1, U3.18 (ADBUS2)
unnamed: R204.1, U3.19 (ADBUS3)
unnamed: R112.1, U3.23 (ADBUS6)
unnamed: R51.1, U3.38 (BDBUS0)
unnamed: R111.1, U3.39 (BDBUS1)
unnamed: R218.2, U3.2 (OSCI)
unnamed: R211.1, U3.62 (EECLK), U15.2 (CLK)
unnamed: R212.1, U3.63 (EECS), U15.1 (CS)
unnamed: R210.1, U3.61 (EEDATA), U15.3 (DI)
unnamed: R209.1, R210.2, U15.4 (DO)
PS_POR_B: R112.2; also elsewhere on the board
TCK: R113.2; also elsewhere on the board
TDI: R124.2; also elsewhere on the board
TDO: R131.2; also elsewhere on the board
TMS: R204.2; also elsewhere on the board
UART_RXD_OUT: R111.2; also elsewhere on the board
UART_TXD_IN: R51.2; also elsewhere on the board
VBUS: CR6.1; also elsewhere on the board

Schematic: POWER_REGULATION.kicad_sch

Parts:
C7, C20, C27: 4.7uF; C_0402; LCSC PN C2858031
C18, C19, C28, C32, C199, C234: 100nF; C_0201_0603Metric; LCSC PN c307380
C21: 1uF 10V; C_0402; LCSC PN C52923
C26: 470nF; C_0201_0603Metric; LCSC PN C5383023
C29: 22nF; C_0402; LCSC PN c337699
C30: 100nF 10V; C_0402; LCSC PN C77020
C31, C192, C193, C194, C195, C196, C197, C198: 10uF 10V; C_0805; LCSC PN C15850
CR7: BZT52C12-7-F; SOD123_DIO; LCSC PN C19077410
D37: SMBJ15CA-E3_52; DIOM5436X244N; Manufacturer_Part_Number SMBJ15CA-E3/52; LCSC PN C435933
FL2, FL5, FL9: 600Ohm/100Mhz; BEADC1608X95N; LCSC PN C19330
J1: PJ-102AH; CUI_PJ-102AH
J2: GND; PinHeader_1x01_P2.54mm_Vertical
J3: Conn_01x03_Pin; PinHeader_1x03_P2.54mm_Vertical
J17: Conn_01x02_Pin; PinHeader_1x02_P2.54mm_Vertical
J18: +3V3; PinHeader_1x01_P2.54mm_Vertical
J20: +1V5; PinHeader_1x01_P2.54mm_Vertical
J21: +1V0; PinHeader_1x01_P2.54mm_Vertical
J22: VCC_1V8IO; PinHeader_1x01_P2.54mm_Vertical
L4: NR5040T2R2N/2.2uH; IND_TAIYO_NR5040_TAY; LCSC PN C223063
Q7: DMG2305UX-13; DMG2305UX_13; PARTREV 09/2018; LCSC PN C144153
R83: 100K; R_0402; LCSC PN C60491
R84: 4.7k; R_0402; LCSC PN C105871
R85: 20K 1%; R_0402; LCSC PN C93942
R86, R89: 10K 1%; R_0402; LCSC PN C60490
R87: 13.3K/1%; R_0402; LCSC PN C274352
R88: 69.8K/1%; R_0402; LCSC PN C5126210
R90: 62k/1%; R_0402; LCSC PN C137950
R91: 0; R_0402; LCSC PN C106231
U14: TLV62130RGTT; LCSC PN C122479
U16: REF3012; SOT-23; LCSC PN C34674

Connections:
+1V0: J21.1; also elsewhere on the board
+1V5: J20.1; also elsewhere on the board
+1V8: C21.1, FL2.1; also elsewhere on the board
+3V3: C7.1, C19.1, FL9.1, J18.1; also elsewhere on the board
+5V: J3.2, J17.1, R85.1; also elsewhere on the board
/POWER_REGULATION/VUSB: J3.3, Q7.3
AVCC3V3: C20.1, C199.1, C234.1, FL9.2; also elsewhere on the board
EN_1: R85.2, R86.1; also elsewhere on the board
GNDREF: C7.2, C19.2, C20.2, C21.2, C28.2, C29.2, C30.2, C31.2, C192.2, C193.2, C194.2, C195.2, C196.2, C197.2, C198.2, C199.2, C234.2, D37.2, FL5.1, J1.2, J1.3, J2.1, R84.2, R86.2, R87.2, R89.2, U14.6 (AGND), U14.8 (DEF), U14.15 (PGND@1), U14.16 (PGND@2), U14.17 (GND), U14.18, U14.19, U14.20, U14.21, U14.22; also elsewhere on the board
unnamed: C27.2, CR7.2, Q7.1, R83.2, R84.1
unnamed: C28.1, R89.1, R90.2, U14.13 (EN)
unnamed: R87.1, R88.2, U14.5 (FB)
unnamed: R91.2, U14.7 (FSW)
unnamed: C29.1, U14.9 (SS/TR)
unnamed: L4.2, U14.1 (SW@1), U14.2 (SW@2), U14.3 (SW@3)
PI5V: J17.2; also elsewhere on the board
REG5V0: C31.1, J3.1, L4.1, R88.1, R91.1, U14.14 (VOS)
VBUS: C27.1, CR7.1, Q7.2, R83.1; also elsewhere on the board
VCC1V8_IO: J22.1; also elsewhere on the board
VU: C30.1, C192.1, C193.1, C194.1, C195.1, C196.1, C197.1, C198.1, D37.1, J1.1, R90.1, U14.10 (AVIN), U14.11 (PVIN@1), U14.12 (PVIN@2)
XADC1V8: C26.1, C32.1, FL2.2, U16.1 (IN)
XADCGND: C18.2, C26.2, C32.2, FL5.2, U16.3 (GND); also elsewhere on the board
XADCVREF: C18.1, U16.2 (OUT); also elsewhere on the board

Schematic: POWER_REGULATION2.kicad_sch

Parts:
C33, C155, C162, C165, C168, C171, C174: 100nF; C_0201_0603Metric; LCSC PN c307380
C81, C146, C172: 4.7uF; C_0402; LCSC PN C2858031
C139, C140, C141, C142, C156, C164, C167, C170, C200: 22uF/10V; C_0805; LCSC PN C602037
C143: 10uF 10V; C_0805; LCSC PN C15850
C144, C173, C203: 1uF 10V; C_0402; LCSC PN C52923
C145: 3.3uF/10V; C_0603; LCSC PN C528975
C147: 1.5nF; C_0201_0603Metric; LCSC PN C2184288
C148, C154, C157, C160: 33nF; C_0201_0603Metric; LCSC PN C161475
C149, C151, C153, C159, C161, C163, C166, C169: 10pF; C_0201_0603Metric; LCSC PN C76921
C150: 150pF; C_0201_0603Metric; LCSC PN C3843470
C152: 1.2nF; C_0201_0603Metric; LCSC PN C913747
C158: 330pF; C_0201_0603Metric; LCSC PN C2184280
CR2: 1SS352; USC_TOS; LCSC PN C15885
D3: LED; LED_0402_1005Metric; LCSC PN C130719
L3: NR5040T2R2N/2.2uH; IND_TAIYO_NR5040_TAY; LCSC PN C223063
L5: SRP6540-1R5M 1.5uH; IND_SRP6540-1R5M; LCSC PN C3223801
L6, L7: NR5040T4R7N/ 4.7uH; IND_TAIYO_NR5040_TAY; LCSC PN C223064
Q8: FDV301N; PARTREV 8; LCSC PN C15310
R92, R187: 15K; R_0402; LCSC PN C114761
R93: 4.7k; R_0402; LCSC PN C105871
R94: 680; R_0201_0603Metric; LCSC PN C158391
R97: 33K; R_0402; LCSC PN C138003
R98: 100K; R_0402; LCSC PN C60491
R99, R206: 10K 1%; R_0402; LCSC PN C60490
R100: 180K; R_0402; LCSC PN C138046
R101: 75K; R_0402; LCSC PN C137935
R102: 150K; R_0402; LCSC PN C93947
R103: 8.87K/1%; R_0402; LCSC PN C48391747
R104, R108: 10.2K/1%; R_0402; LCSC PN C138069
R105: 20K 1%; R_0402; LCSC PN C93942
R106: 16K/1%; R_0402; LCSC PN C163487
R107: 31.6K/1%; R_0402; LCSC PN C276265
R109: 8.2K/1%; R_0402; LCSC PN C137929
R110: 30K/1%; R_0402; LCSC PN C138008
R188: 82; R_0402; LCSC PN C163453
S1: PTS645SK50SMTR92LFS; SW_PTS645SK50SMTR92LFS; LCSC PN C221872
U9: SIP32510DT-T1-GE3; SIP32510DT-T1-GE3_VIS
U19: NL17SZ17XV5T2G; SOT553-5_ONS; LCSC PN C152502
U21: NC7WZ07P6X; MPN NC7WZ07P6X; LCSC PN C95342
U22: TPS65400RGZT; RGZ0048B; PARTREV D; LCSC PN C201658
U40: TPS22918DBVR; DBV6_TEX; LCSC PN C131941

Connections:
+1V0: C169.1, C170.1, L3.1, R109.1; also elsewhere on the board
+1V5: C156.1, C161.1, L7.1, R103.1; also elsewhere on the board
+1V8: C163.1, C164.1, C172.1, C173.1, L6.1, R105.1, U9.5 (IN), U9.6 (IN), U40.1 (VIN); also elsewhere on the board
+3V3: C33.1, C166.1, C167.1, C200.1, D3.2 (A), L5.1, R92.1, R93.1, R107.1, U19.5 (VCC); also elsewhere on the board
+5V: C139.1, C140.1, C141.1, C142.1, C144.1, U22.5 (PVIN1), U22.6 (PVIN2), U22.22 (VIN), U22.30 (PVIN3), U22.31 (PVIN4); also elsewhere on the board
CE: U22.23 (CE)
EN_1: U22.13 (ENSW2), U22.27 (ENSW3), U22.34 (ENSW4), U22.48 (ENSW1/ENSEQ); also elsewhere on the board
GNDREF: C33.2, C81.2, C139.2, C140.2, C141.2, C142.2, C143.1, C144.2, C145.2, C146.2, C147.1, C148.1, C149.1, C150.1, C151.1, C152.1, C153.1, C154.1, C156.2, C157.1, C158.1, C159.1, C160.1, C164.2, C167.2, C170.2, C171.2, C172.2, C173.2, C174.2, C200.2, C203.2, Q8.2, R102.1, R104.2, R106.2, R108.2, R110.2, R188.2, R206.1, S1.3, U9.4 (GND), U19.3 (GND), U22.7 (PGND1), U22.8 (PGND2), U22.21 (AGND), U22.49 (PGND), U22.V, U40.2 (GND), U40.4 (CT), U40.5 (QOD); also elsewhere on the board
unnamed: C147.2, R97.1
unnamed: C150.2, R98.1
unnamed: C152.2, R101.1
unnamed: C158.2, R100.1
unnamed: D3.1 (K), R94.1
unnamed: Q8.3, R94.2
unnamed: C168.1, U22.1 (CB1)
unnamed: C165.1, U22.12 (CB2)
unnamed: C162.1, U22.28 (CB3)
unnamed: C155.1, U22.33 (CB4)
unnamed: C149.2, R97.2, U22.46 (COMP1)
unnamed: C151.2, R98.2, U22.15 (COMP2)
unnamed: C159.2, R100.2, U22.25 (COMP3)
unnamed: C153.2, R101.2, U22.36 (COMP4)
unnamed: R206.2, U22.38 (I2CADDR)
unnamed: R102.2, U22.40 (RCLOCK_SYNC)
unnamed: C148.2, U22.45 (SS1/PG1)
unnamed: C157.2, U22.16 (SS2/PG2)
unnamed: C160.2, U22.24 (SS3/PG3)
unnamed: C154.2, U22.37 (SS4/PG4)
unnamed: C168.2, L3.2, U22.2 (SW1), U22.3 (SW1__1), U22.4 (SW1__2)
unnamed: C165.2, L5.2, U22.9 (SW2), U22.10 (SW2__1), U22.11 (SW2__2)
unnamed: C162.2, L6.2, U22.29 (SW3)
unnamed: C155.2, L7.2, U22.32 (SW4)
unnamed: C146.1, U22.19 (VDDA)
unnamed: C143.2, U22.18 (VDDG)
unnamed: C169.2, R109.2, R110.1, U22.47 (VFB1)
unnamed: C166.2, R107.2, R108.1, U22.14 (VFB2)
unnamed: C163.2, R105.2, R106.1, U22.26 (VFB3)
unnamed: C161.2, R103.2, R104.1, U22.35 (VFB4)
PG_ALL: CR2.1, R92.2, R187.2, U9.3 (EN), U22.17 (PGOOD), U40.3 (ON)
PG_ALL_DLY: C81.1, CR2.2, R187.1, U19.2
PG_ALL_EDGE: Q8.1, U19.4, U21.3 (A2)
PS_POR_B: R93.2, S1.1, U21.4 (Y2); also elsewhere on the board
RST_N: R99.1, U22.39 (~RST)
SCL: U22.43 (SCL)
SDA: U22.42 (SDA)
VCC1V8_IO: C171.1, C174.1, C203.1, R188.1, U9.1 (OUT), U9.2 (OUT), U40.6 (VOUT); also elsewhere on the board
VDDD: C145.1, R99.2, U22.20 (VDDD)

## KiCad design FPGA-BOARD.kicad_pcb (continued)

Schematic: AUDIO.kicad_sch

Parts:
C1, C2, C187, C189, C190, C191: 100nF; C_0201_0603Metric; LCSC PN c307380
C3: 820pF 5%; C_0402; LCSC PN c307452
C52: GA342DR7GF102KW02L; CAPC4520X220N; LCSC PN C237595
C175, C178: 1nF 5%; C_0402; LCSC PN c76947
C177: 150pF 5%; C_0402; LCSC PN c76951
C179: 100uF; C_0805; LCSC PN c141660
C180: T491B157M006AT; CAPMP3.7X2.8_2.1N_KEM
C182: 1uF 10V; C_0402; LCSC PN C52923
C183, C186: 100nF 10V; C_0402; LCSC PN C77020
C184: 10nF; C_0201_0603Metric; LCSC PN c85930
C185: 4.7uF; C_0402; LCSC PN C2858031
C188: 2.2uF; C_0402; LCSC PN c170151
CR3: BZT52C12-7-F; SOD123_DIO; LCSC PN C19077410
F2: PRG18BB330MB1RB; FUSE_PRG-18_MUR; LCSC PN C133974
J9: SJ1-3525NG; CUI_SJ1-3525NG
J15: USB-A-S-X-X-SM2; SAMTEC_USB-A-S-X-X-SM2; PARTREV T; LCSC PN C6906824
Q10: DMG2305UX-13; DMG2305UX_13; PARTREV 09/2018; LCSC PN C144153
R3, R16, R200, R201: 0; R_0402; LCSC PN C106231
R9: 1.3K 1%; R_0402; LCSC PN C185455
R10, R196: 2K 1%; R_0402; LCSC PN C60488
R11, R193: 10K 1%; R_0402; LCSC PN C60490
R12: 10.7K 1%; R_0402; LCSC PN C270654
R194, R195: 26.1K 1%; R_0402; LCSC PN C155697
R197: 100K; R_0402; LCSC PN C60491
R198: 1MEG; R_0402; LCSC PN C138033
R199: 330K; R_0402; LCSC PN c138006
R202: 4.7K; R_0201_0603Metric; LCSC PN C138135
R203: 1K; R_0402; LCSC PN C106235
U21: NC7WZ07P6X; MPN NC7WZ07P6X; LCSC PN C95342
U25: TPS2051BDBVR; DBV0005A_L; LCSC PN C24593
U26: TUSB1210BRHBT; RHB32_3P45X3P45; LCSC PN C2671015
U30: TPD4E05U06DQAR; IC_TPD4E05U06DQAR; PARTREV N; LCSC PN C138714
U36: AD8592ARM; RM_10_ADI
Y4: ABM8G-26.000MHZ-18-D2Y-T; CRYSTAL_ABM8G_ABR; LCSC PN C1985426

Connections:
+3V3: C184.2, C187.2, U26.20 (VDD33), U26.21 (VBAT), Y4.1, Y4.4 (VDD); also elsewhere on the board
+5V: C186.2, U25.5 (IN); also elsewhere on the board
AUD_PWM: U21.1 (A1); also elsewhere on the board
AUD_SD: U36.5, U36.6; also elsewhere on the board
AVCC3V3: C1.1, C2.1, R9.2, U21.5 (VCC), U36.10 (V+); also elsewhere on the board
GNDREF: C1.2, C2.2, C3.2, C52.1, C177.2, C180.2, C184.1, C185.1, C186.1, C187.1, C188.1, C189.1, C190.1, C191.1, J9.1, J15.04 (GND), R10.2, R193.1, R196.1, R197.2, R198.2, R199.2, R202.1, U21.2 (GND), U25.2 (GND), U26.23 (ID), U26.33 (EPAD), U26.V, U30.3 (GND), U30.8 (GND), U30.10 (NC_10), U36.4 (V-), Y4.2 (GND); also elsewhere on the board
unnamed: C175.1, R11.2, R12.1
unnamed: C175.2, R16.2, R194.2, U36.1
unnamed: C178.1, R194.1, R195.2
unnamed: C179.2, F2.1, R196.2
unnamed: C182.1, C183.1, CR3.2, Q10.1, R199.1, R200.2
unnamed: F2.2, J9.2
unnamed: J9.3, R197.1
unnamed: R3.2, R9.1, R10.1, R11.1
unnamed: R201.1, Y4.3
unnamed: R3.1, U21.6 (Y1)
unnamed: R202.2, U25.4 (EN), U26.17 (CPEN)
unnamed: C188.2, U26.12 (VDD15)
unnamed: C3.1, R12.2, U36.3 (+)
unnamed: R16.1, R193.2, U36.2 (-)
unnamed: C177.1, R195.1, U36.7 (+)
unnamed: C178.2, C179.1, U36.8 (-), U36.9
USBHOST_CLK: U26.26 (CLOCK); also elsewhere on the board
USBHOST_DATA0: U26.3 (DATA0); also elsewhere on the board
USBHOST_DATA1: U26.4 (DATA1); also elsewhere on the board
USBHOST_DATA2: U26.5 (DATA2); also elsewhere on the board
USBHOST_DATA3: U26.6 (DATA3); also elsewhere on the board
USBHOST_DATA4: U26.7 (DATA4); also elsewhere on the board
USBHOST_DATA5: U26.9 (DATA5); also elsewhere on the board
USBHOST_DATA6: U26.10 (DATA6); also elsewhere on the board
USBHOST_DATA7: U26.13 (DATA7); also elsewhere on the board
USBHOST_DIR: U26.31 (DIR); also elsewhere on the board
USBHOST_N: J15.02 (D-), U26.19 (DM), U30.2 (D1-)
USBHOST_NXT: U26.2 (NXT); also elsewhere on the board
USBHOST_OC: U25.3 (OC_N); also elsewhere on the board
USBHOST_P: J15.03 (D+), U26.18 (DP), U30.1 (D1+)
USBHOST_RCLK: R201.2, U26.1 (REFCLK)
USBHOST_RESETN: R203.1, U26.27 (RESETB); also elsewhere on the board
USBHOST_STP: U26.29 (STP); also elsewhere on the board
USBHOST_VBUS: C180.1, C183.2, C185.2, J15.01 (VCC), Q10.3, U26.22 (VBUS), U30.4 (D2+)
USB_SHIELD: C52.2, J15.S1 (SHIELD), J15.S2 (SHIELD__1), R198.1
USB_VCC5V0: C182.2, CR3.1, Q10.2, R200.1, U25.1 (OUT)
VCC1V8_IO: C189.2, C190.2, C191.2, R203.2, U26.11 (CS), U26.14 (CFG), U26.28 (VDD18), U26.30 (VDD18), U26.32 (VDDIO); also elsewhere on the board

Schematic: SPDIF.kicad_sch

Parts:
C10, C11: 100nF 10V; C_0402; LCSC PN C77020
L1: 47uH; IND_TAIYO_CBC2012_TAY; Tolerance ±10%; Part SDFL2012T220KTF; LCSC C32375
R52: 5.6K; R_0402; LCSC PN C163457
U5: TOTX1950AF; TOTX1950AF_TOS
U6: TORX1950AF; TORX1950AF_TOS

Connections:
+3V3: C10.2, C11.2, L1.2, R52.2, U5.3 (VCC); also elsewhere on the board
GNDREF: C10.1, C11.1, U5.1 (GND), U6.2 (GND1), U6.4 (GND2), U6.5 (CASE), U6.6 (CASE); also elsewhere on the board
unnamed: R52.1, U5.2 (RES_LED)
unnamed: L1.1, U6.3 (VCC)
SPDIF_RX: U6.1 (OUTPUT); also elsewhere on the board
SPDIF_TX: U5.4 (INPUT); also elsewhere on the board

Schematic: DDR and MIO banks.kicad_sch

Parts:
BTNR1: PTS645SK50SMTR92LFS; SW_PTS645SK50SMTR92LFS; LCSC PN C221872
C4, C9, C176: 100nF; C_0201_0603Metric; LCSC PN c307380
C5, C8: 10nF; C_0201_0603Metric; LCSC PN c85930
J4: Conn_01x04_Pin; PinHeader_1x04_P2.54mm_Vertical
J5, J8: Conn_01x02_Pin; PinHeader_1x02_P2.54mm_Vertical
R4, R8, R234, R235, R236, R237, R238, R239: 40.2 1%; R_0402; LCSC PN C274892
R5: 100 1%; R_0402; LCSC PN C106232
R6, R7: 80.6 1%; R_0402; LCSC PN C843839
R17, R18, R19, R20, R43, R45: 10K 1%; R_0402; LCSC PN C60490
R36, R37, R38, R40, R42, R48, R49: 20K 1%; R_0402; LCSC PN C93942
R39, R41, R46, R47: 1K; R_0402; LCSC PN C106235
R44: 200; R_0402; LCSC PN C114764
R50: 49.9; R_0402; LCSC PN C87044
U1: XC7Z020-1CLG400I__; CLG400_ZYNQ-7000_AMD; LCSC PN C1519081
U23: NC7WZ07P6X; MPN NC7WZ07P6X; LCSC PN C95342
Y2: SG-8018CE_50.0000M-TJHPA; OSC_SG-8018CE_50.0000M-TJHPA; PARTREV 5/22/24; LCSC PN C390511

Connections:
+1V5: R7.1, R17.1; also elsewhere on the board
+3V3: C9.1, C176.1, J4.4, J5.2, J8.2, R36.1, R45.2, R46.2, U23.5 (VCC), Y2.1 (OE), Y2.4 (VCC); also elsewhere on the board
CK_RST: R45.1, U1.D9 (PS_MIO12_500), U23.4 (Y2)
DDR3_A0: U1.N2 (PS_DDR_A0_502); also elsewhere on the board
DDR3_A1: U1.K2 (PS_DDR_A1_502); also elsewhere on the board
DDR3_A2: U1.M3 (PS_DDR_A2_502); also elsewhere on the board
DDR3_A3: U1.K3 (PS_DDR_A3_502); also elsewhere on the board
DDR3_A4: U1.M4 (PS_DDR_A4_502); also elsewhere on the board
DDR3_A5: U1.L1 (PS_DDR_A5_502); also elsewhere on the board
DDR3_A6: U1.L4 (PS_DDR_A6_502); also elsewhere on the board
DDR3_A7: U1.K4 (PS_DDR_A7_502); also elsewhere on the board
DDR3_A8: U1.K1 (PS_DDR_A8_502); also elsewhere on the board
DDR3_A9: U1.J4 (PS_DDR_A9_502); also elsewhere on the board
DDR3_A10: U1.F5 (PS_DDR_A10_502); also elsewhere on the board
DDR3_A11: U1.G4 (PS_DDR_A11_502); also elsewhere on the board
DDR3_A12: U1.E4 (PS_DDR_A12_502); also elsewhere on the board
DDR3_A13: U1.D4 (PS_DDR_A13_502); also elsewhere on the board
DDR3_A14: U1.F4 (PS_DDR_A14_502); also elsewhere on the board
DDR3_BA0: U1.L5 (PS_DDR_BA0_502); also elsewhere on the board
DDR3_BA1: U1.R4 (PS_DDR_BA1_502); also elsewhere on the board
DDR3_BA2: U1.J5 (PS_DDR_BA2_502); also elsewhere on the board
DDR3_CAS: U1.P5 (PS_DDR_CAS_B_502); also elsewhere on the board
DDR3_CKE0: U1.N3 (PS_DDR_CKE_502); also elsewhere on the board
DDR3_CK_N: R5.2, U1.M2 (PS_DDR_CKN_502); also elsewhere on the board
DDR3_CK_P: R5.1, U1.L2 (PS_DDR_CKP_502); also elsewhere on the board
DDR3_CS: U1.N1 (PS_DDR_CS_B_502); also elsewhere on the board
DDR3_D0: U1.E2 (PS_DDR_DQ8_502); also elsewhere on the board
DDR3_D1: U1.G3 (PS_DDR_DQ10_502); also elsewhere on the board
DDR3_D2: U1.E3 (PS_DDR_DQ9_502); also elsewhere on the board
DDR3_D3: U1.H1 (PS_DDR_DQ14_502); also elsewhere on the board
DDR3_D4: U1.H3 (PS_DDR_DQ11_502); also elsewhere on the board
DDR3_D5: U1.J1 (PS_DDR_DQ15_502); also elsewhere on the board
DDR3_D6: U1.H2 (PS_DDR_DQ13_502); also elsewhere on the board
DDR3_D7: U1.J3 (PS_DDR_DQ12_502); also elsewhere on the board
DDR3_D8: U1.E1 (PS_DDR_DQ7_502); also elsewhere on the board
DDR3_D9: U1.C3 (PS_DDR_DQ0_502); also elsewhere on the board
DDR3_D10: U1.D3 (PS_DDR_DQ4_502); also elsewhere on the board
DDR3_D11: U1.A2 (PS_DDR_DQ2_502); also elsewhere on the board
DDR3_D12: U1.C1 (PS_DDR_DQ6_502); also elsewhere on the board
DDR3_D13: U1.A4 (PS_DDR_DQ3_502); also elsewhere on the board
DDR3_D14: U1.D1 (PS_DDR_DQ5_502); also elsewhere on the board
DDR3_D15: U1.B3 (PS_DDR_DQ1_502); also elsewhere on the board
DDR3_DM0: U1.F1 (PS_DDR_DM1_502); also elsewhere on the board
DDR3_DM1: U1.A1 (PS_DDR_DM0_502); also elsewhere on the board
DDR3_DQS0_N: U1.F2 (PS_DDR_DQS_N1_502); also elsewhere on the board
DDR3_DQS0_P: U1.G2 (PS_DDR_DQS_P1_502); also elsewhere on the board
DDR3_DQS1_N: U1.B2 (PS_DDR_DQS_N0_502); also elsewhere on the board
DDR3_DQS1_P: U1.C2 (PS_DDR_DQS_P0_502); also elsewhere on the board
DDR3_ODT0: U1.N5 (PS_DDR_ODT_502); also elsewhere on the board
DDR3_RAS: U1.P4 (PS_DDR_RAS_B_502); also elsewhere on the board
DDR3_RESET: U1.B4 (PS_DDR_DRST_B_502); also elsewhere on the board
DDR3_VREF: C4.1, C5.1, R17.2, R20.1, U1.H6 (PS_DDR_VREF0_502), U1.P6 (PS_DDR_VREF1_502); also elsewhere on the board
DDR3_WE: U1.M5 (PS_DDR_WE_B_502); also elsewhere on the board
ETH_INT_B: U1.E9 (PS_MIO10_500); also elsewhere on the board
ETH_MDC: U1.C10 (PS_MIO52_501); also elsewhere on the board
ETH_MDIO: U1.C11 (PS_MIO53_501); also elsewhere on the board
ETH_RST_B: U1.B5 (PS_MIO9_500); also elsewhere on the board
ETH_RXCK: U1.B17 (PS_MIO22_501); also elsewhere on the board
ETH_RXCTL: U1.D13 (PS_MIO27_501); also elsewhere on the board
ETH_RXD0: U1.D11 (PS_MIO23_501); also elsewhere on the board
ETH_RXD1: U1.A16 (PS_MIO24_501); also elsewhere on the board
ETH_RXD2: U1.F15 (PS_MIO25_501); also elsewhere on the board
ETH_RXD3: U1.A15 (PS_MIO26_501); also elsewhere on the board
ETH_TXCLK: R239.2; also elsewhere on the board
ETH_TXCTL: R235.2; also elsewhere on the board
ETH_TXD0: R234.2; also elsewhere on the board
ETH_TXD1: R236.2; also elsewhere on the board
ETH_TXD2: R237.2; also elsewhere on the board
ETH_TXD3: R238.2; also elsewhere on the board
GNDREF: BTNR1.3, C4.2, C5.2, C8.2, C9.2, C176.2, J4.2, R6.1, R19.2, R20.2, R37.1, R38.1, R39.1, R41.1, R47.1, U23.2 (GND), Y2.2 (GND); also elsewhere on the board
unnamed: BTNR1.1, R44.1
unnamed: J4.1, R46.1, R48.2
unnamed: J4.3, R47.2, R49.2
unnamed: J5.1, R39.2, R40.1
unnamed: J8.1, R41.2, R42.1
unnamed: R7.2, U1.G5 (PS_DDR_VRN_502)
unnamed: R6.2, U1.H5 (PS_DDR_VRP_502)
unnamed: R239.1, U1.A19 (PS_MIO16_501)
unnamed: R234.1, U1.E14 (PS_MIO17_501)
unnamed: R236.1, U1.B18 (PS_MIO18_501)
unnamed: R237.1, U1.D10 (PS_MIO19_501)
unnamed: R238.1, U1.A17 (PS_MIO20_501)
unnamed: R235.1, U1.F14 (PS_MIO21_501)
unnamed: R8.1, U1.D14 (PS_MIO40_501)
unnamed: R4.1, U1.A5 (PS_MIO6_500)
unnamed: R50.2, Y2.3 (OUT)
PS_CLK: R50.1, U1.E7 (PS_CLK_500)
PS_POR_B: U1.C7 (PS_POR_B_500); also elsewhere on the board
PS_RST: R43.2, R44.2, U1.B10 (PS_SRST_B_501), U23.3 (A2)
SD_CCLK: R8.2; also elsewhere on the board
SD_CD: U1.B14 (PS_MIO47_501); also elsewhere on the board
SD_CMD: U1.C17 (PS_MIO41_501); also elsewhere on the board
SD_D0: U1.E12 (PS_MIO42_501); also elsewhere on the board
SD_D1: U1.A9 (PS_MIO43_501); also elsewhere on the board
SD_D2: U1.F13 (PS_MIO44_501); also elsewhere on the board
SD_D3: U1.B15 (PS_MIO45_501); also elsewhere on the board
SPI_CS: U1.A7 (PS_MIO1_500); also elsewhere on the board
SPI_DQ0/MODE3: R40.2, U1.B8 (PS_MIO2_500); also elsewhere on the board
SPI_DQ1/MODE1: R38.2, U1.D6 (PS_MIO3_500); also elsewhere on the board
SPI_DQ2/MODE2: R49.1, U1.B7 (PS_MIO4_500); also elsewhere on the board
SPI_DQ3/MODE0: R48.1, U1.A6 (PS_MIO5_500); also elsewhere on the board
SPI_SCK/MODE4: R4.2, R42.2; also elsewhere on the board
SPI_SCLK_FB/VCFG1: R36.2, U1.D5 (PS_MIO8_500)
UART_RXD_OUT: U1.C8 (PS_MIO15_500); also elsewhere on the board
UART_TXD_IN: U1.C5 (PS_MIO14_500); also elsewhere on the board
USBHOST_CLK: U1.A11 (PS_MIO36_501); also elsewhere on the board
USBHOST_DATA0: U1.A14 (PS_MIO32_501); also elsewhere on the board
USBHOST_DATA1: U1.D15 (PS_MIO33_501); also elsewhere on the board
USBHOST_DATA2: U1.A12 (PS_MIO34_501); also elsewhere on the board
USBHOST_DATA3: U1.F12 (PS_MIO35_501); also elsewhere on the board
USBHOST_DATA4: U1.C16 (PS_MIO28_501); also elsewhere on the board
USBHOST_DATA5: U1.A10 (PS_MIO37_501); also elsewhere on the board
USBHOST_DATA6: U1.E13 (PS_MIO38_501); also elsewhere on the board
USBHOST_DATA7: U1.C18 (PS_MIO39_501); also elsewhere on the board
USBHOST_DIR: U1.C13 (PS_MIO29_501); also elsewhere on the board
USBHOST_NXT: U1.E16 (PS_MIO31_501); also elsewhere on the board
USBHOST_OC: U1.C6 (PS_MIO11_500); also elsewhere on the board
USBHOST_RESETN: U1.D16 (PS_MIO46_501); also elsewhere on the board
USBHOST_STP: U1.C15 (PS_MIO30_501); also elsewhere on the board
VCC1V8_IO: R18.1, R43.1; also elsewhere on the board
VCFG0: R37.2, U1.D8 (PS_MIO7_500)
VREF0V9: C8.1, R18.2, R19.1, U1.E11 (PS_MIO_VREF_501)

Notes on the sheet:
VCC1V5
VCC1V8_IO
VCC3V3

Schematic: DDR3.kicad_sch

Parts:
C34, C35: 10nF; C_0201_0603Metric; LCSC PN c85930
C36, C37, C38, C39, C40, C41, C42, C43, C44, C45, C46, C47, C48, C49, C50, C51: 47nF; C_0201_0603Metric; LCSC PN C88917
C82, C83: 470nF; C_0201_0603Metric; LCSC PN C5383023
C84: 4.7uF; C_0402; LCSC PN C2858031
IC1: IS43TR16256B-125KBLI; BGA96C80P9X16_900X1300X120; Mouser_Part_Number 870-43T16256B125KBLI
R95: 240 1%; R_0402; LCSC PN C114755
R96: 4.7K; R_0201_0603Metric; LCSC PN C138135

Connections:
+1V5: C34.1, C36.1, C37.1, C38.1, C39.1, C40.1, C41.1, C42.1, C43.1, C44.1, C45.1, C46.1, C47.1, C48.1, C49.1, C50.1, C51.1, C82.1, C83.1, C84.1, IC1.A1 (VDDQ_1), IC1.A8 (VDDQ_2), IC1.B2 (VDD_1), IC1.C1 (VDDQ_3), IC1.C9 (VDDQ_4), IC1.D2 (VDDQ_5), IC1.D9 (VDD_2), IC1.E9 (VDDQ_6), IC1.F1 (VDDQ_7), IC1.G7 (VDD_3), IC1.H2 (VDDQ_8), IC1.H9 (VDDQ_9), IC1.K2 (VDD_4), IC1.K8 (VDD_5), IC1.N1 (VDD_6), IC1.N9 (VDD_7), IC1.R1 (VDD_8), IC1.R9 (VDD_9); also elsewhere on the board
DDR3_A0: IC1.N3 (A0); also elsewhere on the board
DDR3_A1: IC1.P7 (A1); also elsewhere on the board
DDR3_A2: IC1.P3 (A2); also elsewhere on the board
DDR3_A3: IC1.N2 (A3); also elsewhere on the board
DDR3_A4: IC1.P8 (A4); also elsewhere on the board
DDR3_A5: IC1.P2 (A5); also elsewhere on the board
DDR3_A6: IC1.R8 (A6); also elsewhere on the board
DDR3_A7: IC1.R2 (A7); also elsewhere on the board
DDR3_A8: IC1.T8 (A8); also elsewhere on the board
DDR3_A9: IC1.R3 (A9); also elsewhere on the board
DDR3_A10: IC1.L7 (A10/AP); also elsewhere on the board
DDR3_A11: IC1.R7 (A11); also elsewhere on the board
DDR3_A12: IC1.N7 (A12/BC#); also elsewhere on the board
DDR3_A13: IC1.T3 (A13); also elsewhere on the board
DDR3_A14: IC1.T7 (A14); also elsewhere on the board
DDR3_BA0: IC1.M2 (BA0); also elsewhere on the board
DDR3_BA1: IC1.N8 (BA1); also elsewhere on the board
DDR3_BA2: IC1.M3 (BA2); also elsewhere on the board
DDR3_CAS: IC1.K3 (CAS#); also elsewhere on the board
DDR3_CKE0: IC1.K9 (CKE); also elsewhere on the board
DDR3_CK_N: IC1.K7 (CK#); also elsewhere on the board
DDR3_CK_P: IC1.J7 (CK); also elsewhere on the board
DDR3_CS: IC1.L2 (CS#); also elsewhere on the board
DDR3_D0: IC1.E3 (DQL0); also elsewhere on the board
DDR3_D1: IC1.F7 (DQL1); also elsewhere on the board
DDR3_D2: IC1.F2 (DQL2); also elsewhere on the board
DDR3_D3: IC1.F8 (DQL3); also elsewhere on the board
DDR3_D4: IC1.H3 (DQL4); also elsewhere on the board
DDR3_D5: IC1.H8 (DQL5); also elsewhere on the board
DDR3_D6: IC1.G2 (DQL6); also elsewhere on the board
DDR3_D7: IC1.H7 (DQL7); also elsewhere on the board
DDR3_D8: IC1.D7 (DQU0); also elsewhere on the board
DDR3_D9: IC1.C3 (DQU1); also elsewhere on the board
DDR3_D10: IC1.C8 (DQU2); also elsewhere on the board
DDR3_D11: IC1.C2 (DQU3); also elsewhere on the board
DDR3_D12: IC1.A7 (DQU4); also elsewhere on the board
DDR3_D13: IC1.A2 (DQU5); also elsewhere on the board
DDR3_D14: IC1.B8 (DQU6); also elsewhere on the board
DDR3_D15: IC1.A3 (DQU7); also elsewhere on the board
DDR3_DM0: IC1.E7 (DML); also elsewhere on the board
DDR3_DM1: IC1.D3 (DMU); also elsewhere on the board
DDR3_DQS0_N: IC1.G3 (DQSL#); also elsewhere on the board
DDR3_DQS0_P: IC1.F3 (DQSL); also elsewhere on the board
DDR3_DQS1_N: IC1.B7 (DQSU#); also elsewhere on the board
DDR3_DQS1_P: IC1.C7 (DQSU); also elsewhere on the board
DDR3_ODT0: IC1.K1 (ODT); also elsewhere on the board
DDR3_RAS: IC1.J3 (RAS#); also elsewhere on the board
DDR3_RESET: IC1.T2 (RESET#), R96.1; also elsewhere on the board
DDR3_VREF: C34.2, C35.1, IC1.H1 (VREFDQ), IC1.M8 (VREFCA); also elsewhere on the board
DDR3_WE: IC1.L3 (WE#); also elsewhere on the board
GNDREF: C35.2, C36.2, C37.2, C38.2, C39.2, C40.2, C41.2, C42.2, C43.2, C44.2, C45.2, C46.2, C47.2, C48.2, C49.2, C50.2, C51.2, C82.2, C83.2, C84.2, IC1.A9 (VSS_1), IC1.B1 (VSSQ_1), IC1.B3 (VSS_2), IC1.B9 (VSSQ_2), IC1.D1 (VSSQ_3), IC1.D8 (VSSQ_4), IC1.E1 (VSS_3), IC1.E2 (VSSQ_5), IC1.E8 (VSSQ_6), IC1.F9 (VSSQ_7), IC1.G1 (VSSQ_8), IC1.G8 (VSS_4), IC1.G9 (VSSQ_9), IC1.J2 (VSS_5), IC1.J8 (VSS_6), IC1.M1 (VSS_7), IC1.M9 (VSS_8), IC1.P1 (VSS_9), IC1.P9 (VSS_10), IC1.T1 (VSS_11), IC1.T9 (VSS_12), R95.2, R96.2; also elsewhere on the board
unnamed: IC1.L8 (ZQ), R95.1

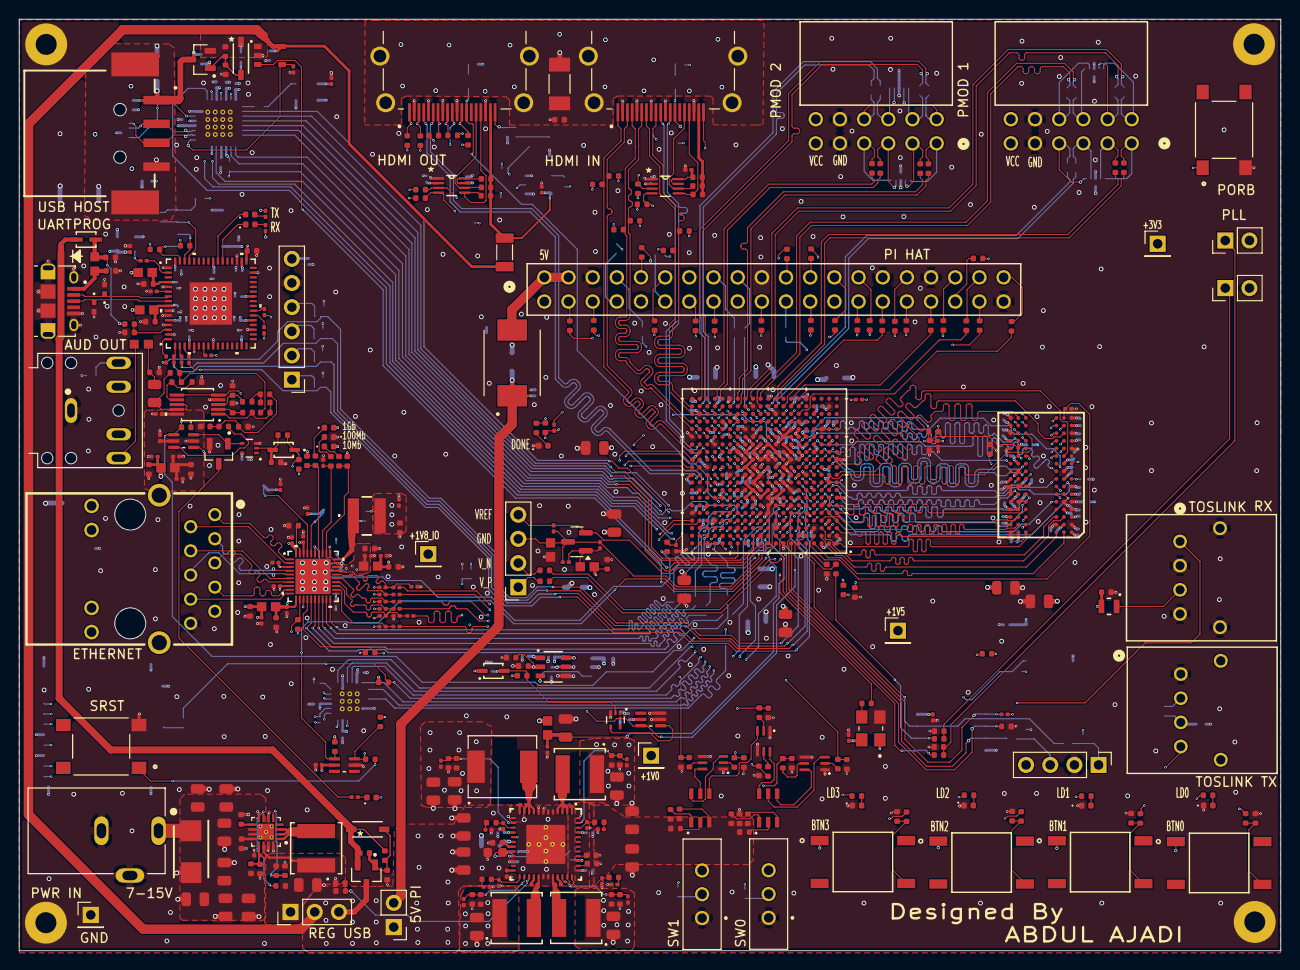
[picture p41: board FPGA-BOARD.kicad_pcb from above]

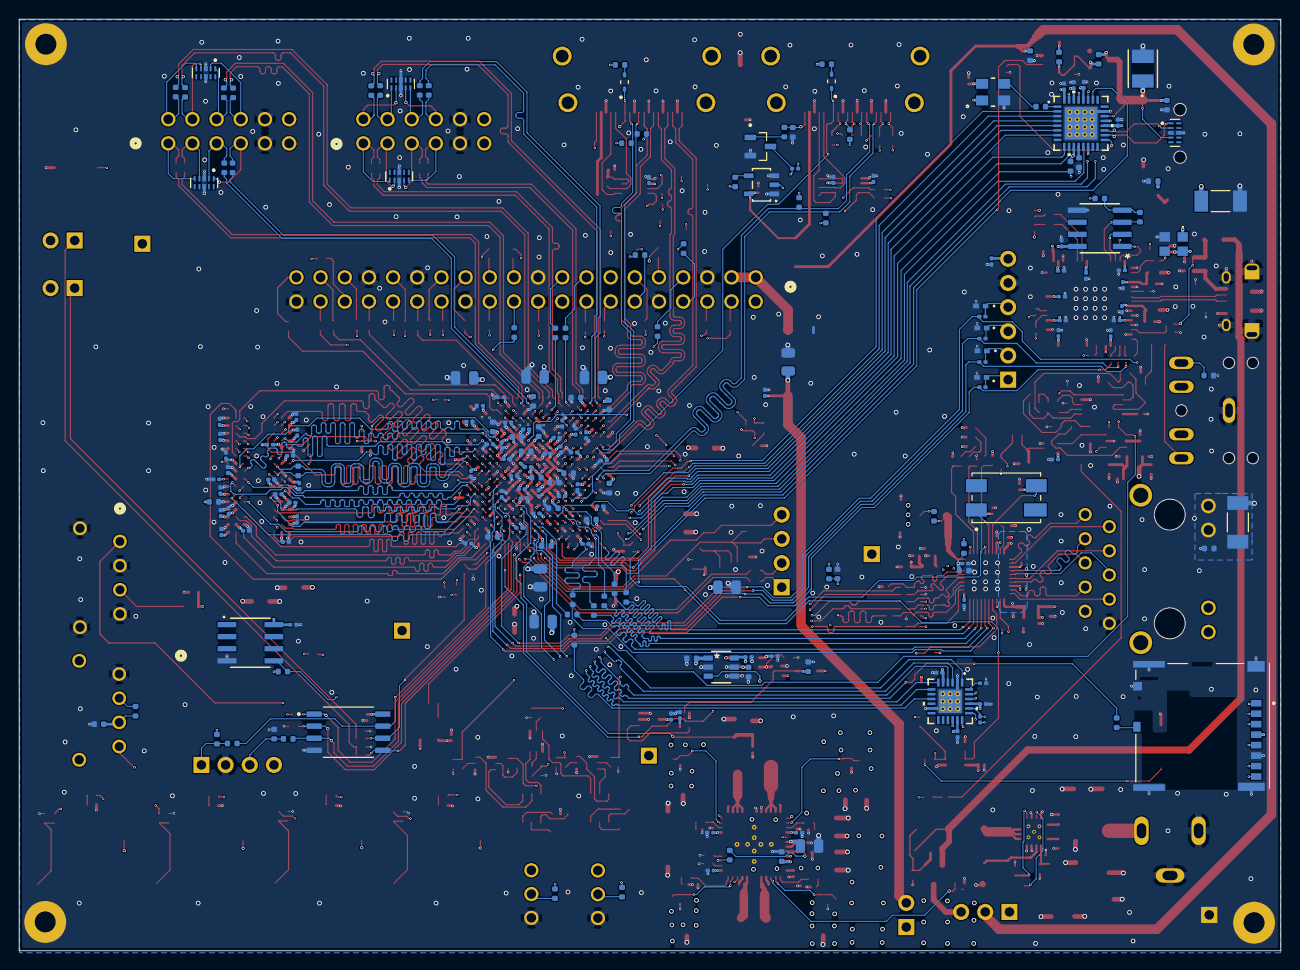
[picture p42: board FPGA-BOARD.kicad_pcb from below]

Board: 8 copper layers, 132.6 x 97.9 mm, 593 parts (207 on the bottom side), 463 nets.

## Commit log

2025-02-17 initial commit of fpga-board
    [FPGA-BOARDver2.kicad_pcb, FPGA-BOARDver2.kicad_sch, PAGE02_board_connector.kicad_sch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]
2025-02-17 ki-cad files
2025-02-17 reset repository
    [FPGA-BOARDver2.kicad_pcb, FPGA-BOARDver2.kicad_sch, PAGE02_board_connector.kicad_sch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]
2025-02-17 kicad schmatic files
2025-02-17 ki-cad schematic ver 3
    [FPGA-BOARDver3.kicad_pcb, FPGA-BOARDver3.kicad_sch, PAGE02_board_connector.kicad_sch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]
2025-02-27 added Arty pmod, useri/o
    [FPGA-BOARDver3.kicad_sch, untitled.kicad_sch]
2025-02-27 updated file name for PMOD, USER I/O
    [FPGA-BOARDver3.kicad_sch, PMOD,LED,SWITCHES.kicad_sch]
2025-03-05 power regulation schematic added
    [FPGA-BOARDver3.kicad_sch, PMOD,LED,SWITCHES.kicad_sch, power_regulation.kicad_sch]
2025-03-16 DDR3 Schematic sheet added
    [DDR3.kicad_sch, FPGA-BOARDver3.kicad_sch, POWER_REGULATION2.kicad_sch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]
2025-03-17 Added FPGA-POWER Schematic
    [DDR3.kicad_sch, FPGA-BOARDver3.kicad_sch, FPGA_POWER.kicad_sch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]
2025-03-18 Power Regulation sheet 2 added
    [FPGA-BOARDver3.kicad_sch, FPGA_POWER.kicad_sch, POWER_REGULATION2.kicad_sch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]
2025-03-18 removed old reference design
    [PAGE02_board_connector.kicad_sch, PAGE03_jtag.kicad_sch, PAGE04_sd_card_uart.kicad_sch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]
2025-03-18 added xc7z020-1clg400i symbol and footprint
2025-03-23 assigned footprints for power section and ddr3
    [DDR3.kicad_sch, FPGA_POWER.kicad_sch, PMOD,LED,SWITCHES.kicad_sch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]
2025-03-23 footprints added to project specific library
    [DDR3.kicad_sch, FPGA_POWER.kicad_sch, PMOD,LED,SWITCHES.kicad_sch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]
2025-03-25 added symbol and footprint folders for common components in schematics
    [BLM18AG601SZ1D.step, DDR3.kicad_sch, FDV301N.step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]
2025-03-31 added fpga banks and final fpga symbol
    [DDR and MIO banks.kicad_sch, FDV301N.step, FPGA-BOARDver3.kicad_sch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]
2025-04-07 spdif fpga bansks
    [DDR and MIO banks.kicad_sch, FPGA-BOARDver3.kicad_sch, FPGA_Banks_Anti_Alias_Filters.kicad_sch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]
2025-04-10 All pages complete , pi header left
    [DDR and MIO banks.kicad_sch, ETHERNET.kicad_sch, FPGA-BOARDver3.kicad_sch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]
2025-04-11 schematic pages for review
    [DDR and MIO banks.kicad_sch, FPGA_Banks_Anti_Alias_Filters.kicad_sch, PI_HEADER.kicad_sch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]
2025-04-11 Schematic update for review
    [FPGA_Banks_Anti_Alias_Filters.kicad_sch]
2025-04-13 added audio out and usb
    [AUDIO.kicad_sch, DDR and MIO banks.kicad_sch, DDR3.kicad_sch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]
2025-09-09 updated schematic and layout
    [10029449-001RLF.step, 10118194-0001LF.step, 503398-1892.step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]
2025-11-05 new layout by abdul
    [AUDIO.kicad_sch, C_0201_0603Metric.step, DCU0008A.stp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]
2025-11-10 hdmi,pmod raspberrypi gpio, led fanout first draft done
2025-11-17 weekend update
    [ETHERNET.kicad_sch, PMOD,LED,SWITCHES.kicad_sch]
2025-11-18 update before kicad ver9 download
2025-12-17 ready for manufacturing
    [AUDIO.kicad_sch, CG0402MLU-3.3G.stp, DCY0004A.stp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]
2026-01-01 Add 3D board render
2026-08-08 post -production rework
    [ABMM-25.000MHZ-B2-T.stp, AUDIO.kicad_sch, DDR and MIO banks.kicad_sch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]
2026-08-08 post production update
    [10029449-001RLF.step, 10118194-0001LF.step, 503398-1892.step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]
2026-09-05 KICAD 10 DRC fixes
    [FPGA-BOARD.kicad_pcb]
